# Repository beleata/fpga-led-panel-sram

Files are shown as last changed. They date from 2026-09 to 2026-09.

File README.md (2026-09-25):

# ICND1065L LED Panel: FPGA SRAM and RP2040 Pico

64x32 ICND1065L RGB LED panel drivers: Olimex iCE40HX1K FPGA with SRAM video
memory, and a YD-RP2040 / Raspberry Pi Pico PIO + DMA display implementation
with USB frame streaming. Wiring, initialization protocol, source, tests and
ready-to-flash firmware are included.

## Custom Controller PCB (Draft)

Самостоятелна двуслойна платка **88 x 46.1 mm** с RP2040, 8 MiB flash,
вертикална USB-C, RS-485 и W5500 Ethernet с вертикална RJ45.

**НЕ Е ГОТОВА ЗА ПРОИЗВОДСТВО.** Публикувани са схемата, 103 компонента,
ръчната подредба и пробно трасиране. След корекциите: 0 DRC нарушения,
но остава 1 неопроводена връзка QSPI_D1. Сигналната цялост и захранването
още не са квалифицирани. Това не променя статуса на работещия Pico модул.

- [PCB files, current status and documentation](hardware/pico-panel/README.md)
- [Пробно трасиране и ограничения](hardware/pico-panel/routing-trial/README_BG.md)

## RP2040 Pico

Потвърден работещ вариант с **YD-RP2040 2022-V1.3, 8 MiB flash**:
правилна геометрична фигура и стабилна картина. PIO и DMA изпълняват
проверената FPGA последователност при SCLK **1.5625 MHz**.

- [Свързване, компилиране и инструкции](pico/README_BG.md)
- [Готов firmware за YD-RP2040 8 MiB](pico/pico_panel.uf2)
- [Изходен код и тестове](pico/)

Добавен е USB CDC приемник с два RGB888 буфера във вътрешната SRAM на Pico.
PC декодира GIF и изпраща кадрите; Pico пази последния кадър при спиране
на изпращането. [USB видео: инструкции и протокол](pico/USB_VIDEO_BG.md).
Новият [USB firmware](pico/pico_panel_usb.uf2) е отделен от стария статичен UF2.
Измерени са 13,49 кадъра/s при 70 последователни кадъра, без PIO/DMA грешки;
визуалната проверка на новата анимация предстои.

## FPGA SRAM

Работещ проект за **Olimex iCE40HX1K-EVB**, RGB LED панел **64 x 32** с
ICND1065L драйвери и външна SRAM видео памет. Изображенията се изпращат от
компютър през OLIMEXINO-32U4 по UART **2 Mbaud**. Два SRAM буфера, CRC16 и
проверка чрез прочит след запис пазят активната картина при недовършен или
повреден пакет. Последната приета картина се показва без допълнителен трафик.

## Потвърдено На Реален Хардуер

- Правилна геометрия, цветове и стабилна статична картина.
- Приемане и показване на изображение от външния SRAM.
- Отхвърляне на грешна CRC и непълен кадър; безопасно повторение на пакет.
- Шест различни кадъра, 18 успешни прехвърляния: **3.16 кадъра/секунда**
  през текущия USB мост. Това не е физическият максимум на UART/SRAM.
- Потребителят потвърди картината и поиска непрекъсната анимация.

Проверки, хешове и ограничения: [video/VERIFICATION.md](video/VERIFICATION.md).
SRAM е енергозависима: след изключване или FPGA reset се връща началната
геометрична фигура, а не последният изпратен потребителски кадър.

## Бърз Старт

Текущата среда е Windows/PowerShell, Python 3.13, OSS CAD Suite в
`C:\oss-cad-suite`, Arduino AVR core 1.8.8. Инсталирайте Python зависимостите:

```powershell
python -m pip install -r requirements.txt
.\video\test.ps1
.\video\build.ps1
python program_panel.py video/video.bin --port COM18
python video/send_image.py --image C:\images\picture.png --port COM18
```

Картинката е 64 x 32; `--resize` разрешава преоразмеряване, `--rotate 180`
обръща изображението. Пиновете и безопасното свързване са описани в
[video/README_BG.md](video/README_BG.md). Не свързвайте 5 V към FPGA GPIO.
OLIMEXINO трябва да използва 3.3 V логически нива. GPIO1 пин 34 **не е земя**.
`HARDWARE.md` е историческа бележка и съдържа стари предположения; водещи
са актуалната документация, `.pcf` файловете и потвърдените резултати.

Анимация и спиране след текущия кадър:

```powershell
python video/animate.py --cycles 3
.\video\start_animation.ps1
.\video\stop_animation.ps1
```

Фоновата анимация държи COM18 отворен. Спрете я преди друга команда към
платката. Изпращането на изображения не презаписва FPGA flash.

## Съдържание

| Път | Предназначение |
|---|---|
| `video/` | Текущ SRAM драйвер, UART протокол, клиенти, тестове и bitstream |
| `pico/` | Потвърден RP2040 PIO/DMA статичен драйвер, UF2, свързване и тестове |
| `panel/` | Потвърдена стабилна статична версия за възстановяване |
| `link_test/` | UART диагностика и измервания на скоростта |
| `programmer-fw/` | OLIMEXINO USB/SPI/UART програматор и готов firmware |
| `backups/` | Работещи етапи, резервни копия и хешове |
| `logs/` | Запазени резултати от синтез, програмиране и тестове |
| `reference/` | Външни източници, фиксирани като Git submodules |
| `PANEL_PROTOCOL_BG.md` | Подробен протокол за управление на ICND1065L |
| `program_panel.py` | Двоен backup read, запис, проверка и CDONE |
| `iceprog.py` | Клиент за USB протокола на програматора |

Архивите `stable-panel-20260924.zip` и `video-sram-20260924.zip` пазят
самостоятелни работещи снимки на проекта. Текущите файлове извън архивите
може да съдържат по-нови помощни скриптове и документация.

## Референтни Източници

При клониране използвайте `git clone --recurse-submodules <repository-url>`.
За вече клонирано хранилище: `git submodule update --init --recursive`.
Основният FPGA build не изисква компилация на тези референтни проекти.

- [board707/DMD_STM32](https://github.com/board707/DMD_STM32),
  commit `398ec1d8636bce866709fbe9c3f0035c90645e7a`.
- [OLIMEX/iCE40HX1K-EVB](https://github.com/OLIMEX/iCE40HX1K-EVB),
  commit `91f3b5aff50258ddb40c021a21d4fd871633fc80`.
- [kingdo9/rpi-rgb-led-matrix_pwm_experiment](https://github.com/kingdo9/rpi-rgb-led-matrix_pwm_experiment),
  commit `5da13cb3b0d38d66bb5201f03704b5bef9e4446b`.

Външните проекти запазват собствените си лицензи и авторство. Това
хранилище не добавя нов общ лиценз върху техния код или хардуерни проекти.

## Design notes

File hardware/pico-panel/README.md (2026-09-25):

# RP2040 ICND1065L Panel Controller PCB

**Development snapshot, 2026-09-25. NOT FOR MANUFACTURE.**

A custom two-layer 88 x 46.1 mm controller for the tested 64 x 32 ICND1065L
LED panel. Bare RP2040, 8 MiB flash, vertical USB-C, non-isolated RS-485,
W5500 Ethernet and a vertical HanRun HR963380AE integrated-magnetics jack.
KiCad 10.0.6 project, 103 components. The custom PCB has not been fabricated
or tested; the working YD-RP2040 module firmware is a separate result.

## Текущо състояние

- Основният `pico-panel.kicad_pcb` е последната ръчна подредба на потребителя,
  без писти. Не е презаписвана от генератора след ръчните корекции.
- `routing-trial/pico-panel.kicad_pcb` е отделно пробно трасиране със същите
  позиции и ориентации. Два слоя, 111 преходни отвора.
- Проверка на подредбата: 0 DRC нарушения, 285 неопроводени връзки.
- Проверка на пробното трасиране след локалните корекции: 0 DRC нарушения,
  **1 неопроводена връзка QSPI_D1: U2.2 към U1.55**.
- ERC на схемата: 0 нарушения. Това не заменя проверката на схемното решение.
- USB/Ethernet диференциалните трасета, земята и обратните токови пътища,
  кварцовите вериги, импулсният регулатор и защитите още изискват преглед.
- Няма производствено одобрение, Gerber release или потвърдени измервания.

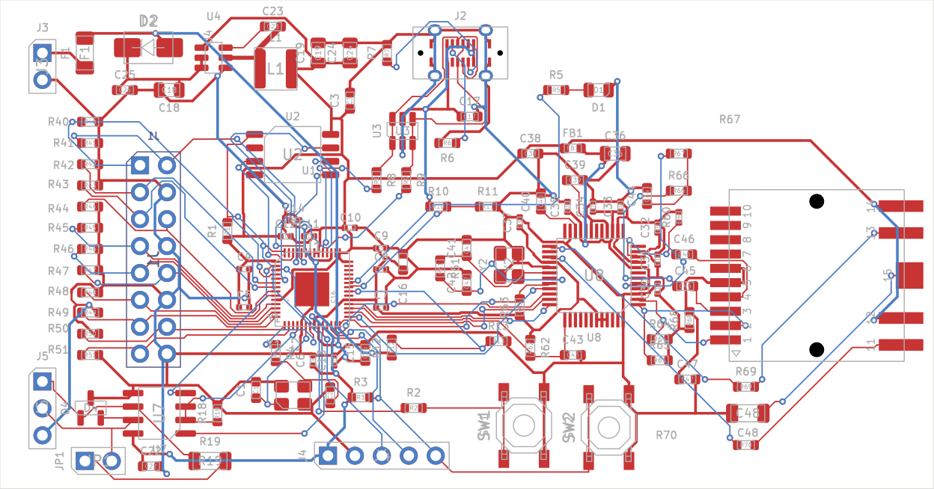
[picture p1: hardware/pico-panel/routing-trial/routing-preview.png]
Пробно трасиране, не производствен вариант


## Файлове

| Файл / папка | Предназначение |
| --- | --- |
| `pico-panel.kicad_pro` | Основен KiCad проект |
| `pico-panel.kicad_sch` | Пълна схема |
| `pico-panel.kicad_pcb` | Запазена ръчна подредба, без писти |
| `Panel.pretty/`, `Panel.kicad_sym` | Локални footprints и символи |
| `parts.json`, `BOM.csv` | Компоненти, LCSC кодове, връзки и текущи позиции |
| `preview/schematic.pdf` | Актуален PDF на схемата |
| `preview/user-placement.png` | Актуална ръчна подредба |
| `routing-trial/` | Двата опита за трасиране, логове, DSN/SES и текущ резултат |
| `reports/` | ERC/DRC, netlist, проверки на конектора и исторически отчети |
| `reference/` | Използвани datasheets, чертежи и публичен CAD на конектора |
| `tools/` | Скриптове за генериране, проверки и обработка на пробния маршрут |

## Механика и свързване

- Размер 88 x 46.1 mm; два медни слоя; зададена дебелина 0.8 mm.
- J1 е женски 2 x 8, 2.54 mm, от долната страна, за ръчно запояване.
- Поглед отгоре: J1.1 е x=13.202, y=15.600 mm от горния ляв ъгъл.
  Пин 2 е вдясно, пин 3 отдолу. Тези координати не са променяни.
- Отделни +5 V/GND проводници захранват контролера от панела.
  USB VBUS не захранва контролера; за програмиране също са нужни панелните 5 V.
- GP2..GP13 са директни 3.3 V сигнали към панела. Буферите и R20..R31 (33 ohm)
  са премахнати по заявка на потребителя; 47 kohm pull-down резисторите остават.
- J3: +5 V/GND; J5: RS-485 A/B/GND. Неполяризирани 2.54 mm конектори.
- Ethernet не е PoE. Схемата е за общата средна точка на конкретния MagJack.

## Отваряне и възпроизвеждане

Клонирайте целия repository и отворете `pico-panel.kicad_pro` с KiCad 10.
Локалните библиотеки използват `${KIPRJMOD}`. За пробния маршрут отворете
директно `routing-trial/pico-panel.kicad_pcb`; той не заменя основната подредба.

Скриптовете са от Windows работната среда. Част от тях съдържат абсолютни
пътища до KiCad, Java и локалния каталог за компоненти; адаптирайте ги преди
стартиране на друга машина. `pcbnew` изисква Python средата на KiCad.

**Не изпълнявайте `build_pcb.py` или `apply_wide_placement.py` върху ръчно
редактирана платка:** те заменят подредбата. Генераторната подредба е по-стара
от последните ръчни корекции. Авторитетен е запазеният `.kicad_pcb` файл.

`routing-trial/README_BG.md` описва границите на теста и локалните корекции.
Скриптовете за миграции/корекции са еднократни операции, не общ build pipeline.

## Документация и история

- [Проектни решения и исторически варианти](DESIGN_BG.md)
- [Проверка на RJ45 footprint](ETHERNET_FOOTPRINT_BG.md)
- [Първоначална механична Ethernet проба](ETHERNET_OPTION_BG.md)
- [Проверен firmware за готовия Pico модул](../../pico/README_BG.md)

По-старите изображения в `preview/` и част от отчетите са от предишни размери
и по-малък брой елементи. Тази страница и текущите основни KiCad файлове
определят актуалното състояние. Локалните crash snapshots, editor lock files,
временни тестови схеми и дублиращи резервни копия не са публикувани.

Изтегленият файл `ABM8-25MHz.pdf` се оказа HTML страница, а не datasheet,
и е изключен от публикацията. Документацията и товарният капацитет на 25 MHz
кварца трябва да бъдат проверени допълнително преди производство.
Datasheets/CAD в `reference/` принадлежат на съответните производители.

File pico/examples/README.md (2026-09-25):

# GIF playback examples

These three user-supplied GIFs are the inputs used for the physical panel tests.
Original authors and redistribution licenses have not been established here;
including them does not grant ownership or a new license to the artwork.

Run from the repository root after installing `requirements.txt` and flashing
`pico/pico_panel_usb.uf2` to the connected YD-RP2040:

```powershell
# Sonic: 32x64 -> 64x32, clockwise rotation, repeat until Ctrl+C
python pico/usb_video.py pico/examples/sonic-finger-ezgif.com-resize.gif --rotate 90 --fit exact --loops 0

# Stop the previous command before starting this playlist.
# Native 64x32 GIFs, alternating every 10 seconds, repeat until Ctrl+C
python pico/usb_video.py --playlist pico/examples/led_matrices_sine_tube.gif pico/examples/led_matrices_ruby_walk.gif --seconds 10 --fit exact --loops 0

# Equivalent hidden background playback on Windows
./pico/start_video.ps1 -Image pico/examples/led_matrices_sine_tube.gif,pico/examples/led_matrices_ruby_walk.gif -Rotate 0 -Seconds 10
./pico/stop_video.ps1
```

Only one sender may hold the Pico COM port at a time. Closing the sender leaves
the last frame displayed while both Pico and the panel remain powered.

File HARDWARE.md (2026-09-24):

# Хардуерна конфигурация

> **Работещ протокол, потвърден на 24.09.2026:** използвайте
> [PANEL_PROTOCOL_BG.md](PANEL_PROTOCOL_BG.md). Геометрията, цветовете и
> непрекъснатото стабилно показване вече са потвърдени на реалния панел.
> Текстът по-долу е исторически: неговите 16 scan реда, четири позиции във
> веригата и импулсно адресиране A/B не описват работещата версия.

> **Проверка от 24.09.2026:** текстът по-долу съдържа непотвърдени предположения.
> GPIO1 пин 34 е сигнал към FPGA пин 24, а не GND. Старият `panel.v` съкращава
> неправилно конфигурационната последователност и броя битове за изображението.
> Текущите проверки, източници и ограничения са описани в [panel/NOTES.md](panel/NOTES.md).

Описание на това, което е на масата: FPGA платката, как се програмира, как е
свързан LED панелът и какво знаем за него. Всичко за пиновете тук е извадено от
нетлиста на платката (`iCE40HX1K-EVB_Rev_B.net`), а не от препис — и е
проверено, че съвпада с ревизия A (`ICE40-1KEVB_Rev_A.net`).

---

## 1. Какво има на масата

| Какво | Модел | Роля |
| --- | --- | --- |
| FPGA платка | Olimex **iCE40HX1K-EVB** | самият компютър / генераторът на картина |
| Програматор | Olimex **OLIMEXINO-32U4** (ATmega32U4, Arduino Leonardo) | записва флаша, а после служи и като USB↔UART мост |
| Кабел | Olimex **CABLE-IDC10-15cm** | PGM1 ↔ UEXT между двете платки |
| Панел | **D-P5(1921)-BS-320X160-1110H** | 64×32 пиксела, драйвери ICND1065L |
| Захранване | отделно 5 V за панела | 2–3 A при пълно бяло |
| USB кабел | към OLIMEXINO-32U4 | от него излиза COM портът |

Панелът **не** се храни от FPGA платката. Земята на двете захранвания трябва да е
обща — без това сигналите няма спрямо какво да се мерят.

---

## 2. FPGA платката (iCE40HX1K-EVB)

Частите, както са в нетлиста:

| Означение | Част | Какво е |
| --- | --- | --- |
| U4 | `ICE40HX1K-VQ100` (VQFP100, 0.5 mm) | FPGA: 1280 логически клетки, 16 BRAM блока |
| U5 | `K6R4016V1D-TC10` (TSOP-44) | външна SRAM, 256K × 16 бита |
| U1 | `W25Q16BVSSIG` (SOIC-8) | конфигурационен флаш, 2 MB, по SPI |
| CR1 | `Oscillator-100MHZ_TXC-7W` | 100 MHz кварцов осцилатор |
| U2 | `SY8009AAAC` (SOT23-5) | импулсен регулатор → **3.3 V** |
| U3 | `SY8009AAAC` (SOT23-5) | импулсен регулатор → **1.2 V** (ядро) |
| GPIO1 | `BH34R` | 34-пинов конектор, 2×17 — тук излизат сигналите |
| PGM1 | `BH10S` | 10-пинов конектор за програмиране |
| LED1, LED2 | — | двете светодиодчета на платката |
| BUT1, BUT2 | — | бутони, на FPGA пинове 41 и 42 |
| CDone1 | — | светодиод за CDONE |
| PWR1, FUSE1, D1 | — | захранващ жак, предпазител, диод |

### Часовникът

Осцилаторът CR1 дава 100 MHz и отива на две места:

- през **R10** → `/SYSCLK` → **FPGA пин 15** — това е входът за такт;
- през **R18** (22 Ω) → **GPIO1 пин 6**, обозначен `EXTCLK` — същият такт излиза
  и на конектора, ако някой ден трябва да се подаде на друга платка.

В `.pcf` файловете това е `set_io CLK 15`. Проектът за компютъра работи на
100 MHz, разделени на 2 (50 MHz), защото аритметиката не затваря на 100.

### Конфигурационният флаш

Флашът U1 виси на същите SPI линии, които са и конфигурационни пинове на FPGA:

| Сигнал | FPGA пин |
| --- | --- |
| CDONE | 43 |
| CRESET | 44 |
| SDO (изход от FPGA) | 45 |
| SDI (вход към FPGA) | 46 |
| SCK | 48 |
| SS_B | 49 |

Тези пинове са заети от конфигурационната логика и **не могат да се ползват като
обикновени изходи** — проверено на практика: линията остава високоомна.

### Външната SRAM

| Сигнал | FPGA пинове |
| --- | --- |
| данни | 62, 63, 64, 65, 66, 68, 69, 71 |
| адрес | 79, 80, 81, 82, 83, 85, 86, 87, 89, 90, 91, 93, 94, 95, 96, 97, 99, 100 |
| `/WE` | 73 |
| `/OE` | 74 |
| `/CS` | 78 |

Чипът е 16-битов, но само долният байт (`SD0`–`SD7`) е изведен. Компютърът
използва точно тези осем линии.

---

## 3. Програматорът

**Това не е JTAG.** iCE40HX1K няма JTAG интерфейс. Конфигурира се по SPI: или
сам от флаша, или отвън, като външният програматор говори по SPI към флаша през
конфигурационната логика на FPGA.

Схемата е: компютърът → USB → **OLIMEXINO-32U4** → UEXT → `CABLE-IDC10-15cm` →
**PGM1** на iCE40 платката. ATmega32U4 работи като SPI master, а протоколът по
USB е мой собствен (SLIP-подобни кадри), реализиран във firmware-а на
OLIMEXINO-то.

### PGM1 (10 пина)

| Пин | Сигнал | Към |
| --- | --- | --- |
| 1 | +3.3 V | — |
| 2 | GND | — |
| 3 | RxD | джъмпер `RxD_E1` → **FPGA пин 36** |
| 4 | TxD | джъмпер `TxD_E1` → **FPGA пин 37** |
| 5 | CDONE | FPGA пин 43 |
| 6 | CRESET | FPGA пин 44 |
| 7 | SDI | FPGA пин 46 (и флашът) |
| 8 | SDO | FPGA пин 45 (и флашът) |
| 9 | SCK | FPGA пин 48 (и флашът) |
| 10 | SS_B | FPGA пин 49 |

Земята минава през IDC кабела — тя е общата земя между двете платки.

### Защо протоколът има ENTER и EXIT

SPI-то на PGM1 стига до флаша само докато FPGA е държан в reset: иначе
конфигурационната логика е поела линиите. Затова `ENTER` дърпа CRESET, чак тогава
може да се чете и пише флашът, а `EXIT` пуска FPGA да стартира от записаното.

### Firmware и клиент

- Firmware: `iCE40HX1K-EVB/programmer/olimexino-32u4 firmware/` — оригиналният
  `iceprog.ino` на Olimex плюс моят вариант с поправено парсване на кадрите.
  Качва се през Arduino IDE или PlatformIO.
- Клиент от страната на компютъра: `iceprog.py` (id / erase / write / read) и
  `verify_flash.py` (чете обратно и сравнява байт по байт).
- Портът е USB CDC и **номерът се сменя при всяко превключване**: сега е
  **COM18** („Arduino Leonardo“). Ако скриптът не намери платката — първо провери
  номера.
- Превключвателят на OLIMEXINO-32U4 трябва да е на **3.3 V**.
- За да служи платката като USB↔UART мост (конзолата на компютъра), се влиза в
  USB-Serial режим с **BUT, задържан след RST**; за програмиране — **RST без BUT**.

### Протокол (за справка)

```
хост -> платка : FEND CMD <escape-нати данни> FCS FEND
платка -> хост : FEND CMD <escape-нати данни> FCS FEND
FCS = 0xFF - (сумата на CMD + данните)
```

| Команда | Код | Отговор |
| --- | --- | --- |
| PING | 0xF0 | PONG |
| ENTER | 0xEE | READY (или ERROR, ако CDONE не е паднал) |
| EXIT | 0xEF | READY |
| READ_ID | 0x9F | производител, памет, капацитет |
| BULK_ERASE | 0xC7 | READY |
| PROG | 0x02 + адрес + до 256 байта | READY |
| READ | 0x03 + адрес | 256 байта |
| STATUS | 0xF7 | CDONE, RESET, MISO |
| SAMPLE | 0xF3 | нивата на избрана линия |
| UART1 | 0xF8 + милисекунди (2 байта) | получените байтове от FPGA-то |
| SEND1 | 0xF9 + байтове | изпраща ги към FPGA-то |

---

## 4. GPIO1 — пълната таблица

Пинове 1–4 са захранване, оттам нататък сигналите вървят по двата реда: нечетните
(5, 7, 9, … 33) от едната страна, четните (6, 8, … 34) от другата.

| GPIO1 | Какво | FPGA пин |
| --- | --- | --- |
| 1 | +5 V | — |
| 2 | GND | — |
| 3 | +3.3 V | — |
| 4 | GND | — |
| 5 | PIO3_1A | 1 |
| 6 | **EXTCLK** (100 MHz през 22 Ω) | 15 |
| 7 | PIO3_1B | 2 |
| 8 | GND | — |
| 9 | PIO3_2A | 3 |
| 10 | LED1 | 40 |
| 11 | PIO3_2B | 4 |
| 12 | LED2 | 51 |
| 13 | PIO3_3A | 7 |
| 14 | PIO2_9/TxD | 37 |
| 15 | PIO3_3B | 8 |
| 16 | PIO2_8/RxD | 36 |
| 17 | PIO3_5A | 9 |
| 18 | PIO2_7 | 34 |
| 19 | PIO3_5B | 10 |
| 20 | PIO2_6 | 33 |
| 21 | PIO3_6A | 12 |
| 22 | PIO2_5 | 30 |
| 23 | PIO3_6B | 13 |
| 24 | PIO2_4 | 29 |
| 25 | PIO3_7B | 16 |
| 26 | PIO2_3 | 28 |
| 27 | PIO3_8A | 18 |
| 28 | PIO2_2 | 27 |
| 29 | PIO3_8B | 19 |
| 30 | PIO2_1 | 26 |
| 31 | PIO3_10A | 20 |
| 32 | PIO3_12B | 25 |
| 33 | PIO3_10B | 21 |
| 34 | PIO3_12A | 24 |

> **Бележка за по-стария текст.** В `README.md` стоеше твърдение, че схемата и
> `gpio1-pcf/GPIO1-VQ100.txt` се разминават за пинове 3–13. Нетлистът (и на
> ревизия A, и на ревизия B) показва, че **не се разминават** — трите източника
> (нетлист, текстовият файл, `iCE40HX1K-EVB.pcf` на Olimex) съвпадат за всички
> пинове, които използваме. Проверката с търсене по половината пинове също
> потвърди: D0 = FPGA пин 7, D1 = FPGA пин 37.

---

## 5. LED панелът

### Какво е

- Модел от ситопечата на самата платка: **`D-P5(1921)-BS-320X160-1110H`**.
  `P5` значи стъпка 5 mm, `320X160` са милиметрите на модула: **64 × 32 пиксела**.
- Драйвери: **ICND1065L** (Chipone) — 16-канален S-PWM драйвер. Потвърдено от
  Наско по надписа на чипа.
- На гърба има **два** 16-пинови HUB75 конектора — вход и изход, за верига от
  модули. Ползва се входният; на изходния нищо не излиза.

### Защо този панел не е „прост панел“

Обикновеният HUB75 панел е шифт регистър с дешифратор за редовете и никаква
памет: показва това, което му е вкарано и заклещено. Този не е такъв. ICND1065L
има собствен генератор, собствен PWM за яркостта и собствена логика за редовете,
и **след включване изходите му са изключени**. Докато не му се запишат регистрите
през самите RGB линии, светодиодите стоят тъмни, колкото и правилен да е
пикселовият тайминг. Точно това беше причината старият тестов образец да даде
нула.

### Конекторът на панела

Стандартният 16-пинов HUB75 ред, както е надписан на платката на панела:

| Пин | Сигнал | Пин | Сигнал |
| --- | --- | --- | --- |
| 1 | R1 | 9 | A |
| 2 | G1 | 10 | B |
| 3 | B1 | 11 | C |
| 4 | GND | 12 | GND |
| 5 | R2 | 13 | CLK |
| 6 | G2 | 14 | LAT |
| 7 | B2 | 15 | OE |
| 8 | GND | 16 | GND |

Пин 12 е земя, а не `D` — тоест панелът **не чака двоичен адрес на редовете**.
При 64×32 с шест информационни линии редът се избира вътре във веригата драйвери,
а той се мести с импулси по A и B. Затова в дизайна A и B носят импулси, а не
двоичен код.

### Окабеляване (FPGA → GPIO1 → панел)

| Сигнал | FPGA пин | GPIO1 пин | HUB75 пин |
| --- | --- | --- | --- |
| R1 | 3 | 9 | 1 |
| G1 | 4 | 11 | 2 |
| B1 | 8 | 15 | 3 |
| R2 | 9 | 17 | 5 |
| G2 | 10 | 19 | 6 |
| B2 | 12 | 21 | 7 |
| A | 13 | 23 | 9 |
| B | 16 | 25 | 10 |
| C | 18 | 27 | 11 |
| SCLK | 19 | 29 | 13 |
| LAT | 20 | 31 | 14 |
| OE | 21 | 33 | 15 |
| GND | — | 2, 4 или 8 | 4, 8, 12, 16 |

Всичките дванайсет сигнала са на нечетния ред на GPIO1, от пин 9 до пин 33 —
подредени по ред, което прави грешката при свързване видима. Пинове 5 и 7 са
умишлено пропуснати: те са в непосредствена близост до 100 MHz такта и Olimex
предупреждава за претоварване.

Пет волта за панела идват от отделно захранване, а земята му се съединява със
земята на FPGA платката.

Нивата са 3.3 V и това е достатъчно — общността около `rpi-rgb-led-matrix`
управлява такива панели директно от 3.3-волтовите пинове на Raspberry Pi.

### Какво знаем за протокола на ICND1065L

Извадено е от работеща реализация (SPWM форкът на `rpi-rgb-led-matrix`, профил
`icnd1065l`) и е пресметнато за нашата геометрия: 64 колони, 16 канала на чип →
4 чипа по верига, 16 scan реда. Пълният разбор е в началото на `panel/panel.v`.

**Начален скрипт (изпълнява се веднъж след включване):**

1. LAT високо, 3 такта; после 12 такта с LAT ниско.
2. LAT високо, 11 такта; после 3 такта с LAT ниско.
3. LAT високо, 14 такта; после 9 такта с LAT ниско.
   (RGB линиите стоят ниско през цялото време.)
4. Регистър 1: `0x00AA`, по една дума на чип — 4 думи, 64 такта, MSB пръв.
5. Регистър 2: `0x01AA`, същото.
6. Регистър 3: четирите RGB думи `0x0000, 0x026A, 0x0322, 0x0412`.
7. Регистър 4: `0x0055`, регистър 5: `0x0155`.
8. Дванайсет такта с отворен изходен прозорец.

Форматът на една дума: 16 бита, MSB пръв; данните се сменят при ниско ниво на
такта, панелът чете при високо; LAT се вдига 5 такта преди края на блока.
Двойките `0xAA`/`0x55` са точно това, което разрешава изходите на драйвера — без
тях панелът е черен.

**Кадри:** 16 пъти по един период от 64 такта с данни (всички единици = бяло),
LAT на последния такт, импулс за разрешаване на изхода вътре в периода и
импулсите за реда по A (2 такта) и B (4 такта), като при завъртане от последния
ред към нулевия C носи същия широк импулс.

---

## 6. Конзолата (UART)

Освен програматора, OLIMEXINO-32U4 служи и като USB↔UART мост за серийната
конзола на FPGA дизайна. Два отделни проводника:

| Посока | FPGA | GPIO1 | OLIMEXINO-32U4 |
| --- | --- | --- | --- |
| FPGA → PC | пин 7 | 13 | D0 (RXD1, хардуерен USART) |
| PC → FPGA | пин 37 | 14 | D1 (TXD1) |

Скоростта е 4800 baud — умишлено бавно, защото минава по къс неекраниран кабел:
9600 работи, но с редки грешки.

Посоката PC → FPGA може да мине и през самия IDC кабел (PGM1 пин 4 = TxD →
джъмпер `TxD_E1` → FPGA пин 37), но обратната не може: FPGA пин 7 не стига до
PGM1, той излиза само на GPIO1. Затова са двата проводника.

---

## 7. Какво още не е проверено

- Полярността на изхода за разрешаване на панела. Документацията не я решава
  еднозначно, затова дизайнът ги пробва и четирите четения на този пин, по 8
  секунди, и маркира кое е активно с LED1 на FPGA платката.
- Дали транспортът на редовете наистина е шифт регистър. Отсъствието на линия D
  на конектора сочи натам, но не е доказано на практика.
- Токът, който панелът дърпа, и дали захранването му стига при пълно бяло.
- Надписите на конектора на панела са четени от снимка — ако на платката пише
  друго, таблицата по-горе подлежи на поправка.

---

## 8. Кратки команди

```powershell
# синтез и подреждане (панелът работи на 50 MHz)
powershell -ExecutionPolicy Bypass -File build.ps1 -Top panel -Src panel.v -Pcf panel.pcf -Freq 50

# запис във флаша
python iceprog.py -p COM18 write panel/panel.bin

# проверка какво е записано и че FPGA се е конфигурирало
python verify_flash.py -p COM18 panel/panel.bin

# терминал към BASIC компютъра
python basic_term.py -p COM18
```

`.pcf` файловете са единственото място, където се задават пиновете:
`panel/panel.pcf` за панела, `computer/computer.pcf` за компютъра.

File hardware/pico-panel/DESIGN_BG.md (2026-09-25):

# RP2040 Panel Controller Rev A

Статус: проект в разработка, НЕ ЗА ПРОИЗВОДСТВО. Текуща подредба: 103 елемента,
88 x 46.1 mm, два медни слоя, без писти. Предстои ръчен преглед от потребителя.
Текущата ръчна подредба е в preview/user-placement.png. README.md описва
актуалното състояние и пробното трасиране; по-долу са запазени и исторически варианти.

## Потвърдени изисквания, 25.09.2026

- Самостоятелен RP2040 чип, не готов Pico модул.
- ICND1065L панел 64x32; запазени GP2..GP13 от работещия firmware.
- Платка 88 x 46.1 mm: удължена надясно от първоначалните 57.8 mm по заявка
  на потребителя. Левият ръб и всички координати на J1 остават непроменени.
- Поглед отгоре: център J1.1 на x=13.202, y=15.600 mm от горния ляв ъгъл.
- Женски J1 отдолу, 2x8, стъпка 2.54 mm по двете оси, ръчен монтаж.
- Пин 2 е вдясно от 1 при поглед отгоре; пин 3 е под 1.
- Пин 15 е на x=13.202, y=33.380 mm; пин 16 на x=15.742, y=33.380 mm.
- Отделни два проводника за +5 V и GND от стабилизираното захранване на панела.
- Вертикална USB-C букса SHOU HAN TYPE-C 16PLT-H6.5, C3151748, висока 6.5 mm;
  кабелът влиза отгоре. Собственият footprint е по чертежа на производителя,
  страница 2 от reference/C3151748.pdf: 16 SMT пада, 4 метализирани слота
  0.85 x 0.60 mm и 2 неметализирани отвора 0.52 mm.
- Дебелина на PCB 0.8 mm според препоръката за буксата. Двата медни слоя
  остават. USB трасетата трябва да се изчислят за този stackup, а не за 1 mm.

## Електрическо решение

- RP2040, 8 MiB W25Q64JVSSIQ flash, препоръчаният 12 MHz ABM8-272-T3.
- 3.3 V AP63203WU-7 импулсен регулатор; вътрешен 1.1 V регулатор на RP2040.
- Контролерът се захранва само от панелните 5 V. USB VBUS служи за
  детекция и ESD веригата, но не захранва контролера. За USB програмиране
  също се включват панелните 5 V. Това премахва USB захранването на GPIO
  изходите при изключено общо захранване на панела.
- Предпазител и последователен диод на положителния вход,
  отделни развързващи кондензатори при всеки захранващ извод.
- Директни 3.3 V GPIO изходи без последователни резистори R20-R31, без
  буфери и без транзисторна enable схема. Това е потвърденото работещо
  свързване за конкретния панел, не гаранция за всички HUB75 панели.
  R20-R31 са премахнати по заявка на потребителя. Новата PCB още не е изпитана.
- 47 kohm pull-down резистори задават ниски нива по сигналите при reset.
  Firmware трябва да изпълни проверената инициализация на ICND1065L.
  GP14 е свободен; GP23 следи панелното захранване.
- Диодът НЕ е пълна защита от разменен плюс и минус: HUB75 също свързва
  земите. Проверява се полярността преди включване. Не се свързват
  панелът или сигналите при включено захранване.
- GP0=UART TX, GP1=UART RX, GP15=RS485 DE и /RE. По подразбиране приемане.
- SN65HVD75DR, SM712 защита, 120 ohm терминатор с джъмпер.
- RS-485 е НЕИЗОЛИРАН, A/B/GND. Подходящостта за дълги външни кабели,
  различни заземявания и импулсни смущения не е потвърдена.
- USB CC1/CC2 с отделни 5.1 kohm резистори; 27 ohm последователни резистори
  при RP2040; ESD защита при USB буксата.
- BOOTSEL, RESET, SWD и статусен LED GP25.
- ЗАДЪЛЖИТЕЛНО два медни слоя, по изрично изискване на потребителя.
  Всички SMD елементи отгоре, J1 отдолу. Долният слой приоритетно е земя;
  USB трасетата трябва да имат непрекъснат обратен токов път под тях.

## Преди производство

Потребителят потвърди липса на механични препятствия под платката.
Да се провери окончателната сглобка с избрания вертикален USB корпус.
Чертежът не задава монтажни отвори; не са измисляни такива.
Не са потвърдени изисквания за галванична изолация, дължина на RS-485 кабела,
околна температура или външен монтаж.

Нужни са чисти ERC, DRC и проверка на нетлиста, окончателно разположение,
преглед на USB импеданса спрямо избрания JLCPCB stackup и проверка на BOM/CPL.
След това: прототип, измерване на напреженията с ограничен ток, USB boot,
RS-485 тест и реален панел. Чист DRC не доказва електрическа работоспособност.

След премахването на буферите: 77 компонента; ERC 0 нарушения; проверени
12 директни сигнални вериги, отделянето на USB VBUS от SYS_5V и всички
16 координати на J1. Няма застъпени компонентни courtyard зони.
По искане на потребителя работата спира на разположението за одобрение;
preview/placement-review.png е изгледът отгоре за преглед. Няма трасета.
Вариант 2 премества целия RS-485 блок долу вляво: J5, U7, C22, R18,
D4, R19 и JP1. SWD J4 е долу вдясно. Габаритът и J1 не са променени.
Разрешени са 0 ohm SMD мостчета при необходимост от пресичане на сигнали.
Точният брой, корпус и места се определят при трасирането; засега не са
добавени произволни мостчета в схемата или BOM. Всяко добавено мостче трябва
да присъства в схемата, нетлиста, PCB и BOM, с две отделни мрежи от двете
страни. Не се използват за замяна на непрекъсната земя под USB, в USB
двойката или в кварцовите връзки. Долните медни полигони остават важни.
Старите routing резултати и изображения с буфери
са отделени в подпапки obsolete-buffer-design и не бива да се използват.
PDF preview/schematic.pdf е от предишната ревизия на USB и не е актуален.
Актуална е pico-panel.kicad_sch. Скриптът route.py critical има предпазна
проверка срещу използване на старите USB трасета с новия вертикален корпус.

## Компактни конектори, вариант 3

J3 и J5 вече са вертикални едноредови пинови конектори на стъпка 2.54 mm,
като диагностичния J4. Това са ръчно монтирани компоненти; конкретният
производител и насрещният кабелен конектор още не са избрани.

| Конектор | Корпус | Пин 1 | Пин 2 | Пин 3 |
| --- | --- | --- | --- | --- |
| J3 | 1x2, 2.54 mm | +5 V от панела | GND | - |
| J5 | 1x3, 2.54 mm | RS485 A | RS485 B | GND |

Гледано отгоре, пин 1 е горният квадратен пад. Двата конектора са вляво;
J3 пин 1 е (4, 6) mm, J5 пин 1 е (4, 38) mm. Панелният J1 не е местен.
Общата courtyard площ на J3/J5 намалява от 291.87 на 52.08 mm2,
приблизително 240 mm2 освободена монтажна площ, не гарантирана площ за трасета.

Захранва се само контролерът, не LED панелът. За J3 и насрещния конектор
изискваме поне 1 A допустим ток на контакт; конкретният модел и кабелът
трябва да се проверят. Самата стъпка не гарантира токова товароносимост.
Като пример, спецификацията Samtec TSW/SSW за 2.54 mm дава 4.7 A при
един натоварен пин на ред; това НЕ е рейтинг за произволен евтин конектор.
https://suddendocs.samtec.com/productspecs/tsw-ssw.pdf

Тези неполяризирани конектори изискват внимателна проверка на +5 V/GND;
при избор на заключващ/поляризиран корпус трябва да се актуализира footprint.
Добавянето на Ethernet изисква отделна проверка на общия ток, PTC и
разсейването на 3.3 V регулатора. Тази проверка още не е завършена.

Проверки след промяната: ERC 0; DRC 0 нарушения и 196 неопроводени връзки;
няма courtyard застъпвания или корпуси извън платката. Всички 16 координати
на J1 са проверени. Това е неопроводена платка, не готов производствен проект.
Предишното състояние е запазено в preview/before-compact-connectors/.

## Разположение, вариант 4

По искане на потребителя RS-485 блокът е приближен към J5. U7 е на
(12.5, 38.5) mm, преместени са и C22, R18, D4, R19, JP1. Конекторите J5
и J1 остават на същите места. Промяната е и в основната платка, и в
механичната Ethernet проба. Схемните връзки не се променят.
В пробата десният край на RS-485 courtyard зоните вече е x=20.82 mm,
а левият край на W5500 е x=28.85 mm: 8.03 mm хоризонтално отстояние.
Това е резерв за разполагане/трасиране, не доказана опроводимост.
Предишното състояние е в preview/before-rs485-tight-group/.

Сегашният Pico UF2 не приема RS-485 кадри. За тази функция ще е нужен
отделен firmware build; не променяме работещото Pico на масата.

## Източници

- https://datasheets.raspberrypi.com/rp2040/hardware-design-with-rp2040.pdf
- https://datasheets.raspberrypi.com/rp2040/rp2040-datasheet.pdf
- https://abracon.com/datasheets/ABM8-272-T3.pdf
- https://www.ti.com/lit/ds/symlink/sn65hvd75.pdf
- https://jlcpcb.com/partdetail/TexasInstruments-SN65HVD75DR/C57928
- https://jlcpcb.com/partdetail/WinbondElec-W25Q64JVSSIQ/C179171

LCSC номерата се проверяват чрез локалната база на kicad-jlcpcb-tools и
страниците на доставчика. Наличностите от локалната база са моментна снимка,
не обещание за наличност при поръчка. Конкретните корпуси се сверяват с datasheet.

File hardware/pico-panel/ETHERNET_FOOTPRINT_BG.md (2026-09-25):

# RJ45 HR963380AE: площадки и проверка

Локален KiCad footprint: `Panel:RJ45_HanRun_HR963380AE_Vertical`.
Файл: `Panel.pretty/RJ45_HanRun_HR963380AE_Vertical.kicad_mod`.
Генератор и автоматична проверка: `tools/build_ethernet_footprint.py`.

## Ориентация и размери

Поглед отгоре, откъм елементите, както в Recommended PCB Layout,
страница 3 от заводския PDF Rev.00. Началото (0,0) е средата между
двата позициониращи отвора. Положителната ос Y е надолу.

| Площадки | X, mm | Y, mm | Размер, mm |
| --- | --- | --- | --- |
| 1 до 10 | от +6.075 до -6.075, стъпка 1.35 | +8.60 | 0.85 x 2.90 |
| 11 | +6.55 | -7.95 | 1.10 x 4.20 |
| 12 | +4.01 | -7.95 | 1.10 x 4.20 |
| 13 | -4.01 | -7.95 | 1.10 x 4.20 |
| 14 | -6.55 | -7.95 | 1.10 x 4.20 |
| 15, метален корпус | 0 | -8.75 | 2.50 x 2.60 |
| Два NPTH отвора | -7.00 и +7.00 | 0 | диаметър 1.40 |

Площадки 1-10 са връзките към трансформаторите; 11-14 са LED изводите.
Номер 15 за корпуса следва библиотеката на доставчика; на заводския
монтажен чертеж централната площадка няма напечатан номер.
Отворите са неметализирани, не електрически падове и не монтажни винтове.
Всички 15 медни площадки са SMT с F.Cu/F.Paste/F.Mask.

Номиналният контур на корпуса е 16.2 x 16.5 mm. Courtyard е
17.2 x 21.1 mm и обхваща крайните площадки с 0.5 mm резерв.
В пробната платка J6 е на (48.6,35.1) mm, без завъртане. Най-долната
площадка завършва на y=45.15 mm: 0.95 mm до долния ръб на платката.

## Разлика в заводския чертеж

На страница 3 са дадени едновременно отстояние на долния край 10.05 mm,
височина на площадките 2.90 mm и координата на осовата линия 8.55 mm.
Първите два размера дават 10.05 - 2.90/2 = 8.60 mm, не 8.55 mm.
Избрано е 8.60 mm: точно това използва публикуваният от LCSC EasyEDA
footprint за C19724763. Разликата от 0.05 mm е документирана, не премълчана.
Преди производствено освобождаване е необходима окончателна механична
проверка по мостра или потвърден актуален чертеж на доставчика.

Автоматичната проверка сравнява координатите, размерите и номерата на
всички 15 площадки, както и двата отвора, с изтегления библиотечен модел.
Максималната разлика е под 0.001 mm и е от числовото закръгляване.
Отделно KiCad зарежда генерирания footprint и проверява обратно геометрията.
Резултат: `reports/ethernet-footprint.json`.

## Граница на готовност

Площадките са реални KiCad падове, а не нарисувани правоъгълници в картинката.
Използвани са в `preview/ethernet-mechanical.kicad_pcb`. Основният PCB и
неговата схема не са променяни от тази операция. J6 и U8 в пробата още
нямат схемни мрежи; Ethernet схемата, кварцът, пасивните елементи,
захранването и трасетата предстоят. Това НЕ е производствено освобождаване.

## Източници

- HanRun PDF, страници 2-3: `reference/HR963380AE.pdf`.
- https://wmsc.lcsc.com/wmsc/upload/file/pdf/v2/lcsc/2312221758_HANRUN-Zhongshan-HanRun-Elec-HR963380AE_C19724763.pdf
- https://jlcpcb.com/partdetail/21045354-HR963380AE/C19724763
- https://easyeda.com/api/products/C19724763/components?version=6.4.19.5
- Архивираният отговор е `reference/HR963380AE-easyeda.json`;
  footprint UUID: `b633f41d663444f8849f9de977d45e24`.

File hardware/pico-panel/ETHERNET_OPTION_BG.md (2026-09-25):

# Ethernet: вертикален кандидат, механична проба

Историческа механична проба за първоначалния размер. Текущият основен проект
вече съдържа W5500 и пасивните му елементи и е разширен до 88 x 46.1 mm.
За текущото състояние виж DESIGN_BG.md и основния pico-panel.kicad_pcb.

Статус: избор на компонент и проверка на габаритите. НЕ Е готова схема,
НЕ Е пълно разположение на Ethernet елементите и НЕ Е производствен файл.
Основните pico-panel.kicad_sch / pico-panel.kicad_pcb / parts.json не са
променени от тази проба. Двата слоя и размерите 57.8 x 46.1 mm остават.

## Кандидат за J6

HanRun HR963380AE, JLCPCB C19724763. Вертикална RJ45 с вградени магнитни
елементи и зелен/оранжев LED. Производителят дава 100/1000BASE-T,
трансформатори 1CT:1CT, OCL >=350 uH и изолация 2250 VDC при описания тест.
С W5500 проектът ще бъде 10/100 Ethernet, а не Gigabit.

- Корпус 16.2 x 16.5 mm; височина приблизително 16.85 mm над PCB.
- Редове на монтажните площадки: обща дълбочина около 20.1 mm.
- Чертежът и вътрешната схема са в reference/HR963380AE.pdf.
- Вътрешните center-tap изводи са общи (пинове 5/6). W5500 изисква
  адаптацията от официалната схема за connected CT, включително разделителни
  кондензатори в RX пътя. Не може да се копира сляпо схема за друга RJ45.
- Наличието на компонента в каталога не е гаранция за склад при поръчка.
- Без PoE. Захранването остава от панелните 5 V.

## Механична проба

preview/ethernet-fit.png показва J6 с реални 15 SMT площадки и два NPTH
отвора, както и LQFP-48 корпуса на W5500. Footprint-ът е направен по
заводския чертеж и сверен с библиотеката на LCSC. Подробностите и малкото
разминаване в размерната верига са в ETHERNET_FOOTPRINT_BG.md.
J6 и U8 в пробата все още нямат схемни мрежи. НЕ е проект за производство.
Пробата е върху вариант 4 с компактните J3/J5 на стъпка 2.54 mm.
RS-485 блокът (U7, C22, R18, D4, R19, JP1) е приближен към J5 вляво.
SWD, C7 и R3 са преместени във временното копие; J1 остава непокътнат.
Кварцът 25 MHz, съгласуването, защитата, развързващите елементи и измененията
по регулатора предстоят. Затова пробата НЕ потвърждава окончателна събираемост.

## Предварително разпределение на GPIO

GP16 MISO, GP17 CS, GP18 SCK, GP19 MOSI, GP20 reset, GP21 interrupt.
Тези GPIO са свободни в текущата схема. GP2..13 за панела и GP0/1/15 за
RS-485 не се променят. Firmware за Ethernet все още няма.

## Източници

- https://jlcpcb.com/partdetail/21045354-HR963380AE/C19724763
- https://wmsc.lcsc.com/wmsc/upload/file/pdf/v2/lcsc/2312221758_HANRUN-Zhongshan-HanRun-Elec-HR963380AE_C19724763.pdf
- https://docs.wiznet.io/Product/Chip/Ethernet/W5500/ref-schematic
- https://docs.wiznet.io/Design-Guide/hardware_design_guide

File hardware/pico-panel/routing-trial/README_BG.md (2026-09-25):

# Пробно трасиране върху ръчната подредба

Дата: 25.09.2026. Само проба за опроводяемост, НЕ ЗА ПРОИЗВОДСТВО.

- 88 x 46.1 mm, два слоя, 103 елемента. Координатите и ориентациите са запазени.
- Основният ../pico-panel.kicad_pcb не е променян; това е отделно копие.
- 1306 сегмента/преходни отвора общо, от които 111 преходни отвора.
- Последен KiCad DRC: 0 нарушения, 1 несвързана връзка.
- Остава QSPI_D1: U2.2 към U1.55. Без нея flash интерфейсът не е завършен.
- Няма медни полигони за земя. USB/Ethernet диференциалните трасета,
  обратните токови пътища, кварцовите вериги и импулсното захранване
  не са квалифицирани. Чистият DRC не доказва електрическата им пригодност.

## Изпълнени проверки и корекции

Freerouting 2.4.1: два ограничени опита по максимум 20 прохода, 4 нишки.
За втория опит е зададено `--router.automatic_neckdown=false` по
[официалните настройки](https://github.com/freerouting/freerouting/blob/master/docs/settings.md).
Въпреки това fanout участъци са останали с ширини 0.0952/0.125 mm.
39 такива участъка са разширени до проектния минимум 0.127 mm.
Два преходни отвора са изместени с 0.020 mm за спазване на отстоянията,
без местене на елементи. След това е изпълнен нов DRC, без нарушения.

Текущ резултат: pico-panel.kicad_pcb и drc.json.
Първи опит: first-pass.kicad_pcb и first-pass-drc.json, с нарушения.
Втори автоматичен резултат преди локалните корекции:
before-width-normalization.kicad_pcb, също с нарушения.
Логове: freerouting.log и no-neckdown.log.

Не пускайте генераторите за подредба върху ръчно редактираната платка.

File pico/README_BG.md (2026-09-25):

# ICND1065L панел с YD-RP2040

## Потвърден работещ тест

На 25.09.2026 firmware-ът е записан и проверен върху YD-RP2040
2022-V1.3 (VCC-GND Studio), RP2040 B2, 8 MiB flash.
Потребителят потвърди, че фигурата се визуализира правилно и всичко работи.
Тестът показва бяла рамка, жълт кръг, бяла стрелка и четири цветни квадрата.
Изображението идва от `../panel/pattern.hex`, както при работещия FPGA тест.

Този раздел описва първоначалния статичен тест (`pico_panel.uf2`).
Текущият изходен код вече приема кадри по USB и се компилира като версия 0.2.0.
Новият firmware е `pico_panel_usb.uf2`; инструкции, протокол и проверки:
[USB видео RAM](USB_VIDEO_BG.md). Старият UF2 остава непроменен за възстановяване.
Firmware-ът е във flash и стартира отново след включване на Pico.
Ако се рестартира само панелът, рестартирайте и Pico, за да повтори инициализацията.

## Свързване

Следвайте GPIO надписите върху платката. Физическите номера в таблицата
са по стандартната 40-пинова номерация на Pico, не номера на GPIO.

| Сигнал на панела | HUB75 пин | Pico GPIO | Физически пин |
|---|---:|---:|---:|
| R1 | 1 | GP2 | 4 |
| G1 | 2 | GP3 | 5 |
| B1 | 3 | GP4 | 6 |
| R2 | 5 | GP5 | 7 |
| G2 | 6 | GP6 | 9 |
| B2 | 7 | GP7 | 10 |
| A | 9 | GP8 | 11 |
| B | 10 | GP9 | 12 |
| C | 11 | GP10 | 14 |
| S / SCLK | 13 | GP11 | 15 |
| L / LAT | 14 | GP12 | 16 |
| OE | 15 | GP13 | 17 |
| GND | 4, 8, 12, 16 | GND | например 8, 13, 18, 23 |

OE е един сигнал; буквата C е третият адресен сигнал, не часовникът.
Панелът се захранва от отделното 5 V захранване, не през Pico.
Земите на панела, захранването и Pico трябва да са общи.
Не подавайте 5 V към GPIO. Изключвайте захранванията при промяна на кабелите.
FPGA изходите не трябва да са свързани паралелно с изходите на Pico.

## Реализация

Използва се конкретният потвърден протокол от `../panel/panel.v` и
`../PANEL_PROTOCOL_BG.md`, а не стандартен HUB75 скенер.

- Системен такт: 125 MHz, без overclock.
- PIO0: една машина извежда едновременно GP2..GP13.
- Един 16-битов образец на всеки 320 ns; SCLK е 1.5625 MHz.
- Три DMA канала изпълняват началната последователност и безкрайния scan loop.
- Вълновите форми са в SRAM, не се четат от flash по време на сканирането.
- След инициализация: 22 празни зареждания, 2 зареждания на фигурата,
  после непрекъснато сканиране на запомненото в драйверите изображение.
- Scan цикъл: 128 такта за ред, OE високо при фази 100..103;
  адресът се сменя на фаза 112, осем адреса. Hold блокът е 1024 такта.
- Пълната стартова последователност трае приблизително 0.75 s.

USB serial извежда статус веднъж в секунда. При проверката портът беше COM19:

```text
PICO_PANEL static clock=125000000 sclk=1562500 txstall=0 dma_error=00000000 hold=1
```

`txstall=0` означава, че не е отчетено спиране на PIO заради празен FIFO;
броячът отчита интервали с установено спиране, не точния брой събития.
`dma_error=00000000` е липса на грешки на канала за данни.
`hold=1` показва преминаване към постоянния scan loop.
GP25 управлява статусния LED: нормално мига, при отчетена грешка остава светнат.
USB статусът не заменя визуалната проверка на панела.

## Готов firmware

`pico_panel.uf2` е копие на проверения и записан firmware.

SHA256:

```text
5886f110ccd455d654ea0453bf2c031ea417c9bf41393d4aab4e862918e33350
```

За повторно записване: включете Pico с натиснат BOOT/BOOTSEL и копирайте
UF2 файла в появилия се RPI-RP2 диск. Буквата му може да се промени.
Платката се рестартира автоматично. Панелът трябва да е захранен при старта.
Това заменя съществуващия firmware на Pico.

## Компилиране и тестове

От корена на проекта в PowerShell:

```powershell
.\pico\test.ps1
.\pico\build.ps1
```

Локалният toolchain е инсталиран извън хранилището в
`%USERPROFILE%\.cache\pico-panel`. `build.ps1` очаква тази подредба:

- `pico-sdk`: Raspberry Pi SDK 2.3.1,
  commit `079c6f39023649b154152db30f1d781e884879bc`, с tinyusb submodule.
- `arm`: разархивиран Arm GNU Toolchain 15.2.rel1, arm-none-eabi за Windows.
- `python/cmake/data/bin/cmake.exe`: CMake 4.4.3.
- `python/bin/ninja.exe`: Ninja 1.13.2.
- `pico-sdk-tools-2.3.1-x64-win/pioasm`: официалният pioasm пакет.
- `picotool-2.3.1-x64-win/picotool`: официалният picotool пакет.

Нужен е Python в PATH. HDL сравнението използва Icarus Verilog от
`C:\oss-cad-suite\bin`. Скриптовете не инсталират автоматично зависимостите.
Избраният SDK board е `vcc-gnd_yd-rp2040_8m`.
Изходът от компилирането е `build/pico_panel.uf2` (вече USB версията).
Не презаписвайте историческия `pico_panel.uf2` с този файл; копието на
новата версия се казва `pico_panel_usb.uf2`.

Преминали проверки:

- Три Python unit теста: пинове, конфигурационни думи, сканиране и план.
- 1 164 872 образеца при нарастващ SCLK съвпадат с симулацията на оригиналния
  FPGA RTL: инициализация, празни/видими зареждания и постоянен scan loop.
- Записът с picotool е проверен чрез readback.
- Работещата платка отчита нула PIO спирания и DMA грешки при наблюдението.
- Визуално потвърждение от потребителя.

Логове: `../logs/test-pico.log`, `../logs/build-pico.log`,
`../logs/program-pico.log`.
Сравнението с RTL проверява състоянията при нарастващия фронт, не аналоговото
качество на сигналите или всички междинни фронтове.

## Локален архив на стария firmware

Преди записването е прочетена и проверена цялата 8 MiB flash:
`backups/20260925-before-panel/flash-8mb.bin`.
Предишният firmware е CircuitPython 9.2.8 за `vcc_gnd_yd_rp2040`.

SHA256 на архива:

```text
b16dd4279da91e0dd4db8f1e7873b5b14f6c00d59dd2af8d218766e3ced58dbd
```

Архивът може да съдържа лични CircuitPython файлове. Той е изключен от Git
и не трябва да се публикува. Не е част от публичното хранилище.

За възстановяване на същата 8 MiB платка, в BOOTSEL, от корена на проекта:

```powershell
$tool = "$env:USERPROFILE\.cache\pico-panel\picotool-2.3.1-x64-win\picotool\picotool.exe"
& $tool load -t bin -o 0x10000000 -v .\pico\backups\20260925-before-panel\flash-8mb.bin
& $tool reboot
```

Възстановяването заменя цялото съдържание на flash, включително текущите файлове.

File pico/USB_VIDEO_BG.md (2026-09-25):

# USB видео RAM за YD-RP2040

Версия 0.2.0, 25.09.2026. Работи със съществуващите кабели GP2..GP13
и същата инициализация на ICND1065L, без промени по платката.

## Как работи

- Два буфера RGB888 по 6144 байта във вътрешната SRAM на RP2040.
- Компютърът декодира GIF чрез Pillow, включително прозрачност и disposal.
- USB CDC пренася цели кадри, не самия GIF файл. Baud настройката не определя
  скоростта на физическия USB трансфер; няма OLIMEXINO или UART мост.
- CRC16 проверява целия кадър преди показване. Частичен/повреден пакет не
  променя активния кадър. Получаването има 1 s timeout между байтовете.
- PIO и три DMA канала поддържат сигналите независимо от USB и Python.
- Нов кадър използва провереното FPGA обновяване: 200 us gap, init0, upload,
  32768 сканиращи такта, gap, init1, втори upload, постоянно сканиране.
- Пълният framebuffer се превръща в 32768 16-битови GPIO образеца. Буферът
  за образци се променя само когато DMA не го чете. Няма CPU паузи между
  DMA блоковете; двете протоколни паузи са преднамерени.
- Яркостта запазва FPGA преобразуването: 0..254 -> 0x0000..0x00FE;
  255 -> 0x0100. Това не е калибрирана gamma корекция.

След спиране на програмата кадърът остава, докато Pico и панелът са захранени.
RAM не преживява изключване. При рестарт се показва старата геометрична фигура.
Ако Pico се захранва само от USB, изваждането на кабела го изключва.
Целият GIF не се съхранява в Pico; без компютъра анимацията не продължава.

## Пускане

От корена на проекта, с инсталирани Pillow и pyserial:

```powershell
# Статус, само когато друга програма не е отворила COM порта
python pico/usb_video.py --status

# Един цикъл; 90 означава по часовниковата стрелка
python pico/usb_video.py pico/examples/sonic-finger-ezgif.com-resize.gif --rotate 90 --fit exact

# Непрекъснато, Ctrl+C спира изпращането
python pico/usb_video.py pico/examples/sonic-finger-ezgif.com-resize.gif --rotate 90 --fit exact --loops 0

# Фонов процес без прозорец
./pico/start_video.ps1 -Image pico/examples/sonic-finger-ezgif.com-resize.gif -Rotate 90
./pico/stop_video.ps1

# Редуване на два GIF-а: по 10 секунди, непрекъснато, без завъртане
./pico/start_video.ps1 -Image pico/examples/led_matrices_sine_tube.gif,pico/examples/led_matrices_ruby_walk.gif -Rotate 0 -Seconds 10
```

Плейлистът се подава директно и с `python pico/usb_video.py --playlist първи.gif втори.gif
--seconds 10 --loops 0`. Смяната следва реално изминалото време, а не броя
повторения на GIF-а. Всеки GIF започва от първия кадър при включването си.
Не се прекъсва текущ USB пакет: границата може да се измести с времето за един кадър.

Портът се открива автоматично, ако има точно едно устройство 2E8A:000A;
може да се зададе `--port COM19`. `--fit contain` запазва пропорциите върху
черно, `exact` забранява мащабиране, `stretch` запълва целия панел.
`--preview output.gif` записва преобразувания GIF без достъп до USB.
Трите оригинални тестови GIF-а са включени непроменени в `examples/`.
Уточнение за произхода и правата върху изображенията: `examples/README.md`.

Живите логове и PID са в игнорираната директория `pico/generated/`.
Изпращачът чака потвърждение за всеки кадър. Не изхвърля кадри и не прави
автоматичен retry при липсващо потвърждение. При недостатъчна скорост анимацията
се забавя. Интервалите от GIF са цели, а не гарантирани времена на показване.

## USB протокол

Пакет: `50 56 CMD SEQ [PAYLOAD] CRC_H CRC_L`.

| Поле | Значение |
|---|---|
| 50 56 | ASCII PV |
| CMD=1 | Кадър, точно 6144 байта payload |
| CMD=2 | Статус, без payload |
| SEQ | Номер 0..255, връщан в отговора |
| CRC | CRC-16/CCITT-FALSE, polynomial 0x1021, init 0xFFFF, без final XOR |

CRC покрива CMD, SEQ и payload, без PV и без самата CRC. CRC е MSB-first.
Payload е шест равнини по 1024 байта: R1, G1, B1, R2, G2, B2.
Във всяка: `address = (scan_row * 16 + channel) * 8 + chip`.
Физическата геометрия се задава от `panel/make_pattern.py:coordinate`.

Отговорите са ASCII редове, например:

```text
PICO_VIDEO ACK seq=8 crc=dcd5 frames=7 txstall=0 dma_error=00000000
```

Възможни резултати: ACK, STATUS, CRC_ERROR, TIMEOUT. `frames` брои завършени
обновявания от последния reset. ACK е след последния DMA upload плюс 10 us
за изпразване на PIO FIFO; не е оптично потвърждение от панела.
`txstall` брои наблюдавани интервали със спиране на PIO; `dma_error` е маска
от натрупаните грешки на DMA канала за данни. Клиентът спира при ненулеви стойности.
Не изпращайте следващ пакет преди отговора. Няма защита от повторно изпълнение
на валиден пакет със същия SEQ; изпращачът не повтаря автоматично.

## Проверки и резултат

- Осем Python теста: mapping, CRC/дължини, завъртане, alpha, GIF disposal,
  конфигурация, сканиране, пинове и редуване по реално време.
- 1 164 872 стартови SCLK образеца съвпадат с оригиналната Verilog симулация.
  Това сравнение проверява стартовата форма, не целия нов runtime приемник.
- Новият firmware е записан с picotool и проверен чрез readback.
- Реален COM19: грешен CRC е отхвърлен; частичен пакет изтича и приемникът
  се възстановява; броят кадри остава непроменен и в двата случая.
- 70 последователни кадъра за 5,189 s: 13,49 кадъра/s, PIO stalls=0,
  DMA errors=0. Затваряне/отваряне на USB порта не нулира броя кадри.
- Sonic: 7 кадъра, оригинален цикъл 400 ms, 32x64 -> 64x32 след завъртане.
  При непрекъснато изпращане с времената на GIF се измерват около 13 кадъра/s;
  не се достига изцяло оригиналното темпо от средно 17,5 кадъра/s.
- Визуалното потвърждение на анимацията от потребителя още предстои.
  Нулеви цифрови грешки не доказват липса на видими артефакти.

```powershell
./pico/test.ps1
./pico/build.ps1
# Само при свързан панел: сменя изображението, не пускайте с фоновия sender
python pico/verify_usb_video.py pico/examples/sonic-finger-ezgif.com-resize.gif
```

Логове: `logs/build-pico-usb.log`, `logs/program-pico-usb.log`,
`logs/test-pico-usb-hardware.log`. Готовият нов файл е `pico_panel_usb.uf2`.
За запис: BOOTSEL и копиране на UF2; панелът трябва да е захранен при старта.
Старият `pico_panel.uf2` остава наличен за връщане към статичната фигура.

SHA256 на USB firmware:
`cfe283322812b024f7ce4e56e1fab42446c9bfc3eb83f85c0d9e7621639e9fd6`.

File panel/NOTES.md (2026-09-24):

# ICND1065L bring-up, 2026-09-24

## Current hardware image: SRAM video frame receiver

2026-09-24: `../video/video.bin` is now programmed and verified. The user
confirmed the UART-loaded SRAM image is correct and stable, without unwanted
white pixels or flicker. Two external SRAM buffers hold six 1024-byte planes;
CRC16 and per-byte write/readback checks gate a frame commit. The fixed UART
is 2 Mbaud. The host sent the first frame and received ACK in 0.323 seconds.
Bad CRC, partial-frame timeout, duplicate retry and reconnect tests all passed
on the real board without changing the displayed image. See
`../video/README_BG.md` and `../video/VERIFICATION.md` for protocol and evidence.
This original panel-only source and its preserved backup are unchanged.

## Previous hardware image: UART link diagnostic, same panel picture

After the stable panel milestone, the user requested serial video RAM, then
asked to first identify swapped UART wires and measure maximum link speed.
The preceding FPGA image was `../link_test/link_diag.bin`, which instantiates this
unchanged panel driver and adds UART autobaud/XOR echo. See
`../link_test/README_BG.md` for hashes, test results and current state.
D0/D1 were physically swapped; the user corrected them. OLIMEXINO firmware
was backed up twice and updated to `iceprog_link` with configurable baud.
Verified: 1 MiB round trip at 2 Mbaud, no wrong/missing bytes; another ten
independent retraining tests passed. Link is currently at 2 Mbaud on COM18.
The diagnostic image itself does not implement SRAM/video RAM.
The stable panel-only image below remains preserved as a recovery baseline.

## Confirmed stable baseline: uninterrupted static scan

USER CONFIRMATION, 2026-09-24: geometry and colors are correct; the display
is fully stable, with no flicker and no unwanted bright pixels. This confirms
the uninterrupted static scan test below. No new programming is needed.
The authoritative reusable Bulgarian protocol guide is
`../PANEL_PROTOCOL_BG.md`. Source, verified bitstream, documentation and logs
are preserved with their directory structure in
`../backups/stable-panel-20260924/` and `../stable-panel-20260924.zip`.
This is the preferred recovery baseline; the earlier map32 build flickers.

After confirming the geometry, the user marked five flickering white pixels
in the arrow and six unwanted yellow pixels immediately inside the upper
circle edge in the upside-down reference. The marked positions correspond
approximately to upright y=16 and y=24, both scan address 0. These are user
observations, not measured electrical waveforms.

The earlier map32 baseline repeats initialization/configuration, uploads, a
32768-clock display hold and a 200-us clock stop every approximately 32.1 ms.
Row address 0 is held throughout initialization. This suggests frame-boundary
disturbance as one possible cause; it does not exclude row timing, driver
register settings, or signal integrity.

ONE diagnostic version now sets `STATIC_HOLD=1`: after 22 initialization
uploads and two visible uploads, state 11 loops continuously. The second
visible upload allows an intervening frame-start latch. There are no further
frame resets, data latches, configuration writes, or clock pauses. The ROM,
brightness, panel clock and within-row OE/address timing are unchanged.
This is a static-image diagnostic, not a finished dynamic framebuffer driver.

Tests passed: `test_mapping.py`, `tb_panel.v`, and `tb_static_hold.v` (8192
uninterrupted scan clocks across repeated hold-counter wraps; equal dwell
and OE counts on every row; no latch/data/reinitialization). Route uses
447 logic cells and 2 RAM blocks; 50.85 MHz timing passes the 25 MHz target.
Bitstream SHA256:
`b78fb7d55cf977bcf4902dc009b04d8d9af7a3111f0af55a4674b78caf37d09f`.
Programming log: `logs/program-static-continuous.log`.
Pre-test flash backup: `backups/20260924-134756-flash-prefix.bin`.

All three observations have now been confirmed: the figure remains intact,
the arrow pixels do not flicker, and the unwanted yellow pixels are gone.
The exact internal source of the old artifacts remains unmeasured; the
successful fix is the uninterrupted hold, not a change of pixel mapping.

## Earlier baseline: correct mapping, residual flicker

On 2026-09-24 the user confirmed the physical panel exactly matches
`pattern-upside-down.png`: arrow, circle, all four colored corner markers,
and the entire white border are correctly positioned. The panel is physically
upside down. This visually confirms the candidate mapping and RGB ordering
for the static target. The previously reported slight flicker was not assessed
in this confirmation; do not claim it has been eliminated or that all grayscale
levels have been tested. Leave this known-good static test running.

Confirmed source, ROM, bitstream, constraints and build helpers are archived in
`backups/confirmed-map32-20260924/` with the successful programming log.

The user's photograph of the first static target showed intact colored markers
but a fragmented perimeter and circle. Accounting for the panel's 180-degree
orientation, the best 32x8 tile permutation (observed to original, row-major)
was [3, 1, 2, 0, 7, 5, 6, 4]. `analyze_photo.py` saved the approximate fit in
`photo-analysis.json`; 103/2048 classified pixels differ, so this is evidence
for a candidate mapping, not pixel-perfect physical validation.

Each RGB lane now maps serial columns 0..31 to x=0..31/y=8..15,
32..63 to x=0..31/y=0..7, 64..95 to x=32..63/y=8..15, and
96..127 to x=32..63/y=0..7. Lane 2 adds 16 to y.
Only `make_pattern.py` and its generated ROM changed the hardware behavior;
`panel.v`, timing, registers and brightness are unchanged.

One corrected static image was programmed and all 32768 affected bytes read
back correctly; CDONE=1. Bitstream SHA256:
`67585d59fa611daf4f84dd8c150be4e4850993ebe156254a5ed402678dc9f708`.
Log: `logs/program-static-map32.log`. Regression tests in `test_mapping.py`
passed; HDL simulation checked all 6144 channel words. Route timing passed
50.34 MHz against 25 MHz, with 441 logic cells and 2 RAM blocks.

The previous static source/ROM/binary is preserved in
`backups/static-map64-20260924-133633/`; its flash prefix was saved at
`backups/20260924-133724-flash-prefix.bin` before programming.
The intended image is unchanged. At the user's upside-down orientation it
must match `pattern-upside-down.png`: magenta/blue upper corners, green/red
lower corners, intact border and yellow circle, white arrow pointing left.
The user has now confirmed this exact result, as recorded above.
Do not flash another experiment without coordinating the next test.

## Previous test: first static mapping target

The user confirmed stable solid fields with no persistent white points, but
some individual-pixel flicker, then requested a recognizable figure. The active
test was ONE fixed image: white perimeter, yellow circle, white right arrow,
and red/green/blue/magenta corner markers. No alternating test modes.
WAIT FOR THE USER'S OBSERVATION before changing or flashing another image.

The clock, brightness, scan timing and driver register values remain those of
the stable solid test. `make_pattern.py` generates `pattern.hex` and the two
reference PNGs. The previous candidate followed DMD pattern 3 for GKGD P5 1/8:
the first 64 serial columns in each lane address its lower eight-row strip.
This physical mapping is a HYPOTHESIS until the photographed figure agrees.

Validation: a bijection covers all 2048 assumed physical coordinates; simulation
checks all 6144 grayscale channel words in the visible frame, plus register
broadcast, latch counts and all eight binary row addresses. Place-and-route uses
441/1280 logic cells and 2/16 RAM blocks; timing passes 25/100 MHz constraints.
The bitstream SHA256 is
`cc71529da34e16644321758634a731ea837f476fc5114a47131fedd259e3fb78`.
Flash readback verified all 32768 affected bytes and CDONE=1.
See `logs/program-static-pattern.log`.

Solid-test source and binary are preserved in
`backups/stable-solid-scan8-20260924-132852/`. The pre-figure flash backup is
`backups/20260924-132933-flash-prefix.bin`, identical to the stable scan-8
backup below. Rebuild ROM after any image edits with `python panel/make_pattern.py`.

## Recovery baseline: binary scan-8 solid test

The solid-field source uses SCAN=8, CHIPS=8, ROW_MODE=0. Its 32220-byte image
SHA256 is `0cefa7ab07cdbb255227598f1af3f0cb1f283cb6eb12e4d6d993c8c69d30c0a3`.
The first-light scan-16 image below is HISTORICAL and has persistent white
points and only four illuminated rows in the user's photographs.

After the user corrected a physical connection, three complete reads were
identical, CDONE=1, and the panel briefly displayed the scan-8 test without
the white points (user report). I then restored the first-light image as a
recovery step, which the user reported brought the defects back. Comparing
the preserved prefix proved that the better intermediate image was exactly
the scan-8 build, despite the earlier unreliable readback over the bad link.

The better image has now been restored from
`backups/20260924-132102-flash-prefix.bin`. All 32768 bytes were verified and
CDONE=1. See `logs/restore-improved-scan8.log`. Do not revert to scan-16 as
the default recovery image. Full physical geometry is still unconfirmed:
the user's approximate count of 24 driver ICs conflicts with the assumed
eight-chip chains. Visual improvements do not resolve that uncertainty.

Recovery for the CURRENT baseline:

```powershell
python program_panel.py backups/20260924-132102-flash-prefix.bin
```

The sections below describe the original experiment, not the current defaults.

## Observed on this machine

- Original project found at `C:\Users\user\Documents\New folder (3)\fpga`.
- Tools found at `C:\oss-cad-suite`.
- Programmer COM18 responds with JEDEC `EF 40 15`.
- First new bitstream written with `python program_panel.py panel/panel.bin`.
- All 32768 affected bytes read back correctly; CDONE=1, CRESET=1.
- UART on FPGA pin 7 returned repeated `U` at 4800 baud. Thus the new design
  is actually running, independently of the flash readback result.
- Visible panel output still requires the operator's observation.
- First backup: `backups/20260924-130648-flash-prefix.bin` (32768 bytes).
  Only those eight 4-KiB sectors were erased; the rest of flash was untouched.
  SHA256: `a0e989f3c27b0b00d7529ce7302dc18e03625cf16af6ce73d31789934944ed76`.
- Initial test image SHA256:
  `5a7233112e1aa24e5ceb7df4c31320ab26ab8ffeb151e88ea7a6c429205c7bd7`.

## Source evidence

Upstream snapshots were cloned under `reference/` and are unmodified.

- [Olimex GPIO mapping](https://github.com/OLIMEX/iCE40HX1K-EVB/blob/master/gpio1-pcf/GPIO1-VQ100.txt):
  GPIO1 pin 34 is FPGA pin 24, NOT ground. Ground is GPIO1 2, 4, or 8.
- [SPWM implementation](https://github.com/kingdo9/rpi-rgb-led-matrix_pwm_experiment/tree/5da13cb3b0d38d66bb5201f03704b5bef9e4446b/lib/spwm):
  `spwm_send_rgb_register()` repeats ONE word to every chip in a frame and
  advances to the next word in the next frame. It does not truncate the
  configuration sequence to the number of chips. Data upload is 16 bits per
  channel, latching after the final chip, for all 16 channels and every scan row.
- [DMD_STM32 driver](https://github.com/board707/DMD_STM32/blob/398ec1d8636bce866709fbe9c3f0035c90645e7a/DMD_SPWM_Driver_RP.h):
  ICN1065 defaults and `0x200 | (nRows - 1)` scan field; grayscale uses 12 bits
  in a 16-bit word, with the upper four bits zero.
- [DMD_STM32 row selection](https://github.com/board707/DMD_STM32/blob/398ec1d8636bce866709fbe9c3f0035c90645e7a/DMD_Multiplexer.cpp):
  595 transport uses A=clock, B=latch, C=serial data (one on wrap to row zero).

## First test assumptions

This is a bring-up test, not a claim of panel support. Row-driver identity,
actual scan ratio, shift-chain length, and signal integrity are not established.
The user confirmed the separate 5-V supply, signal wiring, and common ground.

- First geometry: 16 scan rows, 4 driver chips per RGB lane, 64 serial pixels.
- Row transport: A/B/C shift-register (parameter `ROW_MODE=2`).
- 25-MHz internal clock, 1.5625-MHz panel clock.
- 128-clock scan period, four-clock OE pulse at phase 100, row latch at 112,
  row clock at 114. This timing is an explicit test assumption inspired by
  the DMD separated row/PWM transport, not a captured waveform of this panel.
- The 22-word addressed sequence uses the SPWM sequence's addresses with DMD
  defaults. Registers omitted from that sequence retain their existing values.
  Compatibility of those values with this exact panel is unverified.
- Each frame sends the LAT 3/11/14 commands and AA/config/55 register blocks;
  a different addressed configuration word is broadcast on each frame.
- Pixels stay zero until all 22 words have been transmitted. Then low-level
  red/green/blue/black fields cycle, with grayscale `0x0100`.
- LED1 indicates full register traversal; LED2 is a heartbeat.
- TX emits `U` at 4800 baud through FPGA pin 7, GPIO1 pin 13.

## Verification and reproduction

From the workspace root:

```powershell
.\build.ps1
python program_panel.py panel/panel.bin
python program_panel.py panel/panel.bin --verify-only
```

Simulation (from `panel`, with OSS CAD bin/lib on PATH):

```powershell
iverilog -g2012 -DSIMULATION -s tb_panel -o tb_panel.vvp panel.v tb_panel.v
vvp tb_panel.vvp
```

Simulation passed: all 22 configuration words broadcast identically to four
chips, 16384 data clocks and 256 channel latches per frame, blanking until
configuration completes, and the `0x0100` pixel word. The test accelerates
the clock divider and hold interval, leaving protocol counts unchanged.
Initial route: 477/1280 logic cells, internal timing 47.59 MHz against 25 MHz;
input divider timing 626.57 MHz against 100 MHz. No timing exceptions used.

To restore the saved prefix using the same verified programming procedure:

```powershell
python program_panel.py backups/20260924-130648-flash-prefix.bin
```

The original HARDWARE.md is historical context. In particular, absence of D
does not establish scan ratio: an 8-scan panel can use a binary A/B/C address.
Also, 3.3-V compatibility is not established merely by other users driving
different panels from a Raspberry Pi.

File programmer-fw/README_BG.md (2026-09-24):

# OLIMEXINO: регулируема серийна връзка

На 24.09.2026 е записан `iceprog_link/iceprog_link.ino` с Arduino CLI,
платформа `arduino:avr:leonardo` / AVR core 1.8.8, с `upload --verify`.
Изходният код е копие на стария `iceprog2` плюс две диагностични команди.
Съществуващите flash команди и SLIP/FCS форматът са запазени.

HEX: `build-link/iceprog_link.ino.hex`, SHA256:
`bb7c525c9650fdedcbeb71a75a0b99a1dae4fba41bf5613ef19103e4c65e76ab`.
Компилация: 10254 bytes flash, 1744 bytes статична RAM.

Преди записа са прочетени два еднакви 32768-byte образа:
`../backups/programmer-20260924-163657/flash-read-1.bin` и `flash-read-2.bin`.
SHA256 на всеки: `c760cb3fd3da887b04448cdb0e21457ef1c57c968ab32d560b4615aa48a3461c`.
Първият опит за backup е по-къс, защото avrdude премахва trailing 0xFF;
валидният пълен backup е направен с `-A`.

В същата директория `application-28672.bin` е копие само на приложението,
без 4096-byte Caterina bootloader. При необходимост от възстановяване
използвайте този application-only файл, не пълния 32 KiB образ.
Bootloader се отваря с 1200-baud touch, както в `../link_test/backup_programmer.py`.
Avrdude за възстановяване през временния bootloader COM порт:

```text
avrdude -C <avrdude.conf> -p atmega32u4 -c avr109 -P <boot-COM> -b 57600 -D -U flash:w:<absolute-path-to-application-28672.bin>:r
```

Това е инструкция за възстановяване, не команда за ежедневна работа.
Възстановяването ще премахне новите E0/E1 команди.

## Нови команди

Командите са във външните USB SLIP кадри на `iceprog.py`, не сурови байтове
към FPGA. USB CDC се отваря на 230400 в клиентите; действителният UART baud
се избира отделно.

### 0xE0: избор и обучение

Payload: желан baud като 4-byte unsigned big-endian, 1200..2000000.
OLIMEXINO спира watcher-а, подава 20 ms break на D1, освобождава линията
за 2 ms, включва USART на зададената скорост, изпраща 0x55, чака 25 ms и
изчиства стартовите байтове от RX буфера.

Отговор 0xE0 с три байта: UBRR1H, UBRR1L, U2X (0/1).
При 16 MHz: actual_baud = 16000000 / ((U2X ? 8 : 16) * (UBRR+1)).
Някои номинални скорости се закръгляват: 460800 става 500000,
921600 става 1000000. Най-бързият делител UBRR=0, U2X=1 дава 2000000.

Тази команда е съобразена с тестовия FPGA autobaud протокол. При бъдещ
video-RAM драйвер трябва да се съгласува обучението или да се добави режим
за задаване на скорост без break/0x55.

### 0xE1: ограничен двупосочен тест

Payload: 1..48 байта. OLIMEXINO ги предава на FPGA, изчаква края на TX,
събира до същия брой върнати байтове с timeout 250 ms след flush.
Отговор 0xE1: count, следван от count байта. Клиентът проверява всеки
срещу изпратения XOR 0xA5. Размерът е под 64-byte RX ring на Arduino.

Новият `uart1_ensure()` проверява и действителните RXEN/TXEN битове, така
че WATCH -> UART не оставя USART изключен заради остарял локален флаг.
WATCH все още освобождава D0/D1 като входове; за тест отново изпратете E0.

Пинове: D0 е RX от GPIO1/13; D1 е TX към GPIO1/14. Първоначално бяха
разменени; потребителят ги размени и посоката е проверена с бавни импулси.

## Възпроизвеждане

От корена на проекта, с вече зареден `link_test/link_diag.bin`:

```powershell
python link_test/benchmark.py
python link_test/benchmark.py --rates 2000000 --bytes 1048576 --seed 15485863 --output logs/uart-2m-endurance.json
```

Тестовете мерят обмен на проверявани 48-byte пакети. Това не е проверка
за непрекъснат full-duplex поток без паузи или работа при всички възможни
кабели, смущения и температури. Полезният PC throughput включва USB и
командните паузи и е различен от UART baudrate.

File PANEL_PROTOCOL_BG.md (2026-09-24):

# Протокол за LED панел 64 x 32 с ICND1065L

Версия 1.0, 24.09.2026. Практически проверено на панела на Наско.

Това е описание на **работещата последователност от сигнали**, възпроизведена
от текущия FPGA драйвер. Не е пълна заводска спецификация на ICND1065L.
Наско потвърди правилна геометрия, правилни цветове, стабилна картина,
без примигване и без паразитно просветване при непрекъснато сканиране.

## 1. Обхват и проверена версия

| Параметър | Работеща стойност |
| --- | --- |
| Панел | 64 x 32 RGB, 2048 пиксела |
| Означение от първоначалното описание | `D-P5(1921)-BS-320X160-1110H` |
| Драйвер, по прочетения от потребителя надпис | `ICND1065L` |
| Адреси на сканиране | 8, двоични A/B/C |
| Паралелни линии за данни | R1/G1/B1 и R2/G2/B2 |
| Последователни 16-битови позиции за един канал | 8 |
| Канали на позиция | 16 |
| Тактове за целия буфер | 16384 |
| Работеща яркост на включен цветови канал | `0x0100` |
| Изключен цветови канал | `0x0000` |
| Режим за стабилна неподвижна картина | `STATIC_HOLD=1` |

`CHIPS=8` в кода означава осем последователни позиции във формата на предаване.
Това не е независимо преброяване на физическите корпуси. По-ранната оценка
„около 24 чипа“ остава непотвърдена и не бива да променя проверената геометрия.

Провереният битстрийм е `panel/panel.bin`, SHA256:

```text
b78fb7d55cf977bcf4902dc009b04d8d9af7a3111f0af55a4674b78caf37d09f
```

Източникът на точните сигнали е [panel/panel.v](panel/panel.v).
Подредбата е в [panel/make_pattern.py](panel/make_pattern.py).
Самостоятелно копие със същата структура има в
`backups/stable-panel-20260924/`; ZIP вариантът е `stable-panel-20260924.zip`.

## 2. Захранване и свързване

Панелът се захранва от отделно 5 V захранване. Земята му е обща с FPGA.
Не захранвайте панела през сигналните пинове. Изключвайте захранването при
разместване на проводници. Допустимият ток на захранването и кабелите трябва
да се определя по реалния товар; консумацията при максимално бяло не е измерена.

Работещият опит използва 3.3 V изходи на Olimex iCE40HX1K-EVB.
Това е потвърждение за тази постановка, не гаранция за електрически запас
при дълги кабели или за всички панели със същия чип. Не подавайте 5 V към FPGA I/O.

| Сигнал | FPGA пин VQ100 | GPIO1 пин | Пин на входния HUB75 според наличното описание |
| --- | ---: | ---: | ---: |
| R1 | 3 | 9 | 1 |
| G1 | 4 | 11 | 2 |
| B1 | 8 | 15 | 3 |
| R2 | 9 | 17 | 5 |
| G2 | 10 | 19 | 6 |
| B2 | 12 | 21 | 7 |
| A | 13 | 23 | 9 |
| B | 16 | 25 | 10 |
| C | 18 | 27 | 11 |
| SCLK / CLK на панела | 19 | 29 | 13 |
| LAT | 20 | 31 | 14 |
| OE | 21 | 33 | 15 |
| GND | - | 2, 4 или 8 | GND на панела; описани 4, 8, 12, 16 |

**GPIO1 пин 34 НЕ е GND: свързан е към FPGA пин 24.**
Таблицата GPIO1/FPGA съвпада с таблицата на Olimex и текущия `.pcf`.
Номерацията на HUB75 е от първоначалното описание, а не от измерване на всички
контакти. При повторно свързване проверявайте маркировките, входната страна и
пин 1 на конкретната платка; не използвайте огледално изгледа от обратната страна.

Адресът е **двоичен**, `A=bit0`, `B=bit1`, `C=bit2`.
Липсата на D не означава адресиране с изместващ регистър: за осем адреса стигат
три бита. В работещата версия `ROW_MODE=0`.

## 3. Електрически времеви режим

| Величина | Стойност |
| --- | --- |
| Осцилатор на FPGA | 100 MHz, вход FPGA пин 15 |
| Вътрешен часовник на драйвера | 25 MHz, делене на 4 |
| `HALF_TICKS` | 8 вътрешни такта |
| SCLK към панела | 1.5625 MHz |
| Един период на SCLK | 640 ns |
| Ниска / висока половина | 320 ns / 320 ns |
| Битова последователност | MSB първи, bit15 към bit0 |
| Работещ фронт за приемане на RGB и LAT | Нарастващ SCLK |

Променяйте RGB, LAT, OE и A/B/C само при нисък SCLK и ги установявайте
преди следващия нарастващ фронт. FPGA реализацията регистрира контролите
40 ns след падащия фронт; данните от синхронната ROM могат да се установят
80 ns след него. При текущия такт това оставя поне 240 ns до следващия
нарастващ фронт. Това описва реализацията, **не минималните изисквания на чипа**.

При нов драйвер консервативният примитив е: SCLK=0, установяване на останалите
линии, изчакване 320 ns, SCLK=1, изчакване 320 ns, SCLK=0.
Когато изпълнявате следващ такт, не добавяйте непредвидени паузи към този период.

OE тук е част от специалния протокол. **Не го третирайте като обикновено
активно-ниско разрешаване на светодиодите на стандартен HUB75 shift-register панел.**
Възпроизвеждайте описаните нива и тактови прозорци.

## 4. Команди и регистрова дума

### 4.1. Начални LAT последователности

В началото на всеки от стартовите цикли изпратете следните три блока.
RGB=0, OE=0, A=B=C=0 през всичките им тактове:

| Блок / FPGA state | Общо SCLK импулси | LAT=1 | LAT=0 |
| --- | ---: | ---: | ---: |
| 0 | 16 | първите 3 | следващите 13 |
| 1 | 15 | първите 11 | следващите 4 |
| 2 | 24 | първите 14 | следващите 10 |

Броевете са **точните броеве на работещия HDL**. В старото описание имаше
3+12, 11+3, 14+9, но реализацията включва още един LAT-нисък такт във всеки блок.
Не съкращавайте до старите стойности при възпроизвеждане.
Не приписваме тук недоказано вътрешно значение на всяка LAT команда.

### 4.2. Изпращане на една регистрова дума `W`

Един регистров блок има 128 такта: **8 еднакви копия на 16-битовата дума**.
На всеки такт и шестте RGB линии получават един и същ бит:

```text
for n = 0 .. 127:
    b = (W >> (15 - (n mod 16))) & 1
    R1=G1=B1=R2=G2=B2=b
    LAT = 1 само за n=123,124,125,126,127
    OE=0, A=B=C=0
    един SCLK импулс
```

LAT стои високо през последните **пет** такта на целия блок, не през пет
такта за всяка отделна дума. Няма допълнителен SCLK между регистровите блокове.

След трите LAT команди предайте пет регистрови блока в този ред:

```text
0x00AA
0x01AA
CONFIG[k]
0x0055
0x0155
```

След тях: **12 такта с OE=1**, RGB=0, LAT=0, A=B=C=0.

### 4.3. Точната конфигурационна таблица

`k` се сменя веднъж на завършен стартов цикъл. Във всеки цикъл една и съща
`CONFIG[k]` се излъчва осем пъти по всичките шест RGB линии.
**Не разпределяйте различни конфигурационни думи по отделните позиции.**

| k | CONFIG[k] | k | CONFIG[k] |
| ---: | --- | ---: | --- |
| 0 | `0x0000` | 11 | `0x1040` |
| 1 | `0x0207` | 12 | `0x1127` |
| 2 | `0x0335` | 13 | `0x1800` |
| 3 | `0x0412` | 14 | `0x1906` |
| 4 | `0x0500` | 15 | `0x1C60` |
| 5 | `0x0601` | 16 | `0x1DCA` |
| 6 | `0x0720` | 17 | `0x1E73` |
| 7 | `0x0C18` | 18 | `0x2000` |
| 8 | `0x0D01` | 19 | `0x2100` |
| 9 | `0x0E86` | 20 | `0x2300` |
| 10 | `0x0F01` | 21 | `0x74A0` |

Думата за осем адреса е `0x0200 | (8-1) = 0x0207`.
Останалите стойности са проверен набор, не таблица с разкодирани битови полета.
Не променяйте предполагаеми регистри за ток/PLL/гасене без допълнителна проверка.

## 5. Непрекъснато сканиране на редовете

Сканирането работи **едновременно с предаването на пикселни данни** и продължава
след него. Неговите `phase` и `scan_row` са отделни от адреса на качвания пиксел.
В началото на качването на всеки стартов цикъл: `phase=0`, `scan_row=0`.

За един SCLK импулс първо подайте сигналите според текущите стойности:

```text
A = scan_row bit0
B = scan_row bit1
C = scan_row bit2
OE = 1, ако 100 <= phase <= 103; иначе 0
изпълни SCLK импулса с тези стойности

след падащия фронт:
    ако phase == 111: scan_row = (scan_row + 1) mod 8
    phase = (phase + 1) mod 128
```

| Фаза, броена от 0 | OE | Двоичен адрес |
| --- | --- | --- |
| 0..99 | 0 | текущият |
| 100..103 | 1 | текущият |
| 104..111 | 0 | текущият |
| 112..127 | 0 | следващият |

При преход 127 -> 0 адресът **не се връща**; остава следващият.
Той се увеличава само при прехода 111 -> 112.
OE импулсът е 4 SCLK периода = 2.56 us. След края му до смяната на адреса
има 8 периода = 5.12 us.

В установен режим всеки адрес се задържа 128 периода = 81.92 us;
обхождането на осем адреса трае 655.36 us, приблизително 1525.88 обхождания/s.
Това е изчислена честота на **външното адресиране**, не измерена честота на
вътрешния PWM на ICND1065L и не честота на нови изображения.

## 6. Формат на пикселните данни

### 6.1. Ред на предаване

Шест цветови думи се предават паралелно, по една върху всяка RGB линия.
За един цял буфер редът е:

```text
for upload_row = 0 .. 7:
    for channel = 0 .. 15:
        for chip = 0 .. 7:
            вземи шестте 16-битови цветови думи за тази позиция
            for bit = 15 .. 0:
                подай bit от всяка дума на съответната RGB линия
                LAT = (chip == 7 и bit == 0)
                изпълни един такт чрез сканиращия примитив от раздел 5
```

LAT=1 само за **последния такт на всяка група от 128 такта**.
Следващият такт вече има LAT=0. Използвайте `upload_row` за данните,
а не моментната стойност на `scan_row` върху пиновете.

Контролни броеве:

- Една дума: 16 SCLK.
- Един канал през осем позиции: 128 SCLK, един LAT-висок такт.
- Един upload_row: 16 x 128 = 2048 SCLK.
- Цял буфер: 8 x 2048 = 16384 SCLK, 128 LAT импулса.
- Шест линии x 1024 думи = 6144 цветови думи за 2048 RGB пиксела.
- Качване при текущата честота: 10.48576 ms, без стартовите команди.

### 6.2. Яркост

Провереният тест изпраща `0x0000` за изгасено и `0x0100` за включено.
Пример: червен пиксел има R=`0x0100`, G=`0x0000`, B=`0x0000`;
бял има и трите думи `0x0100`, жълт има R/G=`0x0100`, B=`0x0000`.

Референтният DMD драйвер задава 12 бита grayscale в 16-битова дума.
Други стойности, пълната скала `0x0FFF`, гамата и максималната консумация
не са проверявани тук. **Не заменяйте включено с `0xFFFF`.**
Текущият FPGA тест има двоично включване на всеки цвят при фиксирана яркост,
не произволен 12-битов framebuffer.

## 7. Физическа подредба на пикселите

Координатите са спрямо [правилно ориентираната тестова картина](panel/pattern-expected.png):
`x=0..63` отляво надясно, `y=0..31` отгоре надолу.
Червеният квадрат е горе вляво, зеленият горе вдясно, синият долу вляво,
пурпурният долу вдясно; стрелката сочи надясно.

Поставеният на масата панел е обърнат на 180 градуса. Това е физическа
ориентация, не грешка в протокола. За така поставения панел еталонът е
[pattern-upside-down.png](panel/pattern-upside-down.png).

### 7.1. От последователна позиция към координати

`lane=0` е RGB1, `lane=1` е RGB2:

```python
s = chip * 16 + channel                 # 0..127
x = (s // 64) * 32 + s % 32
y = upload_row + (8 if (s // 32) % 2 == 0 else 0) + 16 * lane
```

| s | x | y за RGB1 | y за RGB2 |
| --- | --- | --- | --- |
| 0..31 | 0..31 | upload_row + 8 | upload_row + 24 |
| 32..63 | 0..31 | upload_row | upload_row + 16 |
| 64..95 | 32..63 | upload_row + 8 | upload_row + 24 |
| 96..127 | 32..63 | upload_row | upload_row + 16 |

Това е подредба на участъци **32 x 8**, а не на цели ленти 64 x 8.
Формулата е потвърдена с рамка, кръг, стрелка и четири цветни маркера.

### 7.2. От координати към позиция за предаване

```python
lane = y // 16
upload_row = y % 8
strip = (y % 16) // 8
s = (x // 32) * 64 + (1 - strip) * 32 + x % 32
chip = s // 16
channel = s % 16
word_index = (upload_row * 16 + channel) * 8 + chip
```

Примери за RGB1: `(0,8)` е дума 0; `(0,0)` е дума 2;
`(32,8)` е дума 4; `(32,0)` е дума 6. Не прибавяйте lane към word_index:
RGB2 се предава едновременно с RGB1 по другите три линии.

### 7.3. Локален ROM формат, различен от протокола по кабела

`pattern.hex` има 1024 шестбитови стойности, по една на ред, записана с две
шестнадесетични цифри. Битовете са:

```text
bit5 bit4 bit3 bit2 bit1 bit0
 B2   G2   R2   B1   G1   R1
```

ROM пази само флаговете за включени цветове. FPGA ги разгръща до шест
16-битови думи `0x0100`/`0x0000`. **Не изпращайте байтовете от pattern.hex
директно на панела**: това не е неговият сериен формат.

## 8. Пълна последователност от старт до стабилна картина

Това е точно работещата рецепта; не е доказано, че е най-кратката възможна.

1. Изходите започват от 0, `config_index=0`, картината е забранена.
2. За `k=0..21` изпълнете един стартов цикъл: трите LAT блока; петте
   регистрови блока с `CONFIG[k]`; 12-те OE-високи такта; качване на изцяло
   нулев буфер с едновременно сканиране; още 32768 сканиращи SCLK импулса.
3. В края на всеки такъв цикъл оставете SCLK/RGB/LAT/OE/A/B/C=0 за 200 us.
   Нулирайте фазата и адреса преди следващия цикъл. В HDL паузата е 625
   интервала по 320 ns, **не 625 SCLK импулса**.
4. След завършването на `k=21` разрешете картината. Изпълнете същия цикъл с
   `CONFIG[0]`, но вече качете изображението, сканирайте още 32768 такта
   и направете последната 200-us пауза.
5. Изпълнете още един стартов цикъл с `CONFIG[1]` и качете същото изображение.
6. След това останете завинаги в непрекъснатото сканиране от раздел 5:
   RGB=0, LAT=0, SCLK продължава, OE и A/B/C продължават по същата фаза.
   **Не започвайте нов стартов цикъл и не спирайте часовника.**

Общо: 22 нулеви качвания + 2 качвания на изображението, после постоянен показ.
Двете видими качвания оставят стартова LAT последователност между тях.
Така е проверено на хардуера; необходимостта от всяко повторение и точният
вътрешен механизъм на буфериране не са независимо разкодирани.

По време на постоянния показ броячът на `HOLD_CLOCKS` може да се завърта,
но **не трябва да нулира phase/scan_row или да създава пауза**.
Вградената памет пази картината, но FPGA продължава да подава сканиращите сигнали.
Не е проверено задържане на картина при спиране на всички входни сигнали.

### Защо това е важно

Предишният режим повтаряше целия старт/конфигурация/качване приблизително
31 пъти/s. Геометрията беше правилна, но пет бели пиксела примигваха и имаше
шест паразитно просветващи жълти пиксела. При преминаване към непрекъснатото
задържане, без промяна на геометрията, яркостта и редовите времена, потребителят
потвърди пълно изчезване на дефектите. Това е практическата поправка;
точният вътрешен механизъм на смущението не е измерен с логически анализатор.

## 9. Повторно изграждане и запис

Нужни са Windows PowerShell, Python с `Pillow` и `pyserial`, и OSS CAD Suite
с Yosys, nextpnr-ice40, icepack и Icarus Verilog. Тук OSS CAD е в
`C:\oss-cad-suite`; ако е другаде, поправете пътя в `build.ps1`.
Версиите на Python пакетите при проверката са Python 3.13.1,
Pillow 11.2.1 и pyserial 3.5.
За анализатора на старата снимка допълнително трябват NumPy/SciPy, но той
не е нужен за изграждането, тестовете по-долу или управлението на панела.

От корена на проекта или разархивирания пакет:

```powershell
# Регенериране на ROM и еталоните от pixel(x,y)
python panel/make_pattern.py
python panel/test_mapping.py

# Изграждане на новия битстрийм; това НЕ записва хардуера
.\build.ps1

# Създава резервно копие, записва, чете обратно и проверява CDONE
# ВНИМАНИЕ: панелът изгасва за времето на програмирането.
python program_panel.py panel/panel.bin --port COM18
```

При текущата система това е **SPI програмиране на конфигурационния flash**
чрез OLIMEXINO-32U4, не JTAG и не протоколът към LED панела.
Клиентът изисква вече работещия съвместим `iceprog2` firmware на програматора;
архивът не инсталира firmware на ATmega32U4 и не заменя тази предварителна настройка.
COM18 е текущият порт и може да се промени. Скриптът работи на 230400 baud,
проверява JEDEC `EF 40 15`, чете две еднакви резервни копия преди изтриване,
записва по 4 KiB сектори и проверява прочетеното. При нестабилни прочити
проверете кабелите и общата земя, не изтривайте на сляпо.

За възстановяване без нов синтез използвайте `panel/panel.bin` от стабилния
архив. Неговият SHA256 трябва да е посоченият в раздел 1. Нов синтез с друга
версия на инструментите може да има друг хеш, дори при еквивалентно поведение.
Архивът съдържа и `SHA256SUMS.json` с хешовете на включените файлове.

```powershell
Get-FileHash panel/panel.bin -Algorithm SHA256
python program_panel.py panel/panel.bin --port COM18 --verify-only
```

**Дори `--verify-only` временно държи FPGA в reset, за да прочете flash.**
Не го използвайте, ако искате текущото показване да остане непрекъснато.
Нормалният програматор вече прави пълна проверка след запис.

### Симулиране без свързан хардуер

```powershell
$env:PATH = 'C:\oss-cad-suite\bin;C:\oss-cad-suite\lib;' + $env:PATH
Set-Location panel
iverilog -g2012 -DSIMULATION -s tb_panel -o tb_panel.vvp panel.v tb_panel.v
vvp tb_panel.vvp
iverilog -g2012 -DSIMULATION -s tb_static_hold -o tb_static_hold.vvp panel.v tb_static_hold.v
vvp tb_static_hold.vvp
Set-Location ..
```

`tb_panel` проверява конфигурацията, 16384 такта и 128 latch импулса на буфер,
осемте адреса и всичките 6144 цветови думи на видимия кадър.
`tb_static_hold` проверява 24 качвания, после 8192 такта без прекъсване,
еднакво време за всеки ред, точни OE прозорци и липса на нов LAT/данни/рестарт.
Тестовете използват ускорени времена, но същите броеве на протоколните тактове.

## 10. Нови изображения и граници на потвърденото

За друга неподвижна фигура променете `pixel(x,y)` в `make_pattern.py`, генерирайте
ROM, изпълнете тестовете и изградете/запишете нов битстрийм. Стойността от
`pixel` е RGB маска: 0 черно, 1 червено, 2 зелено, 3 жълто, 4 синьо,
5 пурпурно, 6 циан, 7 бяло. Специфичният тест `test_corner_markers` е за
еталонната фигура и трябва да се актуализира при смяна на нейните маркери;
проверката на геометрията остава приложима.

**Не е реализиран входен протокол за изпращане на картини от PC към FPGA.**
Изходът TX в текущия HDL е само диагностичен UART; не приема framebuffer.

За динамична картина вече са известни форматът и адресирането, но остава
отделна задача: качване и активиране на нов буфер без смущение на сканирането.
Не приемайте `STATIC_HOLD=0` за завършен динамичен драйвер: това връща
режима, при който имаше примигване. Не е проверено, че произволен upload
по време на задържането сам активира новата картина без допълнителна команда.

Не са потвърдени: всички нива на яркост, максимален ток/яркост, верига от
няколко панела, минимални времена, максимална честота и произволна анимация.
При пренасяне на друг FPGA/MCU първо възпроизведете тази неподвижна фигура и
точния времеви режим, преди да оптимизирате.

## 11. Източници и доказателства

- Реално потвърждение от потребителя на 24.09.2026: правилна фигура и цветове;
  след непрекъснатото сканиране няма примигване или паразитно просветване.
- [Програмен отчет](logs/program-static-continuous.log): прочетени и проверени
  32768 засегнати байта, CDONE=1. Това доказва записа, не оптичното качество.
- [Текущ HDL](panel/panel.v), [пинове](panel/panel.pcf),
  [генератор на подредбата](panel/make_pattern.py),
  [протоколен тест](panel/tb_panel.v), [непрекъснато сканиране](panel/tb_static_hold.v).
- [Olimex GPIO1/VQ100](https://github.com/OLIMEX/iCE40HX1K-EVB/blob/master/gpio1-pcf/GPIO1-VQ100.txt):
  съответствие на изводите, проверено и в локалното копие.
- [SPWM референтна реализация](https://github.com/kingdo9/rpi-rgb-led-matrix_pwm_experiment/tree/5da13cb3b0d38d66bb5201f03704b5bef9e4446b/lib/spwm):
  източник на началните последователности и broadcast структурата.
- [DMD ICN1065 реализация](https://github.com/board707/DMD_STM32/blob/398ec1d8636bce866709fbe9c3f0035c90645e7a/DMD_SPWM_Driver_RP.h):
  основа за конфигурационните стойности, scan полето и 12-битовия grayscale.

Тези публични реализации не са заводска гаранция за всички ICND1065L панели.
При противоречие с историческия `HARDWARE.md` използвайте настоящия документ
и потвърдения непрекъснат режим. [panel/NOTES.md](panel/NOTES.md) пази историята.

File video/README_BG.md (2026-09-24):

# SRAM видео памет за панела 64 x 32

## Предназначение

FPGA приема една RGB картинка по UART, записва я във външния SRAM и я
предава на ICND1065L драйверите. След това панелът се сканира непрекъснато,
без периодично преинициализиране. Не е необходимо компютърът да продължава
да изпраща данни. При следваща картинка се използва друг SRAM буфер.

Това е приемник за статични изображения с обновяване по заявка, а не
обещание за видео с 30/60 кадъра в секунда. Старото изображение остава
активно по време на приемането. При валиден завършен кадър се изпълняват
две предавания към панела. Първият изпратен кадър е потвърден от потребителя
като правилен и стабилен. Повтаряща се анимация и преходите между много
кадри не са оценени визуално; двойният SRAM буфер сам по себе си не доказва,
че вътрешното превключване на LED драйверите е без видимо разкъсване.

SRAM е енергозависима памет. След изключване или FPGA reset изображението
не се запазва. При стартиране се зарежда познатата геометрична фигура от
`pattern.hex`. Самата FPGA програма се пази в SPI flash.

## Свързване и стартиране

Платката е Olimex iCE40HX1K-EVB, SRAM K6R4016V1D-TC10. Няма нови външни
връзки към SRAM: използват се пистите на платката, проверени по
`reference/olimex/iCE40HX1K-EVB_Rev_B.net`. Всички package пинове са в
`video.pcf`. За данни се използват SD0..SD7; горният байт на 16-битовия SRAM
не участва и съдържанието му е неопределено.

- OLIMEXINO D0/RX към GPIO1 пин 13, FPGA package пин 7/TX.
- OLIMEXINO D1/TX към GPIO1 пин 14, FPGA package пин 37/RX.
- OLIMEXINO е в режим 3.3 V; обща земя; отделното 5 V захранване на панела остава.
- **GPIO1 пин 34 не е GND.** Земя има на GPIO1 пинове 2, 4 и 8.
- UART: **2 000 000 baud, 8N1, без hardware flow control**, idle high.
- Текущият USB мост е `programmer-fw/iceprog_link`, COM18, USB протокол 230400.
- LED1 означава завършено зареждане/стабилно сканиране; LED2 е heartbeat,
  а при грешка в началния SRAM тест свети постоянно.

От корена на проекта:

```powershell
.\video\test.ps1
.\video\build.ps1
python program_panel.py video/video.bin
python video/send_image.py --status
python video/send_image.py --image C:\images\picture.png
python video/animate.py --cycles 3
```

Картинката трябва да е 64 x 32. За изрично преоразмеряване добавете
`--resize`; за завъртян на масата панел може да добавите `--rotate 180`.
Без тази опция координатите са същите като потвърдената геометрична фигура.
`--port COM18` избира порт; `--test-pattern` изпраща надпис SRAM и цветни
правоъгълници; `--preview-only` подготвя визуализация без достъп до платката.
Файловете `last-sent.png` и `last-sent-preview.png` показват подготвения кадър;
успешното му изпращане се доказва от ACK, не от наличието на тези файлове.

`animate.py` изпраща шест различни кадъра с номера 1..6 и движещо се цветно
блокче. `--cycles 3` повтаря поредицата три пъти и спира на кадър 6.
`--hold 0.5` добавя половин секунда престой след всеки приет кадър; без
опцията няма умишлено забавяне. Тестът не презаписва FPGA flash.
За непрекъснато повторение във фонов режим: `.\video\start_animation.ps1`.
Спиране: `.\video\stop_animation.ps1`. Последният кадър остава на панела.
Докато анимацията върви, COM18 е зает от нея; спрете я преди изпращане на
друга картинка или програмиране. Жив статус: `video/animation-live.json`.
Измерено с текущия 48-байтов USB мост: **3.16 кадъра/s**, 18 успешни кадъра
за 5.694 s. Средно изпращане 257.7 ms, изчакване на ACK след него 58.6 ms.
Това е скоростта на текущата реализация, не физическият максимум на SRAM.
Самият UART при непрекъснат поток би пренесъл 32.52 пакета/s, но този
теоретичен таван не включва USB паузите и обновяването на LED драйверите.

Изисквания за Python: `pyserial`, `Pillow`. Използва се съществуващият
`iceprog.py`; програмата за изпращане не пише SPI flash и не рестартира FPGA.

## UART Протокол, Версия 1

Директният UART протокол към FPGA е отделен от SLIP протокола по USB към
OLIMEXINO. Кадрите към FPGA не използват escaping: дължината е фиксирана.
Числата по-долу са шестнадесетични, освен изрично посочените дължини.

| Поле | Байтове | Съдържание |
|---|---:|---|
| Magic | 2 | `56 52`, ASCII `VR` |
| Command | 1 | `01` = нов кадър, `02` = статус |
| Sequence | 1 | Номер 0..255, повторен в отговора |
| Payload | 6144 или 0 | За `01`: шест цветни плоскости; за `02`: няма |
| CRC16 | 2 | Първо старшият байт |

CRC: **CRC-16/CCITT-FALSE**, polynomial `1021`, initial `FFFF`, refin=false,
refout=false, xorout=`0000`. Обхват: command + sequence + payload. Magic не
участва. Примерен стандартен вектор: ASCII `123456789` -> `29B1`.
Python: `binascii.crc_hqx(body, 0xffff)`.

Един кадър е 6150 байта, само UART преносът му без паузи е 30.75 ms.
Изчаква се ACK преди следващата команда. FPGA не приема нова команда,
докато изпълнява обновяване или изпраща ACK. След повече от 1 s между
байтовете незавършеният пакет се изоставя без ACK. Невалиден stop bit
също прекъсва текущия пакет. След timeout/BREAK се започва от ново `VR`.

При отказ от пакет не се променя активната SRAM банка. Повторен напълно
валиден пакет със същите последни sequence и CRC получава ACK без ново
обновяване. За нов кадър използвайте `(last_sequence + 1) & 255`.
При изгубен ACK първо прочетете статус и сравнете last_sequence/last_crc;
може да изпратите повторно същия пакет. CRC16 е проверка за случайни
грешки, не криптографска идентификация.

### Подредба на Payload

Шест плоскости по 1024 байта: **R1, G1, B1, R2, G2, B2**. Всяка стойност е
8-битова интензивност 0..255. Цветовете не са последователни RGB тройки.
Редът е оптимизиран за проверения панелен протокол; `pack_image()` извършва
преобразуването от нормално изображение с координати x=0..63, y=0..31.

За координата `(x,y)` и цветен канал `c` (R=0, G=1, B=2):

```text
s = 64*(x//32) + 32*(1-((y%16)//8)) + x%32
word = ((y%8)*16 + s%16)*8 + s//16
plane = 3*(y//16) + c
payload_offset = plane*1024 + word
```

За панела се изпращат 16-битови grayscale думи MSB first. За вход 0..254
думата е същото число; 255 се преобразува в `0100`, за да се запази
потвърденото максимално ниво на статичния тест. Това не използва целия
16-битов диапазон и няма gamma correction. Физическата градация на междинни
яркости трябва да се оцени на панела; логическото сериализиране се тества
за всички 256 входни стойности.

### ACK / Статус

Отговорът винаги е 9 байта:

```text
A5 5A sequence status flags last_sequence crc_hi crc_lo xor
```

Последният байт е XOR на първите осем. `crc_hi/lo` са CRC на последния
приет кадър, не CRC на заявката за статус; преди първия кадър са нула.

| status | Значение |
|---:|---|
| 0 | Успех |
| 1 | Кадърът е започнал преди готовност на дисплея/SRAM |
| 2 | Грешна CRC, кадърът не е приложен |
| 3 | Грешка в SRAM при запис/прочит или начален SRAM тест |

`flags`: bit0=стабилно сканиране, bit1=SRAM инициализирана, bit2=активна
банка, bit3=грешка в началния SRAM тест; bit4..7=0. За нов кадър ACK се
изпраща след двете панелни предавания и връщането към непрекъснато сканиране.
ACK доказва изпълнението на FPGA, не оптичната работа на всеки светодиод.

## SRAM И Сканиране

- Банка 0: word адреси `0000..17FF`; банка 1: `2000..37FF`.
- Един адрес съдържа един използван байт, в младшата половина на 16-битовата дума.
- За двете банки се използват 12288 SRAM думи от общо 262144.
- При boot всички 6144 байта на банка 0 се записват от ROM и се прочитат обратно.
- При приемане всеки байт на неактивната банка се записва и проверява чрез прочит.
- /WE е ниско за 80 ns; адресът и данните са установени предварително;
  данните се задържат 40 ns след /WE; прочитът се пробва 80 ns след /OE.
- При сканиране шестте цветни байта за следващата дума се кешират преди
  значимите grayscale битове. По време на постоянния hold няма SRAM четене.
- 100 MHz входен такт -> 25 MHz логика -> SCLK 1.5625 MHz.
- Scan 1/8, 8 чип-позиции на цветова линия, 128 такта на scan период.
- OE: фази 100..103; ABC се сменя на фаза 112.
- Регистровата инициализация и геометрията идват от потвърдения драйвер:
  виж `../PANEL_PROTOCOL_BG.md`. `panel/panel.v` не е променен.

## Тестове И Възстановяване

`test.ps1` проверява независимо координатите, CRC и ACK на компютъра.
`tb_video.v` моделира асинхронен SRAM и реални 500 ns UART битове. Проверява
началната картина, целите буфери, изходните RGB grayscale битове, две смени
на банка, повторен пакет, грешна CRC, timeout, BREAK и инжектирана SRAM грешка.
Симулацията съкращава hold и панелния делител, но не UART скоростта или
броя на панелните битове.

Синтезът използва класическия ABC (`abc -lut 4`), защото ABC9 в текущия
Windows Yosys прекъсва с assert в XAIGER2 backend. Не се премахват проверки
за време: `clocks.py` задава реалните 100/25 MHz часовници.

Възстановяване на потвърдената статична програма:

```powershell
python program_panel.py backups/stable-panel-20260924/panel/panel.bin
```

Преди всеки запис `program_panel.py` прочита старото съдържание два пъти,
създава нов backup, проверява записаните сектори и целия засегнат диапазон,
след което проверява CDONE. Старият архив не се променя.

## Състояние На Проверка

Резултатите от конкретното зареждане и визуалната проверка се записват
отделно в `VERIFICATION.md`. Този файл описва протокола и реализацията,
а не замества потвърждение от физическия панел.

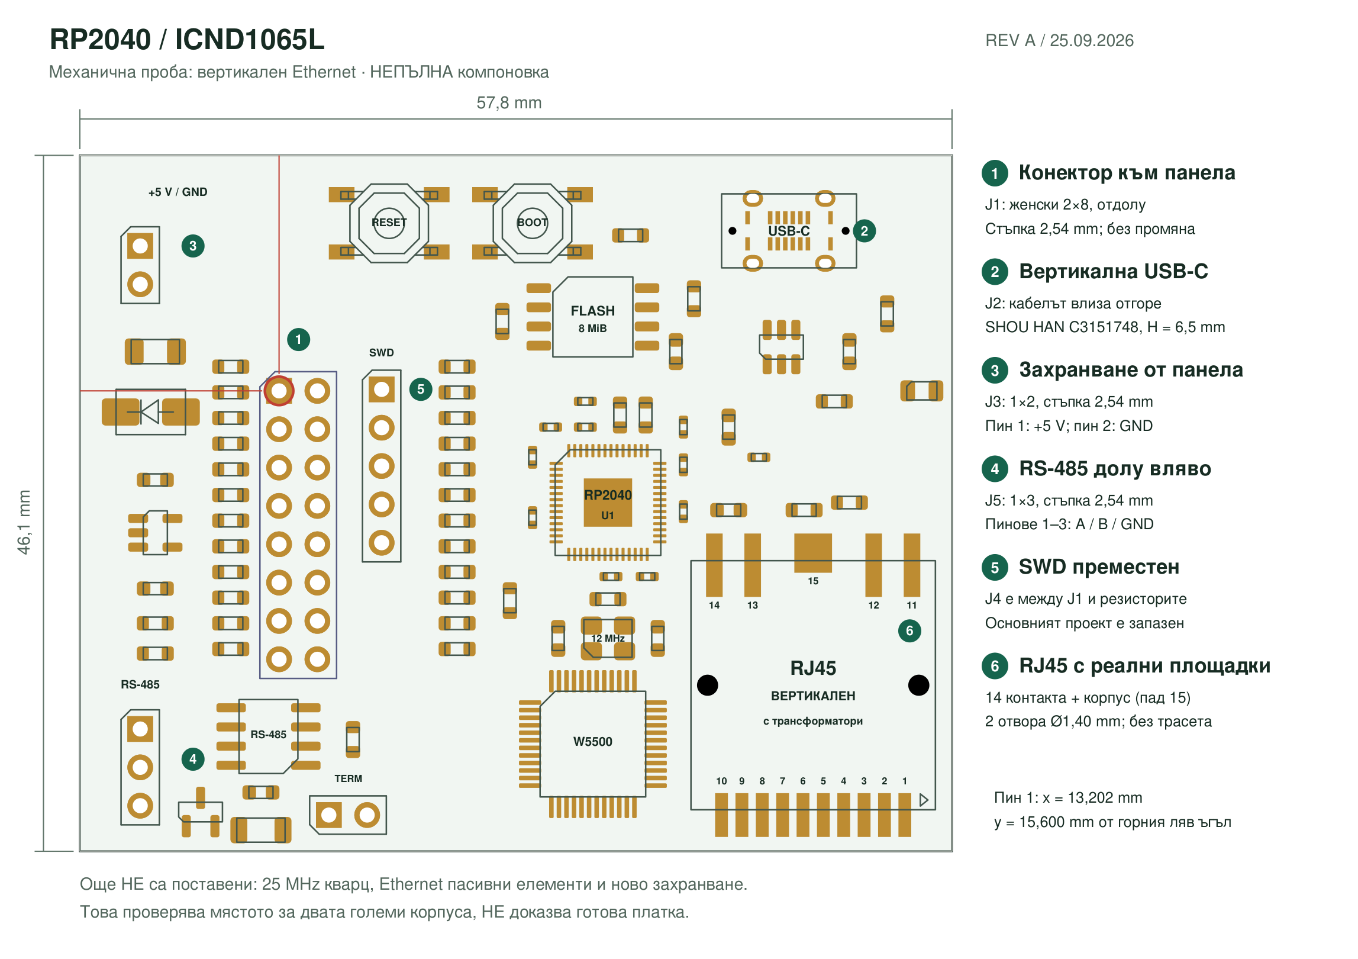
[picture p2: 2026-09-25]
hardware/pico-panel/preview/ethernet-fit.png

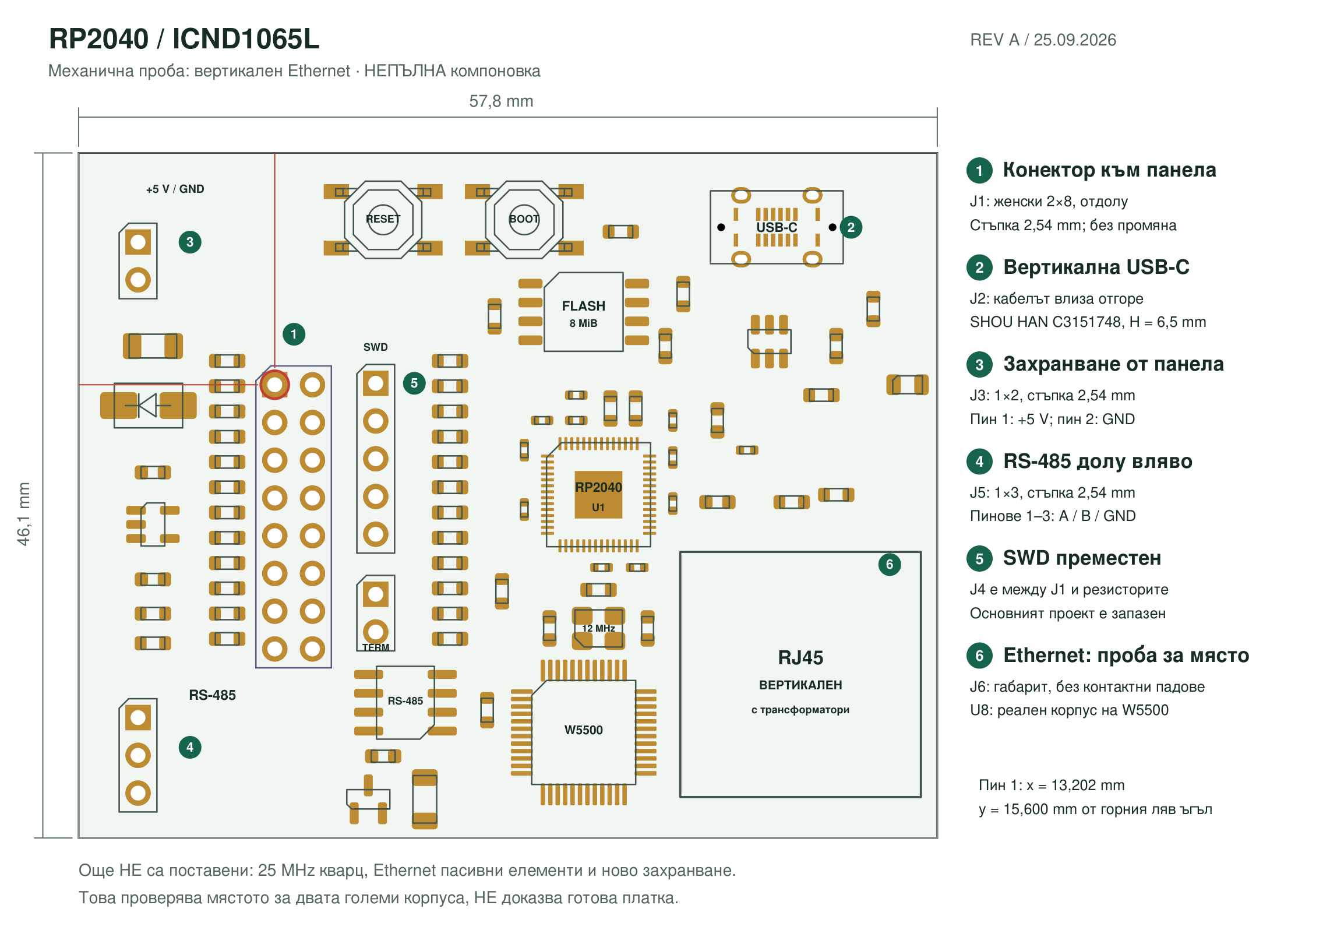
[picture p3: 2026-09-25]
hardware/pico-panel/preview/before-rs485-tight-group/ethernet-fit.png

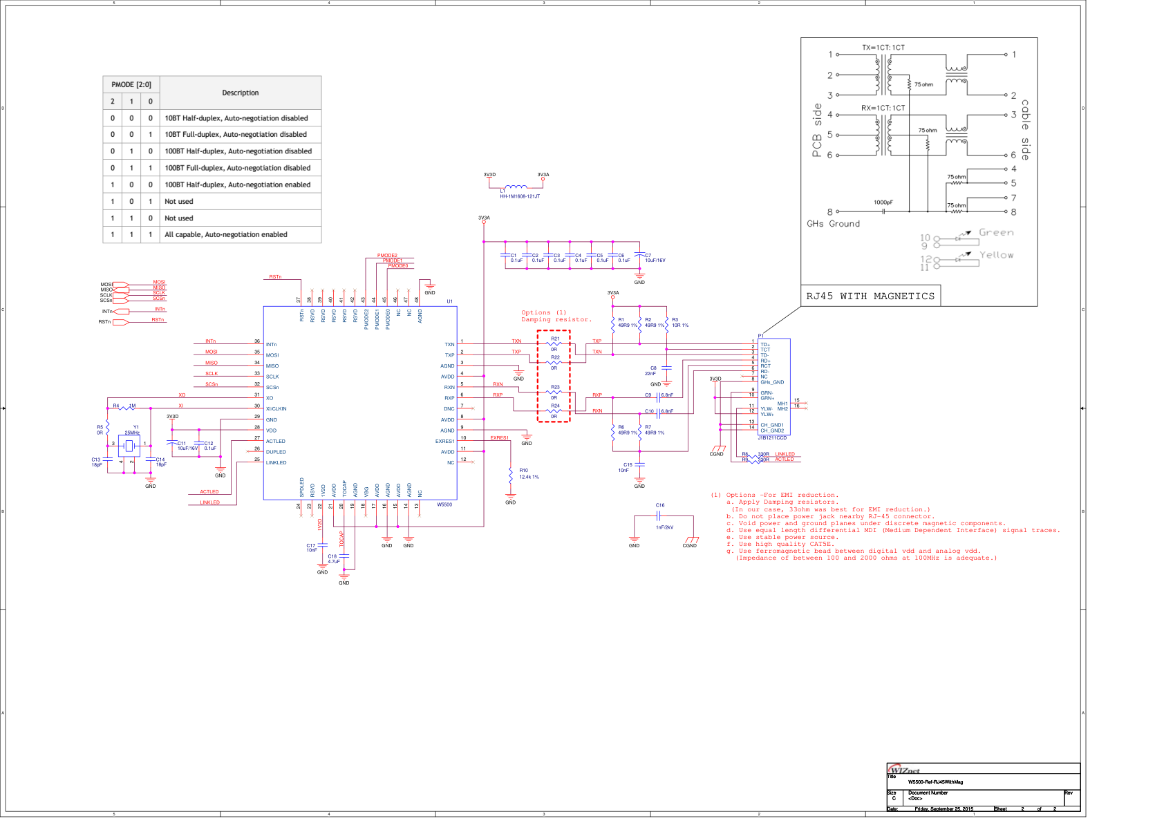
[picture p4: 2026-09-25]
hardware/pico-panel/reference/W5500-reference.png

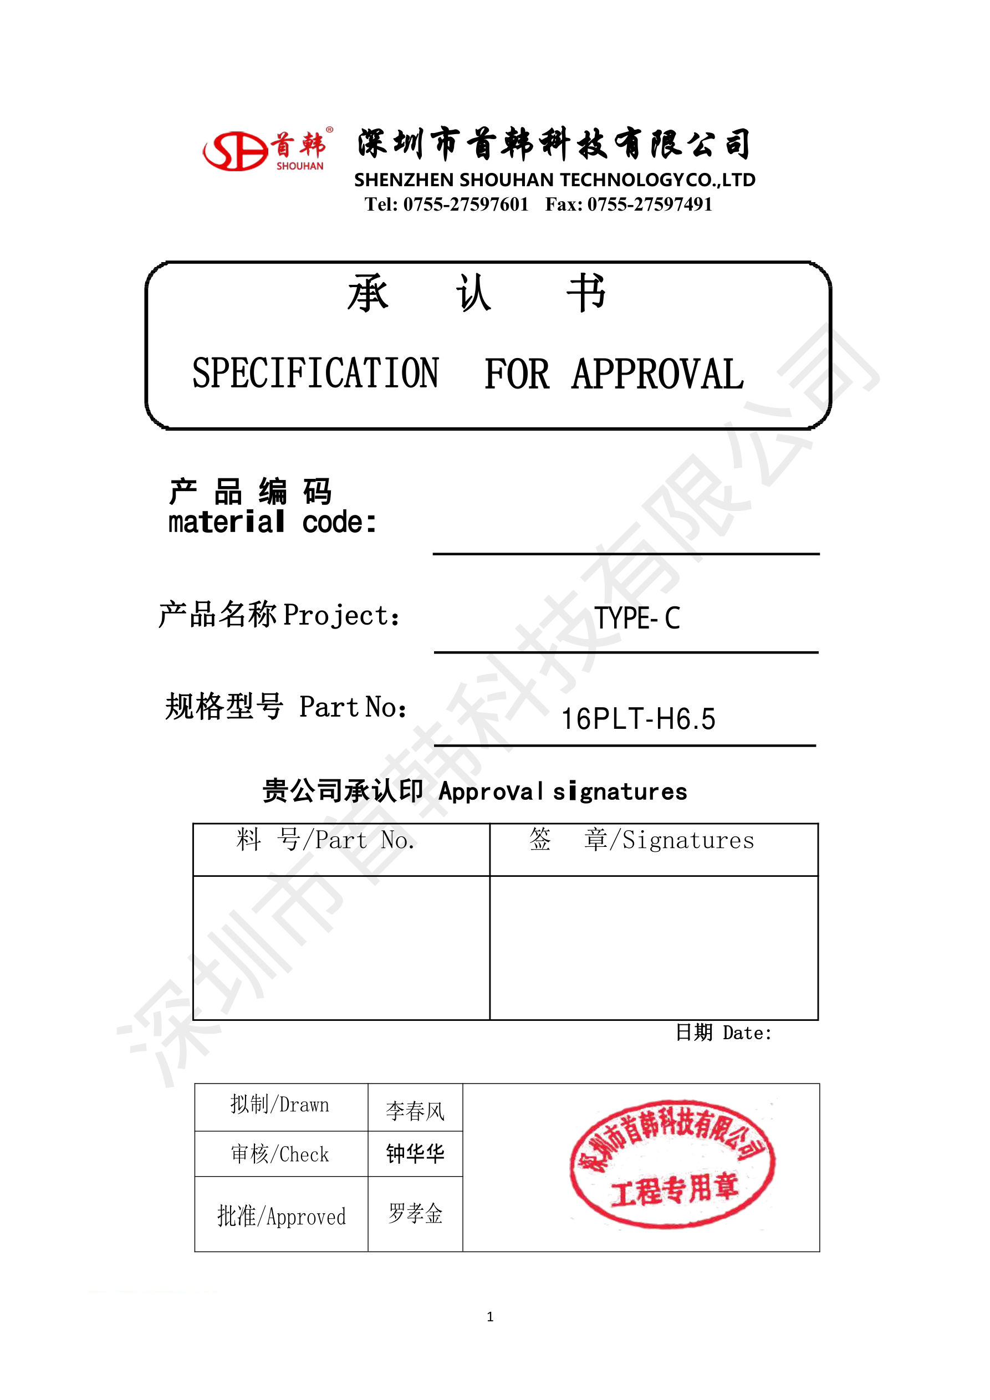
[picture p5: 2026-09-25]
hardware/pico-panel/reference/C3151748-pcb.png

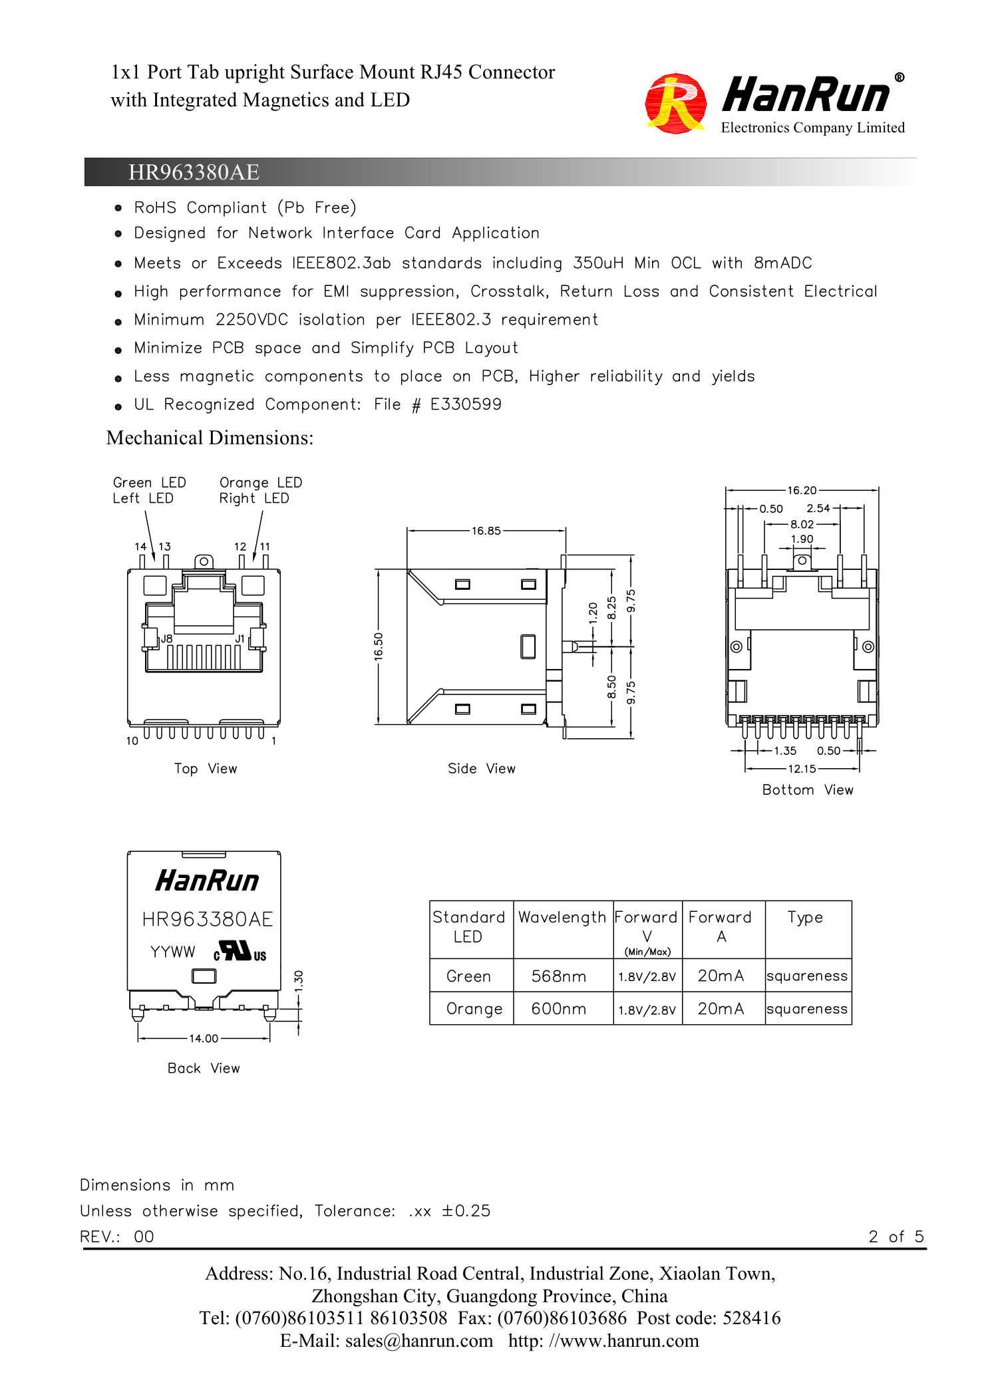
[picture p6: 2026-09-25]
hardware/pico-panel/reference/HR963380AE-dimensions.png

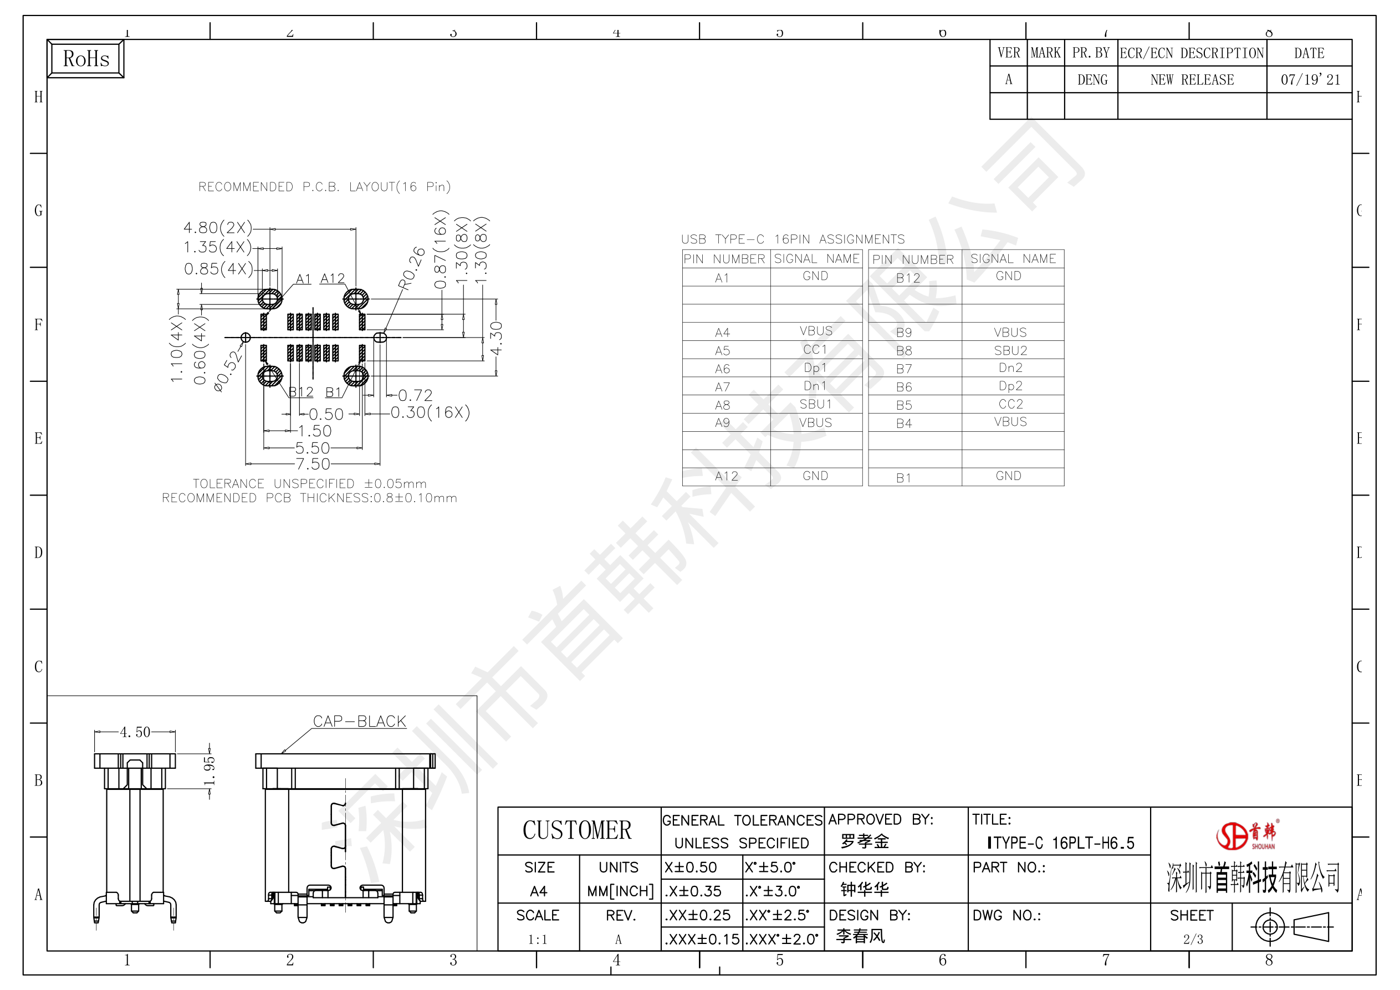
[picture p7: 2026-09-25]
hardware/pico-panel/reference/C3151748-landpattern.png

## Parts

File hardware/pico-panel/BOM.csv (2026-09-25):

Reference | Value | Footprint | LCSC | Assembly | Side | X_mm | Y_mm | Rotation_deg
U1 | RP2040 | Package_DFN_QFN:QFN-56-1EP_7x7mm_P0.4mm_EP3.2x3.2mm | C2040 | SMT | F | 29.4375 | 27.3 | 0.0
U2 | W25Q64JVSSIQ | Package_SO:SOIC-8_5.3x5.3mm_P1.27mm | C179171 | SMT | F | 27.5875 | 14.595 | 0.0
R1 | 10k | Resistor_SMD:R_0603_1608Metric | C25804 | SMT | F | 21.4375 | 21.8 | 90.0
R2 | 1k | Resistor_SMD:R_0603_1608Metric | C21190 | SMT | F | 39.0 | 38.5 | 0.0
SW1 | BOOTSEL | Button_Switch_SMD:SW_SPST_TL3342 |  | HAND | F | 49.4 | 40.15 | 90.0
SW2 | RESET | Button_Switch_SMD:SW_SPST_TL3342 |  | HAND | F | 57.4 | 40.35 | 90.0
R3 | 10k | Resistor_SMD:R_0603_1608Metric | C25804 | SMT | F | 34.0 | 37.5 | 0.0
Y1 | ABM8-272-T3 12MHz | Crystal:Crystal_SMD_3225-4Pin_3.2x2.5mm | C20625731 | SMT | F | 27.6375 | 37.3 | 0.0
R4 | 1k | Resistor_SMD:R_0603_1608Metric | C21190 | SMT | F | 26.0 | 33.325 | -90.0
C1 | 15p | Capacitor_SMD:C_0603_1608Metric | C1644 | SMT | F | 24.1375 | 36.8 | 90.0
C2 | 15p | Capacitor_SMD:C_0603_1608Metric | C1644 | SMT | F | 31.1375 | 37.3 | 90.0
C3 | 100n | Capacitor_SMD:C_0603_1608Metric | C14663 | SMT | F | 33.0 | 9.5 | 90.0
C4 | 100n | Capacitor_SMD:C_0402_1005Metric | C1525 | SMT | F | 23.02 | 25.4 | 0.0
C5 | 100n | Capacitor_SMD:C_0402_1005Metric | C1525 | SMT | F | 23.02 | 29.0 | 0.0
C6 | 100n | Capacitor_SMD:C_0402_1005Metric | C1525 | SMT | F | 29.5 | 34.02 | 90.0
C7 | 100n | Capacitor_SMD:C_0402_1005Metric | C1525 | SMT | F | 35.9375 | 29.025 | 0.0
C8 | 100n | Capacitor_SMD:C_0402_1005Metric | C1525 | SMT | F | 35.9375 | 25.425 | 0.0
C9 | 100n | Capacitor_SMD:C_0402_1005Metric | C1525 | SMT | F | 35.9375 | 23.425 | 0.0
C10 | 100n | Capacitor_SMD:C_0402_1005Metric | C1525 | SMT | F | 32.98 | 21.5 | 0.0
C11 | 100n | Capacitor_SMD:C_0402_1005Metric | C1525 | SMT | F | 29.1375 | 22.3 | 0.0
C12 | 100n | Capacitor_SMD:C_0402_1005Metric | C1525 | SMT | F | 26.9375 | 22.3 | 0.0
C13 | 100n | Capacitor_SMD:C_0402_1005Metric | C1525 | SMT | F | 31.5 | 34.02 | 90.0
C14 | 100n | Capacitor_SMD:C_0402_1005Metric | C1525 | SMT | F | 27.7375 | 20.8 | 0.0
C15 | 1u | Capacitor_SMD:C_0603_1608Metric | C15849 | SMT | F | 34.4375 | 33.3 | 90.0
C16 | 1u | Capacitor_SMD:C_0603_1608Metric | C15849 | SMT | F | 38.0 | 24.725 | 90.0
J4 | SWD 3V3 GND CLK IO RUN | Connector_PinHeader_2.54mm:PinHeader_1x05_P2.54mm_Vertical |  | HAND | F | 30.92 | 43.0 | 90.0
R5 | 1k | Resistor_SMD:R_0603_1608Metric | C21190 | SMT | F | 52.4375 | 8.5 | 0.0
D1 | STATUS green | LED_SMD:LED_0805_2012Metric | C2297 | SMT | F | 56.4375 | 8.5 | 180.0
J2 | USB-C VERTICAL H6.5 | Panel:USB_C_SHOUHAN_TYPE-C_16PLT-H6.5_Vertical | C3151748 | SMT | F | 43.4 | 5.0 | 0.0
R6 | 5.1k | Resistor_SMD:R_0603_1608Metric | C23186 | SMT | F | 42.175 | 13.5 | 180.0
R7 | 5.1k | Resistor_SMD:R_0603_1608Metric | C23186 | SMT | F | 36.5 | 5.0 | 90.0
U3 | USBLC6-2SC6 | Package_TO_SOT_SMD:SOT-23-6 | C7519 | SMT | F | 37.95 | 12.3625 | 90.0
R8 | 27 | Resistor_SMD:R_0603_1608Metric | C25190 | SMT | F | 35.5 | 17.0 | -90.0
R9 | 27 | Resistor_SMD:R_0603_1608Metric | C25190 | SMT | F | 38.3 | 17.0 | -90.0
C17 | 1u | Capacitor_SMD:C_0603_1608Metric | C15849 | SMT | F | 44.275 | 11.0 | 0.0
R10 | 100k | Resistor_SMD:R_0603_1608Metric | C25803 | SMT | F | 41.325 | 19.5 | 0.0
R11 | 100k | Resistor_SMD:R_0603_1608Metric | C25803 | SMT | F | 46.0 | 19.5 | 0.0
J3 | PANEL POWER +5V GND | Connector_PinHeader_2.54mm:PinHeader_1x02_P2.54mm_Vertical |  | HAND | F | 4.0 | 5.0 | 0.0
F1 | PTC 0.5A | Fuse:Fuse_1206_3216Metric | C70076 | SMT | F | 8.0 | 5.0 | 90.0
D2 | SS14 | Diode_SMD:D_SMA | C2480 | SMT | F | 14.0 | 4.5 | 0.0
U4 | AP63203WU-7 | Package_TO_SOT_SMD:TSOT-23-6 | C780769 | SMT | F | 20.1375 | 5.45 | 0.0
C18 | 10u 16V | Capacitor_SMD:C_0805_2012Metric | C1713 | SMT | F | 15.95 | 8.5 | 180.0
C19 | 22u 10V | Capacitor_SMD:C_0805_2012Metric | C29277 | SMT | F | 30.0 | 5.0 | 90.0
L1 | 3.9u SWPA4030S3R9MT | Inductor_SMD:L_Sunlord_SWPA4030S | C96899 | SMT | F | 26.0 | 6.5 | 0.0
C23 | 100n | Capacitor_SMD:C_0603_1608Metric | C14663 | SMT | F | 25.725 | 2.5 | 0.0
C24 | 22u 10V | Capacitor_SMD:C_0805_2012Metric | C29277 | SMT | F | 33.0 | 5.0 | 90.0
C25 | 100n | Capacitor_SMD:C_0603_1608Metric | C14663 | SMT | F | 11.775 | 8.5 | 0.0
R12 | 100k | Resistor_SMD:R_0603_1608Metric | C25803 | SMT | F | 36.9375 | 32.8 | 90.0
R13 | 100k | Resistor_SMD:R_0603_1608Metric | C25803 | SMT | F | 47.0 | 32.2 | 0.0
J1 | PANEL BOTTOM 2x8 | Connector_PinSocket_2.54mm:PinSocket_2x08_P2.54mm_Vertical |  | HAND | B | 13.202 | 15.6 | 180.0
R40 | 47k | Resistor_SMD:R_0603_1608Metric | C25819 | SMT | F | 8.5 | 11.5 | 0.0
R41 | 47k | Resistor_SMD:R_0603_1608Metric | C25819 | SMT | F | 8.5 | 13.5 | 0.0
R42 | 47k | Resistor_SMD:R_0603_1608Metric | C25819 | SMT | F | 8.5 | 15.5 | 0.0
R43 | 47k | Resistor_SMD:R_0603_1608Metric | C25819 | SMT | F | 8.5 | 17.5 | 0.0
R44 | 47k | Resistor_SMD:R_0603_1608Metric | C25819 | SMT | F | 8.5 | 19.5 | 0.0
R45 | 47k | Resistor_SMD:R_0603_1608Metric | C25819 | SMT | F | 8.5 | 21.5 | 0.0
R46 | 47k | Resistor_SMD:R_0603_1608Metric | C25819 | SMT | F | 8.5 | 23.5 | 0.0
R47 | 47k | Resistor_SMD:R_0603_1608Metric | C25819 | SMT | F | 8.5 | 25.5 | 0.0
R48 | 47k | Resistor_SMD:R_0603_1608Metric | C25819 | SMT | F | 8.5 | 27.6 | 0.0
R49 | 47k | Resistor_SMD:R_0603_1608Metric | C25819 | SMT | F | 8.5 | 29.5 | 0.0
R50 | 47k | Resistor_SMD:R_0603_1608Metric | C25819 | SMT | F | 8.5 | 31.5 | 0.0
R51 | 47k | Resistor_SMD:R_0603_1608Metric | C25819 | SMT | F | 8.5 | 33.5 | 0.0
U7 | SN65HVD75DR | Package_SO:SOIC-8_3.9x4.9mm_P1.27mm | C57928 | SMT | F | 15.025 | 39.0 | 180.0
C22 | 100n | Capacitor_SMD:C_0603_1608Metric | C14663 | SMT | F | 14.225 | 44.0 | 0.0
R18 | 10k | Resistor_SMD:R_0603_1608Metric | C25804 | SMT | F | 20.5 | 39.0 | 90.0
D4 | SM712 | Package_TO_SOT_SMD:SOT-23 | C32677 | SMT | F | 8.55 | 38.5 | 90.0
J5 | RS485 A B GND | Connector_PinHeader_2.54mm:PinHeader_1x03_P2.54mm_Vertical |  | HAND | F | 4.0 | 36.0 | 0.0
R19 | 120 0.25W | Resistor_SMD:R_1206_3216Metric | C17909 | SMT | F | 19.8 | 43.5 | 0.0
JP1 | TERM 120R | Connector_PinHeader_2.54mm:PinHeader_1x02_P2.54mm_Vertical |  | HAND | F | 8.0 | 43.5 | 90.0
U8 | W5500 | Package_QFP:LQFP-48_7x7mm_P0.5mm | C32843 | SMT | F | 56.0 | 26.0 | 180.0
J6 | HR963380AE MAGJACK | Panel:RJ45_HanRun_HR963380AE_Vertical | C19724763 | SMT | F | 77.0 | 26.0 | -90.0
FB1 | 120R@100MHz 2A | Inductor_SMD:L_0603_1608Metric | C14709 | SMT | F | 54.0 | 14.0 | 0.0
C30 | 100n | Capacitor_SMD:C_0402_1005Metric | C1525 | SMT | F | 62.0 | 27.25 | 90.0
C31 | 100n | Capacitor_SMD:C_0402_1005Metric | C1525 | SMT | F | 62.0 | 24.5 | 90.0
C32 | 100n | Capacitor_SMD:C_0402_1005Metric | C1525 | SMT | F | 62.0 | 21.48 | 90.0
C33 | 100n | Capacitor_SMD:C_0402_1005Metric | C1525 | SMT | F | 58.5 | 19.5 | 90.0
C34 | 100n | Capacitor_SMD:C_0402_1005Metric | C1525 | SMT | F | 55.9 | 19.5 | 90.0
C35 | 100n | Capacitor_SMD:C_0402_1005Metric | C1525 | SMT | F | 53.5 | 19.52 | 90.0
C36 | 10u 16V | Capacitor_SMD:C_0805_2012Metric | C1713 | SMT | F | 58.0 | 14.5 | 0.0
C37 | 100n | Capacitor_SMD:C_0402_1005Metric | C1525 | SMT | F | 49.0 | 20.98 | 90.0
C38 | 4.7u | Capacitor_SMD:C_0603_1608Metric | C19666 | SMT | F | 50.0 | 14.5 | 0.0
C39 | 4.7u | Capacitor_SMD:C_0603_1608Metric | C19666 | SMT | F | 54.2 | 17.0 | 0.0
C40 | 10n | Capacitor_SMD:C_0603_1608Metric | C57112 | SMT | F | 51.0 | 19.0 | 90.0
R60 | 12.4k 1% | Resistor_SMD:R_0402_1005Metric | C11692 | SMT | F | 64.0 | 20.51 | 90.0
Y2 | ABM8-25.000MHZ-D2Y-T | Crystal:Crystal_SMD_3225-4Pin_3.2x2.5mm | C179643 | SMT | F | 48.0 | 25.0 | 90.0
C41 | 27p C0G | Capacitor_SMD:C_0603_1608Metric | C1656 | SMT | F | 44.0 | 23.4 | 90.0
C42 | 27p C0G | Capacitor_SMD:C_0603_1608Metric | C1656 | SMT | F | 44.0 | 26.7 | 90.0
R61 | 1M | Resistor_SMD:R_0603_1608Metric | C22935 | SMT | F | 41.5 | 25.325 | -90.0
R62 | 10k | Resistor_SMD:R_0603_1608Metric | C25804 | SMT | F | 50.0 | 32.825 | -90.0
C43 | 100n | Capacitor_SMD:C_0603_1608Metric | C14663 | SMT | F | 54.0 | 33.5 | 0.0
R63 | 10k | Resistor_SMD:R_0603_1608Metric | C25804 | SMT | F | 49.0 | 29.0 | 90.0
R64 | 49.9 1% | Resistor_SMD:R_0603_1608Metric | C23185 | SMT | F | 62.2 | 32.0 | 0.0
R65 | 49.9 1% | Resistor_SMD:R_0603_1608Metric | C23185 | SMT | F | 62.2 | 34.0 | 0.0
R66 | 49.9 1% | Resistor_SMD:R_0603_1608Metric | C23185 | SMT | F | 64.0 | 18.0 | 0.0
R67 | 49.9 1% | Resistor_SMD:R_0603_1608Metric | C23185 | SMT | F | 64.0 | 14.5 | 0.0
C44 | 10n | Capacitor_SMD:C_0603_1608Metric | C57112 | SMT | F | 61.0 | 18.5 | 90.0
C45 | 6.8n | Capacitor_SMD:C_0603_1608Metric | C84723 | SMT | F | 64.599999 | 27.0 | 0.0
C46 | 6.8n | Capacitor_SMD:C_0603_1608Metric | C84723 | SMT | F | 64.5 | 24.0 | 0.0
R68 | 10 | Resistor_SMD:R_0603_1608Metric | C22859 | SMT | F | 65.0 | 30.2 | 90.0
C47 | 100n | Capacitor_SMD:C_0603_1608Metric | C14663 | SMT | F | 64.8 | 35.8 | 0.0
R69 | 470 | Resistor_SMD:R_0603_1608Metric | C23179 | SMT | F | 70.325 | 36.5 | 0.0
R70 | 470 | Resistor_SMD:R_0603_1608Metric | C23179 | SMT | F | 70.325 | 42.0 | 0.0
C48 | 1n 1kV | Capacitor_SMD:C_1206_3216Metric | C1941 | SMT | F | 70.5 | 39.0 | 180.0

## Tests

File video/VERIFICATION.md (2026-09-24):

# Verification, 2026-09-24

## Confirmed Physical Result

FPGA was programmed once with this new image; the first serially loaded
frame contains the text SRAM, a cyan border and red/green/blue/yellow blocks.
The user answered yes when asked whether this exact picture is visible,
stable, and free of white dots/flicker. The panel is physically upside down.
The picture was initially left running. The user subsequently requested
a six-frame animation test; that separate test is recorded below.

Active bitstream: `video/video.bin`, 32220 bytes.
SHA256: `2c926b003a3d54a3c8ab7683ae0de9ba5894b31ca99ca25665a45670b34f23f1`.
Pre-program double-read backup: `backups/20260924-170608-flash-prefix.bin`.
Backup SHA256: `2036624bbd79b4127b4dc96e252a7b8ae74836d2639e874c99fbbe31fea5fcb9`.
Programming checked all 32768 affected bytes and CDONE/reset release.
See `logs/program-video.log`.

## Hardware Protocol Results

- Boot reported SRAM initialized, no SRAM error, bank 0, stable scanning.
- Frame 1: sequence 1, CRC 44409 (`AD79`), bank 1, status 0, ready true.
- Transfer plus display acknowledgement: 0.323 seconds for this one frame.
  This is a measured single transaction, not a sustained frame-rate benchmark.
- Deliberately inverted image with wrong CRC: rejected with status 2;
  active bank, sequence and CRC unchanged.
- Incomplete 100-byte packet followed by 1.2 seconds silence: abandoned;
  previous frame identity and ready state retained.
- Repeated original valid packet: successful ACK, no extra bank swap.
- Closing/reopening COM18 and retraining the bridge with BREAK did not reset
  the FPGA or lose its active frame.

Evidence: `logs/video-status-boot.json`, `logs/video-first-frame.json`,
`logs/video-hardware-verification.json`. `verify_hardware.py` reproduces the
negative tests, requiring `last-sent.png` to match the active frame CRC first.

The board-level SRAM proof is FPGA write/readback of all bytes, including
6144 initial pattern bytes and every received payload byte. There is no
host command for arbitrary SRAM dump, and no exhaustive whole-chip memory
or address-line diagnostic is claimed.

## Automated Tests

Three Python unit tests passed: all 6144 packed positions independently
checked, CRC standard vector and packet residue, ACK checksum handling.

The HDL integration simulation passed with an asynchronous 10 ns SRAM model
and exact 500 ns UART bits (2 Mbaud). It verifies:

- All 6144 initialized SRAM bytes and no read/write bus contention.
- UART receive and ACK transmit at real baud timing.
- Two distinct complete payloads, both SRAM bank directions.
- 98304 panel SCLK samples, all six RGB bits, including all 256 input levels.
- CRC error, duplicate frame, partial timeout, BREAK recovery.
- Injected SRAM readback failure rejected with status 3.

The simulation accelerates the panel clock divider and hold, and reduces
the packet timeout. It is not an electrical model of the LED driver ICs.
Evidence: `logs/test-video.log`.

## Build And Remaining Limits

1077/1280 logic cells (84%), 2/16 block RAMs, 46/72 IOs.
Post-route timing: 62.86 MHz for the 25 MHz logic clock;
655.31 MHz for the 100 MHz divider clock. Both pass.
Evidence: `video/synthesis.log`, `video/route.log`, `logs/build-video.log`.

The original stable panel and diagnostic bitstreams remain unchanged:

- Panel SHA256: `b78fb7d55cf977bcf4902dc009b04d8d9af7a3111f0af55a4674b78caf37d09f`.
- Link diagnostic SHA256: `e6e675a3e2145f5f83ecc53c2e2f99b437c255de51df6ad6ed5c9d60c57ab34f`.

Not yet verified: long-duration animation endurance, transition tearing under
repeated updates, calibrated grayscale/gamma, behavior across voltage/temperature
extremes. SRAM loses the user frame on power loss or FPGA reset; boot then
loads the original ROM geometry pattern. No flash persistence was added.

## Six-Frame Test Requested Afterwards

`python video/animate.py --cycles 3` sent six unique numbered frames three
times, with no deliberate hold between acknowledgements. All 18 packets
passed ACK status, ready state, sequence, CRC, and expected alternating-bank
checks. No FPGA reprogramming was required. The final frame is number 6.

- 18 frames in 5.6944623 seconds: **3.1609657 frames/second**.
- Mean USB-bridge sending time: 0.2576832 seconds/frame.
- Mean remaining wait for FPGA ACK: 0.0585700 seconds/frame.
- Individual transactions: 0.3088239..0.3302250 seconds.
- Four host-side tests now pass, including six distinct generated frames.
- Evidence: `logs/video-animation.json`, `logs/video-animation-run.log`.

This measures the current stop-and-wait bridge path using 48-byte chunks.
It is not the ultimate achievable speed of this hardware. The 2 Mbaud UART
alone carries 6150-byte 8N1 packets in 30.75 ms (32.52 packets/s), before any
USB overhead or panel refresh time. No claim of visually tear-free animation
is made from the acknowledgements alone. The user confirmed seeing all six
frames and requested continuous repetition. The loop is started separately
with `video/start_animation.ps1`; `video/stop_animation.ps1` requests a clean
stop after the current frame. While running, COM18 belongs to this process.

### Longer Run Observation

During the subsequent GitHub upload task, the first background loop stopped
after 1308 acknowledged frames with a host `TimeoutError` waiting for an ACK.
The error location was `display.receive(sequence)` in `animate.py`.
The cause has not been established; continuous long-duration reliability
must not be inferred from the earlier 18-frame test.

A fresh status request succeeded: ready=true, SRAM initialized=true,
SRAM error=false, bank=0, last_sequence=48, last_crc=54420. The loop was
restarted without FPGA reprogramming and again acknowledged frames at
approximately 3.16 fps. Automatic retry/recovery is not implemented in the
animation runner; it deliberately stops on an unconfirmed frame.

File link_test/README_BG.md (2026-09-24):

# Диагностика на серийната връзка

## Потвърден резултат след поправката на кабелите

Потребителят размени проводниците. Новото пасивно измерване е
D1:D0 `[2,3,2,3,2,3,2,3,2]`: импулсите вече пристигат на D0, както трябва.
OLIMEXINO firmware е обновен с резервно копие и проверен запис; вижте
`../programmer-fw/README_BG.md` за командите, версиите и възстановяването.

Sweep с по 4096 байта мина без грешки при всички 13 зададени скорости
от 4800 до 2000000 baud. Подробни резултати: `../logs/uart-sweep.json`.
При 2000000 baud дългият тест изпрати и получи 1048576 байта, без сгрешени
или липсващи байтове, за 66.752 s: 15708.5 полезни bytes/s през PC/USB моста.
Файл: `../logs/uart-2m-endurance.json`.
Още 10 независими break/обучение цикъла с по 8192 байта всеки също минаха
без сгрешени или липсващи байтове: `../logs/uart-2m-retrain.json`.
В края на проверката мостът остава обучен на 2000000 baud; след захранване
скоростта трябва отново да се избере с E0. USB портът е COM18.

Това е най-високата проверена UART настройка, а и най-бързият baud делител
на 16 MHz ATmega32U4 (U2X=1, UBRR=0). Не е физически максимум на FPGA.
Тестът е на 48-byte пакети с паузи, не на непрекъснат поток без паузи.
FPGA измерва битовия период с резолюция 40 ns; при 2 Mbaud неговият целочислен
делител може да е 12 или 13, а не точно 12.5. Резултатът е емпирично проверен
за тази постановка, не гаранция за други кабели или липса на електрически запас.

## Образ и първоначална диагностика

24.09.2026: зареден е `link_diag.bin`, SHA256
`e6e675a3e2145f5f83ecc53c2e2f99b437c255de51df6ad6ed5c9d60c57ab34f`.
Записът на 32768 засегнати байта е прочетен обратно и проверен, CDONE=1.
Лог: `../logs/program-link-diag.log`.
Старият flash prefix е `../backups/20260924-163232-flash-prefix.bin`.
Стабилният панелен образ остава `../backups/stable-panel-20260924/panel/panel.bin`.

Образът инстанцира непроменения драйвер `../panel/panel.v` и запазва фигурата.
Добавя серийна диагностика: TX е FPGA пин 7 / GPIO1 пин 13;
RX е FPGA пин 37 / GPIO1 пин 14, с включен pull-up.
LED1 показва обучена UART връзка, а не конфигуриран панел.
LED2 е heartbeat на панела или постоянен индикатор при UART/FIFO грешка.

Преди обучение TX сменя ниво през 250 ms. При пасивно слушане са получени
нивата D1:D0 `[3,1,3,1,3,1,3,1,3]`: осем промени по D1, нула по D0.
Следователно изходът на FPGA пристига на D1 вместо на D0. Потребителят е
помолен да изключи захранването и да размени двата серийни проводника.
OLIMEXINO D0 и D1 са оставени като входове. Не ги задвижвайте преди поправката.

Правилно: D0/RX на OLIMEXINO -> GPIO1/13; D1/TX -> GPIO1/14.
Не бъркайте номера на GPIO1 конектора с номера на крачетата на FPGA корпуса.

Тестовият протокол след поправката:

1. RX ниско поне 12 ms (break), после високо.
2. Изпращане на 0x55 на избраната скорост, 8N1.
3. Пауза поне 20 ms. FPGA измерва продължителността на първия нисък бит.
4. Всеки следващ байт се връща XOR 0xA5, през FIFO до 255 чакащи байта.
5. Нов break нулира обучението и FIFO за друга скорост.

Симулацията `tb_uart_probe.v` преминава 32 байта на всеки от делителите
5208, 2604, 217, 50 и 25 при 25 MHz: приблизително 4800, 9600, 115200,
500000 и 1000000 baud. Реалното измерване е описано по-горе.

Предишният firmware `iceprog2` на OLIMEXINO има `Serial1.begin(4800)`.
Промяната на USB CDC baudrate не променя тази скорост. Нужна е отделна
поддръжка за избор на baud и break; тя вече е добавена в `iceprog_link`.

Внимание: диагностичната команда WATCH прави Serial1.end(), но старият
firmware не нулира локалния static флаг `up` в uart1_ensure(). След WATCH
може да е нужен reset на OLIMEXINO преди възстановяване на USART. При
новия firmware това е поправено чрез проверка на RXEN/TXEN.

Изграждане: от корена на проекта `./link_test/build.ps1`.
Симулация от link_test с OSS CAD bin/lib на PATH:

```powershell
iverilog -g2012 -s tb_uart_probe -o tb_uart_probe.vvp link_diag.v tb_uart_probe.v
vvp tb_uart_probe.vvp
```

Контролният автобауд тест не гарантира всеки възможен делител. За избор на
работна скорост трябва да се измерят дълги последователности в двете посоки,
включително пропуснати/излишни/сгрешени байтове, и да се остави запас.

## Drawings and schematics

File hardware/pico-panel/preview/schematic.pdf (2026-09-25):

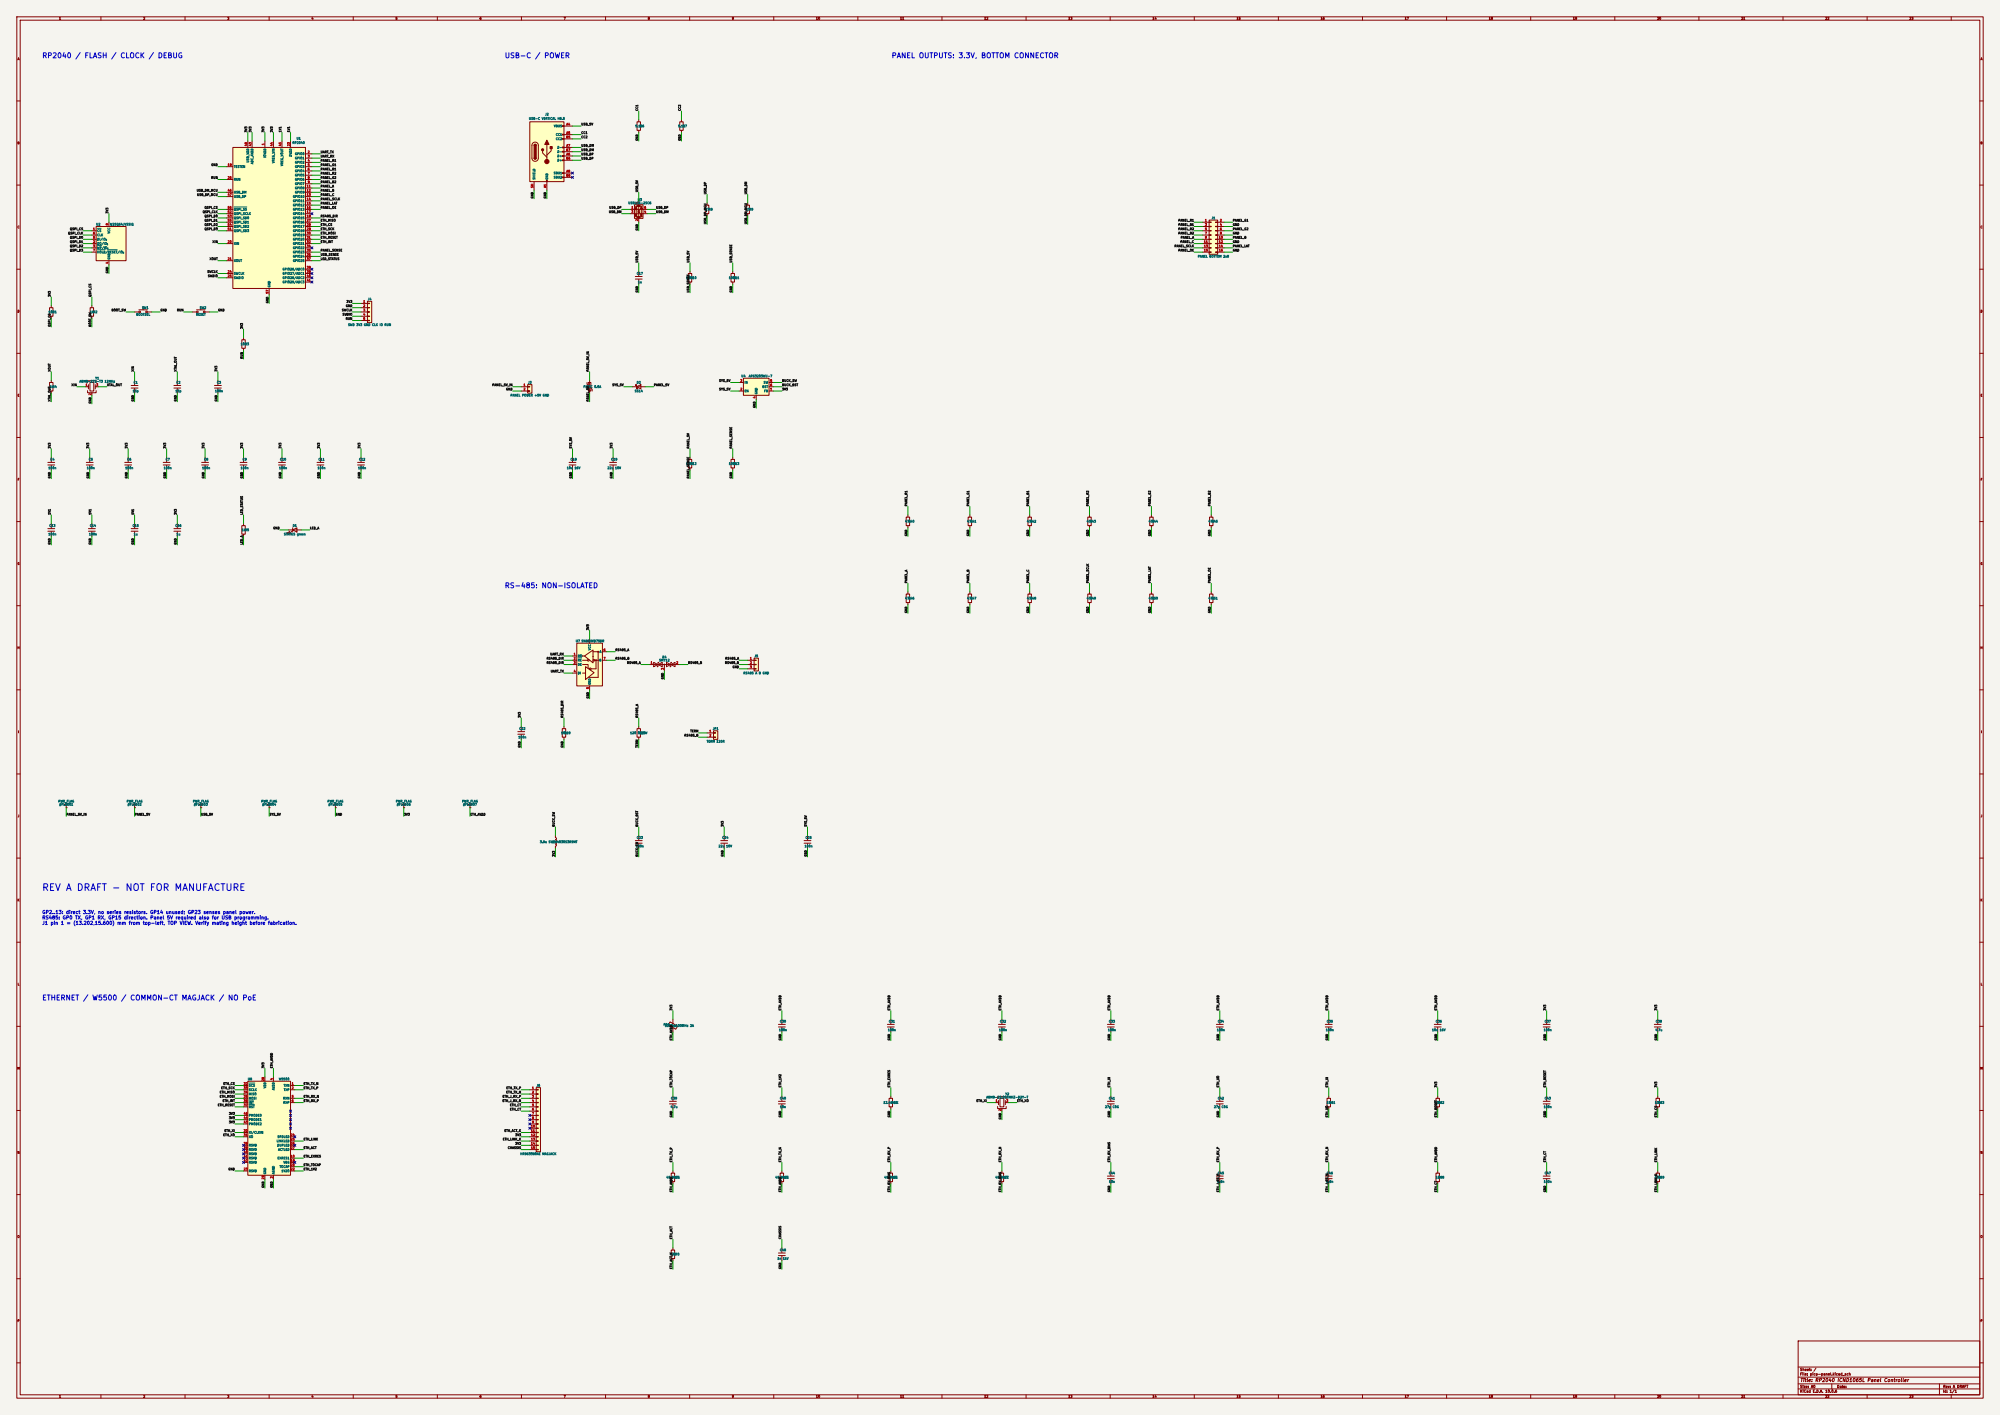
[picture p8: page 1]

4 DI/IO0 5 CLK 6 HOLD/RESET/IO3 7 VCC U2 8W25Q64JVSSIQ

SWCLK
SWDIO
SWD 3V3 GND CLK IO RUN

REV A DRAFT - NOT FOR MANUFACTURE

GP2..13: direct 3.3V, no series resistors. GP14 unused; GP23 senses panel power.
RS485: GP0 TX, GP1 RX, GP15 direction. Panel 5V required also for USB programming.
J1 pin 1 = (13.202,15.600) mm from top-left, TOP VIEW. Verify mating height before fabrication.

ETHERNET / W5500 / COMMON-CT MAGJACK / NO PoE

Size: A0 | Rev: A DRAFT
KiCad E.D.A. 10.0.6 | Id: 1/1

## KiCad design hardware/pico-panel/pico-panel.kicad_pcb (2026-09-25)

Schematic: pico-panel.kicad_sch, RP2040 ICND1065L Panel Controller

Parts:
C1, C2: 15p; C_0603_1608Metric; LCSC C1644
C3, C22, C23, C25, C43, C47: 100n; C_0603_1608Metric; LCSC C14663
C4, C5, C6, C7, C8, C9, C10, C11, C12, C13, C14, C30, C31, C32, C33, C34, C35, C37: 100n; C_0402_1005Metric; LCSC C1525
C15, C16, C17: 1u; C_0603_1608Metric; LCSC C15849
C18, C36: 10u 16V; C_0805_2012Metric; LCSC C1713
C19, C24: 22u 10V; C_0805_2012Metric; LCSC C29277
C38, C39: 4.7u; C_0603_1608Metric; LCSC C19666
C40, C44: 10n; C_0603_1608Metric; LCSC C57112
C41, C42: 27p C0G; C_0603_1608Metric; LCSC C1656
C45, C46: 6.8n; C_0603_1608Metric; LCSC C84723
C48: 1n 1kV; C_1206_3216Metric; LCSC C1941
D1: STATUS green; LED_0805_2012Metric; LCSC C2297
D2: SS14; D_SMA; LCSC C2480
D4: SM712; SOT-23; LCSC C32677
F1: PTC 0.5A; Fuse_1206_3216Metric; LCSC C70076
FB1: 120R@100MHz 2A; L_0603_1608Metric; LCSC C14709
J1: PANEL BOTTOM 2x8; PinSocket_2x08_P2.54mm_Vertical
J2: USB-C VERTICAL H6.5; USB_C_SHOUHAN_TYPE-C_16PLT-H6.5_Vertical; LCSC C3151748
J3: PANEL POWER +5V GND; PinHeader_1x02_P2.54mm_Vertical
J4: SWD 3V3 GND CLK IO RUN; PinHeader_1x05_P2.54mm_Vertical
J5: RS485 A B GND; PinHeader_1x03_P2.54mm_Vertical
J6: HR963380AE MAGJACK; RJ45_HanRun_HR963380AE_Vertical; LCSC C19724763
JP1: TERM 120R; PinHeader_1x02_P2.54mm_Vertical
L1: 3.9u SWPA4030S3R9MT; L_Sunlord_SWPA4030S; LCSC C96899
R1, R3, R18, R62, R63: 10k; R_0603_1608Metric; LCSC C25804
R2, R4, R5: 1k; R_0603_1608Metric; LCSC C21190
R6, R7: 5.1k; R_0603_1608Metric; LCSC C23186
R8, R9: 27; R_0603_1608Metric; LCSC C25190
R10, R11, R12, R13: 100k; R_0603_1608Metric; LCSC C25803
R19: 120 0.25W; R_1206_3216Metric; LCSC C17909
R40, R41, R42, R43, R44, R45, R46, R47, R48, R49, R50, R51: 47k; R_0603_1608Metric; LCSC C25819
R60: 12.4k 1%; R_0402_1005Metric; LCSC C11692
R61: 1M; R_0603_1608Metric; LCSC C22935
R64, R65, R66, R67: 49.9 1%; R_0603_1608Metric; LCSC C23185
R68: 10; R_0603_1608Metric; LCSC C22859
R69, R70: 470; R_0603_1608Metric; LCSC C23179
SW1: BOOTSEL; SW_SPST_TL3342
SW2: RESET; SW_SPST_TL3342
U1: RP2040; QFN-56-1EP_7x7mm_P0.4mm_EP3.2x3.2mm; LCSC C2040
U2: W25Q64JVSSIQ; SOIC-8_5.3x5.3mm_P1.27mm; LCSC C179171
U3: USBLC6-2SC6; SOT-23-6; LCSC C7519
U4: AP63203WU-7; TSOT-23-6; LCSC C780769
U7: SN65HVD75DR; SOIC-8_3.9x4.9mm_P1.27mm; LCSC C57928
U8: W5500; LQFP-48_7x7mm_P0.5mm; LCSC C32843
Y1: ABM8-272-T3 12MHz; Crystal_SMD_3225-4Pin_3.2x2.5mm; LCSC C20625731
Y2: ABM8-25.000MHZ-D2Y-T; Crystal_SMD_3225-4Pin_3.2x2.5mm; LCSC C179643

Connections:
1V1: C13.1, C14.1, C15.1, U1.23 (DVDD), U1.45 (VREG_VOUT), U1.50 (DVDD)
3V3: C3.1, C4.1, C5.1, C6.1, C7.1, C8.1, C9.1, C10.1, C11.1, C12.1, C16.1, C19.1, C22.1, C24.1, C37.1, C38.1, FB1.1, J4.1, J6.12, J6.14, L1.2, R1.1, R3.1, R62.1, R63.1, U1.1 (IOVDD), U1.10 (IOVDD), U1.22 (IOVDD), U1.33 (IOVDD), U1.42 (IOVDD), U1.43 (ADC_AVDD), U1.44 (VREG_VIN), U1.48 (USB_VDD), U1.49 (IOVDD), U2.8 (VCC), U4.1 (FB), U7.8 (VCC), U8.28 (VDD), U8.43 (PMODE2), U8.44 (PMODE1), U8.45 (PMODE0)
BOOT_SW: R2.2, SW1.1
BUCK_BST: C23.1, U4.6 (BST)
BUCK_SW: C23.2, L1.1, U4.5 (SW)
CC1: J2.A5 (CC1), R6.1
CC2: J2.B5 (CC2), R7.1
CHASSIS: C48.1, J6.15
ETH_1V2: C40.1, U8.22 (1V2O)
ETH_ACT: R70.1, U8.27 (ACTLED)
ETH_ACT_K: J6.11, R70.2
ETH_AVDD: C30.1, C31.1, C32.1, C33.1, C34.1, C35.1, C36.1, FB1.2, R64.2, R65.2, R68.1, U8.4 (AVDD), U8.8 (AVDD), U8.11 (AVDD), U8.15 (AVDD), U8.17 (AVDD), U8.21 (AVDD)
ETH_CS: R63.2, U1.28 (GPIO17), U8.32 (~SCS)
ETH_CT: C47.1, J6.5, J6.6, R68.2
ETH_EXRES: R60.1, U8.10 (EXRES1)
ETH_INT: U1.32 (GPIO21), U8.36 (~INT)
ETH_J_RX_N: C46.2, J6.4
ETH_J_RX_P: C45.2, J6.3
ETH_LINK: R69.1, U8.25 (LINKLED)
ETH_LINK_K: J6.13, R69.2
ETH_MISO: U1.27 (GPIO16), U8.34 (MISO)
ETH_MOSI: U1.30 (GPIO19), U8.35 (MOSI)
ETH_RESET: C43.1, R62.2, U1.31 (GPIO20), U8.37 (~RST)
ETH_RX_BIAS: C44.1, R66.2, R67.2
ETH_RX_N: C46.1, R67.1, U8.5 (RXN)
ETH_RX_P: C45.1, R66.1, U8.6 (RXP)
ETH_SCK: U1.29 (GPIO18), U8.33 (SCLK)
ETH_TOCAP: C39.1, U8.20 (TOCAP)
ETH_TX_N: J6.2, R65.1, U8.1 (TXN)
ETH_TX_P: J6.1, R64.1, U8.2 (TXP)
ETH_XI: C41.1, R61.1, U8.30 (XI/CLKIN), Y2.1
ETH_XO: C42.1, R61.2, U8.31 (XO), Y2.3
GND: C1.2, C2.2, C3.2, C4.2, C5.2, C6.2, C7.2, C8.2, C9.2, C10.2, C11.2, C12.2, C13.2, C14.2, C15.2, C16.2, C17.2, C18.2, C19.2, C22.2, C24.2, C25.2, C30.2, C31.2, C32.2, C33.2, C34.2, C35.2, C36.2, C37.2, C38.2, C39.2, C40.2, C41.2, C42.2, C43.2, C44.2, C47.2, C48.2, D1.1 (K), D4.3 (common), J1.4, J1.8, J1.12, J1.16, J2.A1 (GND), J2.A12 (GND), J2.B1 (GND), J2.B12 (GND), J2.SH (SHIELD), J3.2, J4.2, J5.3, R6.2, R7.2, R11.2, R13.2, R18.2, R40.2, R41.2, R42.2, R43.2, R44.2, R45.2, R46.2, R47.2, R48.2, R49.2, R50.2, R51.2, R60.2, SW1.2, SW2.2, U1.19 (TESTEN), U1.57 (GND), U2.4 (GND), U3.2 (GND), U4.4 (GND), U7.5 (GND), U8.3 (AGND), U8.9 (AGND), U8.14 (AGND), U8.16 (AGND), U8.19 (AGND), U8.23 (RSVD), U8.29 (GND), U8.48 (AGND), Y1.2 (G), Y1.4 (G), Y2.2 (G), Y2.4 (G)
LED_A: D1.2 (A), R5.2
LED_STATUS: R5.1, U1.37 (GPIO25)
PANEL_5V: D2.2 (A), F1.2, R12.1
PANEL_5V_IN: F1.1, J3.1
PANEL_A: J1.9, R46.1, U1.11 (GPIO8)
PANEL_B: J1.10, R47.1, U1.12 (GPIO9)
PANEL_B1: J1.3, R42.1, U1.6 (GPIO4)
PANEL_B2: J1.7, R45.1, U1.9 (GPIO7)
PANEL_C: J1.11, R48.1, U1.13 (GPIO10)
PANEL_G1: J1.2, R41.1, U1.5 (GPIO3)
PANEL_G2: J1.6, R44.1, U1.8 (GPIO6)
PANEL_LAT: J1.14, R50.1, U1.15 (GPIO12)
PANEL_OE: J1.15, R51.1, U1.16 (GPIO13)
PANEL_R1: J1.1, R40.1, U1.4 (GPIO2)
PANEL_R2: J1.5, R43.1, U1.7 (GPIO5)
PANEL_SCLK: J1.13, R49.1, U1.14 (GPIO11)
PANEL_SENSE: R12.2, R13.1, U1.35 (GPIO23)
QSPI_CLK: U1.52 (QSPI_SCLK), U2.6 (CLK)
QSPI_CS: R1.2, R2.1, U1.56 (~QSPI_SS), U2.1 (~CS)
QSPI_D0: U1.53 (QSPI_SD0), U2.5 (DI/IO_{0})
QSPI_D1: U1.55 (QSPI_SD1), U2.2 (DO/IO_{1})
QSPI_D2: U1.54 (QSPI_SD2), U2.3 (~WP/IO_{2})
QSPI_D3: U1.51 (QSPI_SD3), U2.7 (~HOLD/~RESET/IO_{3})
RS485_A: D4.1 (A1), J5.1, R19.1, U7.6 (A)
RS485_B: D4.2 (A2), J5.2, JP1.2, U7.7 (B)
RS485_DIR: R18.1, U1.18 (GPIO15), U7.2 (~RE), U7.3 (DE)
RUN: J4.5, R3.2, SW2.1, U1.26 (RUN)
SWCLK: J4.3, U1.24 (SWCLK)
SWDIO: J4.4, U1.25 (SWDIO)
SYS_5V: C18.1, C25.1, D2.1 (K), U4.2 (EN), U4.3 (IN)
TERM: JP1.1, R19.2
UART_RX: U1.3 (GPIO1), U7.1 (RO)
UART_TX: U1.2 (GPIO0), U7.4 (DI)
USB_5V: C17.1, J2.A4 (VBUS), J2.A9 (VBUS), J2.B4 (VBUS), J2.B9 (VBUS), R10.1, U3.5 (VBUS)
USB_DM: J2.A7 (D-), J2.B7 (D-), R9.1, U3.3 (I/O2), U3.4 (I/O2)
USB_DM_MCU: R9.2, U1.46 (USB_DM)
USB_DP: J2.A6 (D+), J2.B6 (D+), R8.1, U3.1 (I/O1), U3.6 (I/O1)
USB_DP_MCU: R8.2, U1.47 (USB_DP)
USB_SENSE: R10.2, R11.1, U1.36 (GPIO24)
XIN: C1.1, U1.20 (XIN), Y1.1
XOUT: R4.1, U1.21 (XOUT)
XTAL_OUT: C2.1, R4.2, Y1.3

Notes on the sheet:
ETHERNET / W5500 / COMMON-CT MAGJACK / NO PoE
RP2040 / FLASH / CLOCK / DEBUG
USB-C / POWER
PANEL OUTPUTS: 3.3V, BOTTOM CONNECTOR
RS-485: NON-ISOLATED
REV A DRAFT - NOT FOR MANUFACTURE
GP2..13: direct 3.3V, no series resistors. GP14 unused; GP23 senses panel power. RS485: GP0 TX, GP1 RX, GP15 direction. Panel 5V required also for USB programming. J1 pin 1 = (13.202,15.600) mm from top-left, TOP VIEW. Verify mating height before fabrication.

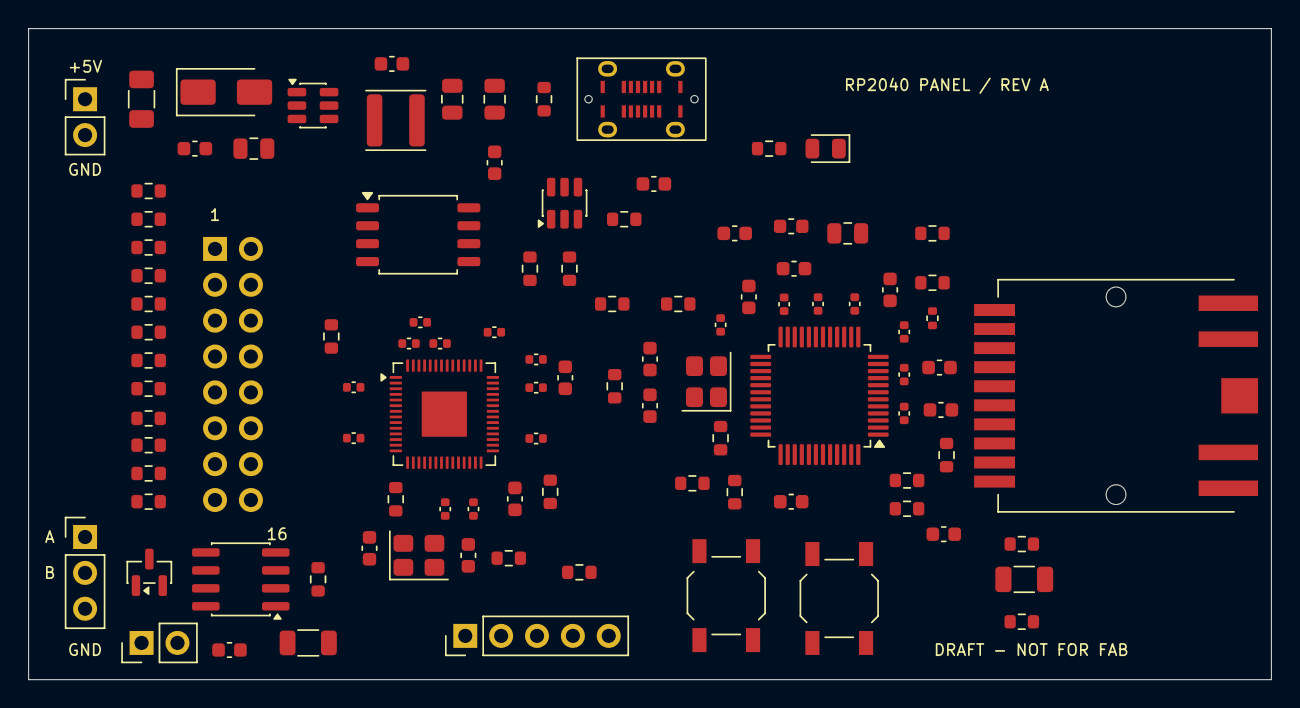
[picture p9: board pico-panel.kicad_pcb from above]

Board: 2 copper layers, 88.0 x 46.1 mm, 103 parts (1 on the bottom side), 75 nets, no tracks yet.

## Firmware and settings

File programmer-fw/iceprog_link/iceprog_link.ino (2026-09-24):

/*
 * iceprog2 - iCE40 SPI-flash programmer for the OLIMEXINO-32U4 (ATmega32u4).
 *
 * Replaces Olimex's iceprog.ino, whose frame parser is off by one:
 *   readSerialFrame() returns whatever readBytesUntil() managed to collect and
 *   decodeFrame() then does rxframe[0] = rxframe[1], so a minimal <CMD><FCS>FEND
 *   frame puts the checksum in the command slot, the checksum never balances and
 *   the board answers nothing at all. Diagnostics confirmed the USB CDC link and
 *   the sketch itself were fine - only the parsing was broken.
 *
 * This sketch parses framing byte by byte, so it does not care how the host
 * chunks its writes. It talks to the W25Q16 directly over SPI instead of going
 * through the SPIFlash library - fewer moving parts, and the whole flash
 * protocol fits in a page of code.
 *
 * Wire format, both directions:
 *   FEND CMD <escaped data...> FCS FEND
 *   FCS chosen so (CMD + data + FCS) & 0xFF == 0xFF
 *   FEND/FESC inside data escaped as FESC TFEND / FESC TFESC
 *
 * Commands (same opcodes as the Olimex tool, but a full 3-byte flash address):
 *   0xEE ENTER     -> READY          hold CRESET low so the FPGA becomes an SPI
 *                                    pass-through to the flash; CDONE must read 0
 *   0xEF EXIT      -> READY          release CRESET, FPGA boots from flash
 *   0x9F READ_ID   -> READ_ID mfr mem cap
 *   0xC7 BULK_ERASE-> READY 0xC7
 *   0xD8 SEC_ERASE a_hi a_mid a_lo                  -> READY 0xC7
 *   0x02 PROG      a_hi a_mid a_lo <up to 256 bytes> -> READY 0xC7
 *   0x03 READ      a_hi a_mid a_lo  -> READ page_hi page_lo <256 bytes>
 *
 * The flash is NOT wired to PGM1 directly: PGM1 pin 7/8/9/10 are the FPGA's SPI
 * pins, and the configuration logic only forwards them to the flash while the
 * FPGA is held in reset (CRESET low). Talking to the flash with CRESET high
 * yields FF FF FF for every byte.
 *
 * Host side: ../../../iceprog.py
 */

#include <SPI.h>

#define CS      13              // flash chip select on the PGM1 / UEXT bus
#define CDONE    3
#define RESET    2

#define FEND  0xC0
#define FESC  0xDB
#define TFEND 0xDC
#define TFESC 0xDD

#define C_READ_ID    0x9F
#define C_BULK_ERASE 0xC7
#define C_SEC_ERASE  0xD8
#define C_PROG       0x02
#define C_READ       0x03
#define C_ENTER      0xEE
#define C_EXIT       0xEF
#define C_PING       0xF0
#define C_DRIVE      0xF1
#define C_LISTEN     0xF2
#define C_SAMPLE     0xF3
#define C_SPI        0xF4
#define C_BITBANG    0xF5
#define C_UARTRX     0xF6
#define C_STATUS     0xF7
#define C_UART1      0xF8
#define C_SEND1      0xF9
#define C_PARK       0xFA
#define C_BLINK2     0xFB
#define C_PINS       0xFC
#define C_WATCH      0xFD
#define C_UARTCFG    0xE0
#define C_UARTXFER   0xE1

#define R_READY    0x44
#define R_READ     0x03
#define R_READ_ID  0x9F
#define R_ERROR    0x45
#define R_PONG     0xF0
#define R_UART     0xF2
#define R_SAMPLE   0xF3
#define R_SPI      0xF4
#define R_BITBANG  0xF5
#define R_UARTRX   0xF6
#define R_STATUS   0xF7
#define R_UART1    0xF8

// ---- software UART receiver on MISO / D14 (PB3 = ACO) -----------------------
//
// The FPGA transmits on PGM1 pin 8, which is the same wire the ATmega calls MISO.
// The hardware USART cannot be pointed at PB3 (its RX pin is PD2) and Timer3
// belongs to the USB stack, so Timer1 provides the sampling clock.
//
// The link is slow on purpose: 15 cm of unshielded IDC ribbon between two boards,
// with no ground between the signal wires. SPI at 2 MHz and even hand-bitbanging
// came back corrupted; 9600 baud (104 us per bit) is what the cable tolerates.
// The link is slow on purpose: 15 cm of unshielded IDC ribbon between two boards,
// with no ground between the signal wires. SPI at 2 MHz and even hand-bitbanging
// came back corrupted; 9600 baud (104 us per bit) is what the cable tolerates.
//
// One sample per bit, right in the middle. The ISR must stay tiny: Timer1 fires
// every 104 us and the USB stack needs its share of the CPU. An earlier attempt
// used 457 kHz for 3x oversampling and wedged the board completely.
//
//   bit period = 1667 clocks at 16 MHz, so OCR1A = 1666
#define UART_TICKS_PER_BIT 1667
#define UART_RX_MAX 96

static volatile uint8_t  urx_buf[UART_RX_MAX];
static volatile uint8_t  urx_len = 0;
static volatile uint8_t  urx_bit = 0;       // 0 = hunting for a start bit
static volatile uint8_t  urx_shift = 0;
static volatile bool     urx_active = false;
static volatile bool     urx_done = false;

ISR(TIMER1_COMPA_vect) {
  if (!urx_active) return;

  if (urx_bit == 0) {
    // idle: a low level is a start bit
    if ((PINB & _BV(PB3)) == 0) {
      urx_bit = 1;
      urx_shift = 0;
    }
    return;
  }

  if (urx_bit <= 8) {
    if (PINB & _BV(PB3)) urx_shift |= _BV(urx_bit - 1);   // LSB first
    urx_bit++;
    return;
  }

  // the stop bit ends the byte
  if (urx_len < UART_RX_MAX) urx_buf[urx_len++] = urx_shift;
  urx_bit = 0;
  if (urx_len >= UART_RX_MAX) { urx_active = false; urx_done = true; }
}

#define PAGE_SIZE 256

static uint8_t rxbuf[PAGE_SIZE + 8];
static uint8_t txbuf[2 * (PAGE_SIZE + 8)];
static uint16_t txlen;

// ---------------------------------------------------------------- SPI helpers

static inline void csLow()  { digitalWrite(CS, LOW); }
static inline void csHigh() { digitalWrite(CS, HIGH); }

static uint8_t spiXfer(uint8_t b) { return SPI.transfer(b); }

static void flashPowerUp() {
  csLow();
  spiXfer(0xAB);            // release power-down / read device ID
  spiXfer(0x00); spiXfer(0x00); spiXfer(0x00);
  csHigh();
  delayMicroseconds(50);
}

static uint8_t flashStatus() {
  csLow();
  spiXfer(0x05);            // read status register 1
  uint8_t s = spiXfer(0x00);
  csHigh();
  return s;
}

static void flashWaitReady() {
  uint32_t guard = 0;
  while ((flashStatus() & 0x01) && guard++ < 6000000UL) { }
}

static void flashWriteEnable() {
  csLow();
  spiXfer(0x06);
  csHigh();
}

static uint32_t flashJedecId() {
  csLow();
  spiXfer(0x9F);
  uint32_t id = (uint32_t)spiXfer(0x00) << 16;
  id |= (uint32_t)spiXfer(0x00) << 8;
  id |= (uint32_t)spiXfer(0x00);
  csHigh();
  return id;
}

static void flashBulkErase() {
  flashWriteEnable();
  csLow();
  spiXfer(0xC7);
  csHigh();
  flashWaitReady();
}

static void flashSectorErase(uint32_t addr) {
  flashWriteEnable();
  csLow();
  spiXfer(0x20);            // 4 kB sector erase
  spiXfer((addr >> 16) & 0xFF);
  spiXfer((addr >> 8) & 0xFF);
  spiXfer(addr & 0xFF);
  csHigh();
  flashWaitReady();
}

static void flashPageProgram(uint32_t addr, const uint8_t *data, uint16_t len) {
  flashWriteEnable();
  csLow();
  spiXfer(0x02);
  spiXfer((addr >> 16) & 0xFF);
  spiXfer((addr >> 8) & 0xFF);
  spiXfer(addr & 0xFF);
  for (uint16_t i = 0; i < len; i++) spiXfer(data[i]);
  csHigh();
  flashWaitReady();
}

static void flashRead(uint32_t addr, uint8_t *out, uint16_t len) {
  csLow();
  spiXfer(0x03);
  spiXfer((addr >> 16) & 0xFF);
  spiXfer((addr >> 8) & 0xFF);
  spiXfer(addr & 0xFF);
  for (uint16_t i = 0; i < len; i++) out[i] = spiXfer(0x00);
  csHigh();
}

// -------------------------------------------------------------- frame sending

static void txReset(uint8_t cmd) {
  txbuf[0] = FEND;
  txbuf[1] = cmd;
  txlen = 2;
}

static void txByte(uint8_t b) {
  if (b == FEND) {
    txbuf[txlen++] = FESC;
    txbuf[txlen++] = TFEND;
  } else if (b == FESC) {
    txbuf[txlen++] = FESC;
    txbuf[txlen++] = TFESC;
  } else {
    txbuf[txlen++] = b;
  }
}

static void txSend(uint8_t fcs) {
  txByte((uint8_t)(0xFF - fcs));
  txbuf[txlen++] = FEND;
  Serial.write(txbuf, txlen);
}

static void sendReady() {
  txReset(R_READY);
  txSend(R_READY);
}

static void sendError() {
  txReset(R_ERROR);
  txSend(R_ERROR);
}

static void sendId(uint32_t id) {
  txReset(R_READ_ID);
  uint8_t s = R_READ_ID;
  txByte((id >> 16) & 0xFF); s += (id >> 16) & 0xFF;
  txByte((id >> 8) & 0xFF);  s += (id >> 8) & 0xFF;
  txByte(id & 0xFF);         s += id & 0xFF;
  txSend(s);
}

// ------------------------------------------------------------- frame receiving

// Parser state is kept across calls: a 260-byte PROG frame does not arrive in one
// go over USB CDC, and the stock sketch's "start from scratch every time" approach
// lost everything that had already been read.
static uint16_t rxlen;
static bool rxInFrame;
static bool rxEscaped;

// Consumes whatever is in the serial buffer. When a complete, checksum-valid frame
// has been assembled it lands in rxbuf (rxbuf[0] = command) and true is returned.
static bool pollFrame() {
  while (Serial.available()) {
    uint8_t b = Serial.read();

    if (b == FEND) {
      if (rxInFrame && rxlen > 1) {
        uint8_t sum = 0;
        for (uint16_t i = 0; i < rxlen; i++) sum += rxbuf[i];
        if (sum == 0xFF) {
          rxlen--;                 // drop the checksum byte, keep cmd+data
          rxInFrame = false;       // next FEND starts a fresh frame
          return true;
        }
      }
      rxlen = 0;
      rxInFrame = true;
      rxEscaped = false;
      continue;
    }

    if (!rxInFrame) continue;      // wait for the opening FEND

    if (b == FESC) { rxEscaped = true; continue; }
    if (rxEscaped) {
      b = (b == TFEND) ? FEND : (b == TFESC) ? FESC : b;
      rxEscaped = false;
    }
    if (rxlen < sizeof(rxbuf)) rxbuf[rxlen++] = b;
  }
  return false;
}

// ---------------------------------------------------------------------- setup

void setup() {
  pinMode(CDONE, INPUT);
  pinMode(RESET, OUTPUT);
  pinMode(CS, OUTPUT);
  csHigh();

  Serial.begin(230400);
  unsigned long t0 = millis();
  while (!Serial && (millis() - t0) < 4000) { }

  SPI.begin();
  SPI.setClockDivider(SPI_CLOCK_DIV2);   // 8 MHz
  SPI.setDataMode(SPI_MODE0);

  // D1 is the console transmit line towards the FPGA. Park it as an output at the
  // idle level from the very start: left as an input it floats, and a floating wire
  // into the FPGA yields nothing but noise - which showed up as both status LEDs
  // blinking slowly for no reason.
  pinMode(1, OUTPUT);
  digitalWrite(1, HIGH);

  // Leave the FPGA alone: it boots from flash on its own. The host opens the SPI
  // pass-through with ENTER when it actually wants to talk to the flash.
  csHigh();
  digitalWrite(RESET, HIGH);
  delay(50);
}

// ---- console line watcher ---------------------------------------------------
// Samples D0 and D1 every 2 ms and records every change, so a test run that lasts
// as long as the operator likes can be read back in slices without missing
// anything. The host polls it and timestamps each batch as it arrives.
#define WATCH_MAX 512
static uint8_t  watch_buf[WATCH_MAX];
static uint16_t watch_len = 0;
static bool     watch_on = false;
static uint8_t  watch_last = 0xFF;
static unsigned long watch_last_ms = 0;

static void watch_poll() {
  if (!watch_on) return;
  unsigned long now = millis();
  if (now - watch_last_ms < 2) return;
  watch_last_ms = now;

  uint8_t now_levels = (uint8_t)((PIND >> 2) & 0x03);   // bit0 = D0, bit1 = D1
  if (now_levels != watch_last) {
    watch_last = now_levels;
    if (watch_len < WATCH_MAX) watch_buf[watch_len++] = now_levels;
  }
}

// ----------------------------------------------------------------------- loop

// Bring up the hardware USART on D0 (receive) and D1 (transmit) once, and leave it
// running. Both console commands share this: two independent bring-ups meant the
// second one reset the direction that was already working.
static bool uart1_up = false;
static void uart1_ensure() {
  if (uart1_up && (UCSR1B & _BV(RXEN1)) && (UCSR1B & _BV(TXEN1))) return;
  SPI.end();
  pinMode(SCK, INPUT);
  pinMode(MOSI, INPUT);
  pinMode(MISO, INPUT);
  pinMode(0, INPUT);          // D0 = PD2 = RXD1
  digitalWrite(0, LOW);       // no pull-up on the receive line
  Serial1.begin(4800);
  uart1_up = true;
  delay(10);
}

void loop() {
  watch_poll();       // record any change on D0/D1 while a test is running

  if (!pollFrame()) { delayMicroseconds(200); return; }

  uint16_t n = rxlen;
  uint8_t cmd = rxbuf[0];

  switch (cmd) {
    case C_UARTCFG: {
      if (n != 5) { sendError(); break; }
      uint32_t baud = ((uint32_t)rxbuf[1] << 24) | ((uint32_t)rxbuf[2] << 16)
                    | ((uint32_t)rxbuf[3] << 8) | rxbuf[4];
      if (baud < 1200 || baud > 2000000UL) { sendError(); break; }
      watch_on = false;
      Serial1.end();
      pinMode(0, INPUT); digitalWrite(0, LOW);
      pinMode(1, OUTPUT); digitalWrite(1, LOW);
      delay(20);  // Break rearms the FPGA auto-baud receiver.
      digitalWrite(1, HIGH); delay(2);
      Serial1.begin(baud); uart1_up = true;
      Serial1.write(0x55); Serial1.flush(); delay(25);
      while (Serial1.available()) Serial1.read();
      txReset(C_UARTCFG);
      uint8_t hi = UBRR1H, lo = UBRR1L, fast = (UCSR1A & _BV(U2X1)) ? 1 : 0;
      txByte(hi); txByte(lo); txByte(fast);
      txSend((uint8_t)(C_UARTCFG + hi + lo + fast));
      break;
    }

    case C_UARTXFER: {
      // Keep the complete echo below Arduino's 64-byte RX ring capacity.
      uint8_t count = n > 1 ? n - 1 : 0;
      if (!uart1_up || count == 0 || count > 48) { sendError(); break; }
      while (Serial1.available()) Serial1.read();
      Serial1.write(rxbuf + 1, count);
      Serial1.flush();
      uint8_t got[48], used = 0;
      unsigned long start = millis();
      while (used < count && millis() - start < 250) {
        if (Serial1.available()) got[used++] = Serial1.read();
      }
      txReset(C_UARTXFER);
      uint8_t fcs = C_UARTXFER + used;
      txByte(used);
      for (uint8_t i = 0; i < used; ++i) { txByte(got[i]); fcs += got[i]; }
      txSend(fcs);
      break;
    }

    case C_PING:
      txReset(R_PONG);
      txSend(R_PONG);
      break;

    case C_DRIVE: {
      // Hardware probe support: drive the PGM1 lines and let an FPGA design
      // observe them. Payload: seconds(1) then a sequence of
      //   line(1) value(1) ms(1)
      // Lines: 0 = SCK (D15), 1 = MOSI/SDI (D16). SS_B (D13) is left alone:
      // it doubles as the flash chip select and is only safe to move while the
      // flash is idle.
      if (n < 2) { sendError(); break; }

      uint8_t seconds = rxbuf[1];
      uint16_t idx = 2;
      while (idx + 2 < n) {
        uint8_t line = rxbuf[idx];
        uint8_t val = rxbuf[idx + 1] ? HIGH : LOW;
        uint8_t ms = rxbuf[idx + 2];
        idx += 3;

        uint8_t pin = (line == 0) ? SCK : MOSI;
        pinMode(pin, OUTPUT);
        digitalWrite(pin, val);
        delay(ms);
      }

      // leave the lines low and hand them back to the SPI peripheral
      pinMode(SCK, OUTPUT);  digitalWrite(SCK, LOW);
      pinMode(MOSI, OUTPUT); digitalWrite(MOSI, LOW);
      SPI.begin();
      delay((uint16_t)seconds * 1000);
      sendReady();
      break;
    }

    case C_SAMPLE: {
      // Sample the MISO line (PB3) repeatedly and report the levels, so a line
      // that is stuck can be told apart from one that is actually toggling.
      // Payload: count(1) delay_ms(1) line(1)  - line 0 = MISO/D14, 1 = MOSI/D16
      uint8_t count = (n >= 2) ? rxbuf[1] : 16;
      uint8_t delay_ms = (n >= 3) ? rxbuf[2] : 100;
      uint8_t line = (n >= 4) ? rxbuf[3] : 0;
      if (count == 0) count = 16;
      if (count > 32) count = 32;

      SPI.end();
      pinMode(SCK, INPUT);
      pinMode(MOSI, INPUT);
      pinMode(MISO, INPUT);
      pinMode(CS, INPUT);               // D13 = PB7, wired to PGM1 pin 10
      digitalWrite(MISO, LOW);
      digitalWrite(MOSI, LOW);
      digitalWrite(CS, LOW);

      uint8_t buf[32];
      uint8_t levels = 0;
      for (uint8_t i = 0; i < count; i++) {
        uint8_t v;
        // line selects which wire to look at:
        //   0 = D14 (PB3), the host's MISO   -> PGM1 pin 8 (FPGA pin 45)
        //   1 = D16 (PB2), the host's MOSI   -> PGM1 pin 7 (FPGA pin 46)
        //   2 = D13 (PB7), the flash CS      -> PGM1 pin 10 (FPGA pin 49)
        //   3 = D15 (PB1), the host's SCK    -> PGM1 pin 9 (FPGA pin 48)
        //   4 = D1  (PD3), the console TX    -> GPIO1 pin 14 (FPGA pin 37)
        if      (line == 0) v = (PINB & _BV(PB3)) ? 1 : 0;
        else if (line == 1) v = (PINB & _BV(PB2)) ? 1 : 0;
        else if (line == 2) v = (PINB & _BV(PB7)) ? 1 : 0;
        else if (line == 3) v = (PINB & _BV(PB1)) ? 1 : 0;
        else                v = (PIND & _BV(PD3)) ? 1 : 0;
        buf[i] = v;
        if (v) levels |= _BV(i % 8);
        // delay_ms == 0 means "as fast as possible", which is what catching a
        // 9600 baud frame (104 us per bit) needs
        if (delay_ms) delay(delay_ms);
        else delayMicroseconds(20);
      }

      txReset(R_SAMPLE);
      uint8_t fcs = R_SAMPLE;
      txByte(count); fcs += count;
      txByte(levels); fcs += levels;
      for (uint8_t i = 0; i < count; i++) { txByte(buf[i]); fcs += buf[i]; }
      txSend(fcs);

      SPI.begin();
      break;
    }

    case C_STATUS: {
      // Report the strap pins so a silent line can be told apart from a silent
      // FPGA: CDONE high means the bitstream was accepted and the design is
      // running, so whatever it drives is its own business.
      uint8_t cdone = digitalRead(CDONE) ? 1 : 0;
      uint8_t reset = digitalRead(RESET) ? 1 : 0;
      uint8_t miso  = (PINB & _BV(PB3)) ? 1 : 0;
      txReset(R_STATUS);
      uint8_t fcs = R_STATUS;
      txByte(cdone); fcs += cdone;
      txByte(reset); fcs += reset;
      txByte(miso);  fcs += miso;
      txSend(fcs);
      break;
    }

    case C_SEND1: {
      // Send bytes out of the hardware USART on D1 (PD3 = TXD1) towards the FPGA.
      // Payload: the bytes to send. Receiver is brought up once and left running,
      // for the same reason as in C_UART1.
      uart1_ensure();

      for (uint8_t i = 1; i < n; i++) Serial1.write(rxbuf[i]);
      Serial1.flush();

      sendReady();
      break;
    }

    case C_PARK: {
      // Drive the console transmit line to a fixed level, bypassing the USART.
      // Payload: level(1). Reading the level back at the other end of the wire
      // separates a wiring fault from a UART fault: if the far end follows this,
      // the connection is sound and any remaining problem is in the framing.
      uint8_t lvl = (n >= 2) ? rxbuf[1] : 0;
      Serial1.end();
      pinMode(1, OUTPUT);
      digitalWrite(1, lvl ? HIGH : LOW);
      sendReady();
      break;
    }

    case C_WATCH: {
      // Payload: cmd(1)
      //   0 = start watching (D0 and D1 become inputs, buffer cleared)
      //   1 = read out everything recorded so far (buffer is cleared)
      //   2 = stop
      uint8_t sub = (n >= 2) ? rxbuf[1] : 0;

      if (sub == 0) {
        Serial1.end();
        pinMode(0, INPUT);
        pinMode(1, INPUT);
        digitalWrite(0, LOW);        // no pull-ups: the FPGA drives these
        digitalWrite(1, LOW);
        watch_len = 0;
        watch_last = (uint8_t)((PIND >> 2) & 0x03);
        watch_last_ms = millis();
        watch_on = true;
        sendReady();
        break;
      }

      if (sub == 2) {
        watch_on = false;
        sendReady();
        break;
      }

      // sub == 1: hand over the recording
      uint8_t count = (watch_len > 120) ? 120 : (uint8_t)watch_len;
      txReset(R_SAMPLE);
      uint8_t fcs = R_SAMPLE;
      txByte(count); fcs += count;
      for (uint8_t i = 0; i < count; i++) { txByte(watch_buf[i]); fcs += watch_buf[i]; }
      txSend(fcs);

      // shift the remainder down
      for (uint16_t i = count; i < watch_len; i++) watch_buf[i - count] = watch_buf[i];
      watch_len -= count;
      break;
    }

    case C_PINS: {
      // Report the raw port D registers around the console pins.
      //   DDD2 = 1 means D0 is configured as an output
      //   PORTD bit 2 is what we are asking it to drive
      //   PIND bit 2 is what the pin actually reads
      // That separates "the pin is still an input" from "the pin is driven but
      // something on the board is holding it".
      // Payload: mode(1) - 0 report, 1 both low, 2 both high,
      //                   3 D0 high + D1 low, 4 D0 low + D1 high
      uint8_t mode = (n >= 2) ? rxbuf[1] : 0;
      if (mode) {
        Serial1.end();
        pinMode(0, OUTPUT);
        pinMode(1, OUTPUT);
        switch (mode) {
          case 1:  digitalWrite(0, LOW);  digitalWrite(1, LOW);  break;
          case 2:  digitalWrite(0, HIGH); digitalWrite(1, HIGH); break;
          case 3:  digitalWrite(0, HIGH); digitalWrite(1, LOW);  break;
          case 4:  digitalWrite(0, LOW);  digitalWrite(1, HIGH); break;
          default: break;
        }
        delay(5);
      }

      txReset(R_STATUS);
      uint8_t fcs = R_STATUS;
      txByte(DDRD);  fcs += DDRD;
      txByte(PORTD); fcs += PORTD;
      txByte(PIND);  fcs += PIND;
      txSend(fcs);
      break;
    }

    case C_BLINK2: {
      // Drive D0 and D1 as plain outputs and blink them one after the other.
      // With the wire2 design in the FPGA - nothing but two wires to the LEDs -
      // this is the simplest possible end-to-end check: D0 blinking lights LED1,
      // D1 blinking lights LED2. Whichever one stays dark points at the wire or
      // the pin responsible.
      Serial1.end();
      pinMode(0, OUTPUT);
      pinMode(1, OUTPUT);
      digitalWrite(0, LOW);
      digitalWrite(1, LOW);

      sendReady();                  // answer first, then perform the show

      for (uint8_t round = 0; round < 3; round++) {
        for (uint8_t i = 0; i < 5; i++) {       // five blinks on D0
          digitalWrite(0, HIGH); delay(200);
          digitalWrite(0, LOW);  delay(200);
        }
        delay(800);
        for (uint8_t i = 0; i < 5; i++) {       // five blinks on D1
          digitalWrite(1, HIGH); delay(200);
          digitalWrite(1, LOW);  delay(200);
        }
        delay(800);
      }
      break;
    }
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

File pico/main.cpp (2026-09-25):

#include <cstdio>
#include <cstdint>
#include "pico/stdlib.h"
#include "pico/binary_info.h"
#include "pico/stdio_usb.h"
#include "pico/stdio/driver.h"
#include "hardware/clocks.h"
#include "hardware/dma.h"
#include "hardware/pio.h"
#include "hardware/regs/pio.h"
#include "hardware/irq.h"
#include "hardware/sync.h"
#include "video_frame.h"
#include "panel_wave.pio.h"
#include "wave_data.h"

static constexpr uint BASE_PIN = 2;
static constexpr uint PIN_COUNT = 12;
static constexpr uint LED_PIN = 25;
struct alignas(16) DmaBlock {
    uint32_t read_address, write_address, count, control;
};
static DmaBlock blocks[PLAN_COUNT];
static DmaBlock idle_plan[1], update_plan[38];
static uint32_t next_plan;
static uint8_t frames[2][video::FRAME_BYTES];
static int data_channel;
// Only the DMA IRQ writes STARTUP -> IDLE, QUEUED -> RUNNING -> COMPLETE.
enum Phase { STARTUP, IDLE, QUEUED, RUNNING, COMPLETE };
static volatile Phase phase = STARTUP;

static void __not_in_flash_func(dma_complete)() {
    dma_channel_acknowledge_irq0(data_channel);
    if (phase == STARTUP) phase = IDLE;
    else if (phase == QUEUED) {
        next_plan = uint32_t(uintptr_t(idle_plan));
        __dmb();
        phase = RUNNING;
    } else if (phase == RUNNING) phase = COMPLETE;
}

int main() {
    // Match the FPGA's 320 ns half-clock exactly, without overclocking.
    set_sys_clock_khz(125000, true);
    stdio_init_all();
    bi_decl(bi_program_description("YD-RP2040 ICND1065L USB video RAM"));
    bi_decl(bi_1pin_with_name(11, "Panel SCLK"));
    gpio_init(LED_PIN);
    gpio_set_dir(LED_PIN, GPIO_OUT);
    PIO pio = pio0;
    uint sm = pio_claim_unused_sm(pio, true);
    uint offset = pio_add_program(pio, &panel_wave_program);
    pio_sm_config config = panel_wave_program_get_default_config(offset);
    sm_config_set_out_pins(&config, BASE_PIN, PIN_COUNT);
    sm_config_set_out_shift(&config, true, true, 16);
    sm_config_set_fifo_join(&config, PIO_FIFO_JOIN_TX);
    sm_config_set_clkdiv(&config, 1.0f);
    for (uint pin=BASE_PIN; pin<BASE_PIN+PIN_COUNT; ++pin) {
        pio_gpio_init(pio, pin);
        gpio_set_drive_strength(pin, GPIO_DRIVE_STRENGTH_4MA);
        gpio_set_slew_rate(pin, GPIO_SLEW_RATE_SLOW);
    }
    pio_sm_init(pio, sm, offset, &config);
    pio_sm_set_pins_with_mask(pio, sm, 0, ((1u<<PIN_COUNT)-1)<<BASE_PIN);
    pio_sm_set_consecutive_pindirs(pio, sm, BASE_PIN, PIN_COUNT, true);

    int data = dma_claim_unused_channel(true);
    data_channel = data;
    int control = dma_claim_unused_channel(true);
    int loop = dma_claim_unused_channel(true);
    dma_channel_config dc = dma_channel_get_default_config(data);
    channel_config_set_transfer_data_size(&dc, DMA_SIZE_16);
    channel_config_set_read_increment(&dc, true);
    channel_config_set_write_increment(&dc, false);
    channel_config_set_dreq(&dc, pio_get_dreq(pio, sm, true));
    channel_config_set_high_priority(&dc, true);
    channel_config_set_chain_to(&dc, control);
    for (size_t i=0; i<PLAN_COUNT; ++i) {
        if (i == PLAN_COUNT-1) channel_config_set_chain_to(&dc, loop);
        channel_config_set_irq_quiet(&dc, i != PLAN_COUNT-1);
        blocks[i] = {uint32_t(uintptr_t(startup_plan[i].samples)),
                     uint32_t(uintptr_t(&pio->txf[sm])), startup_plan[i].count,
                     channel_config_get_ctrl_value(&dc)};
    }

    auto descriptor = [&](const uint16_t *samples, uint32_t count, bool last, bool interrupt) {
        channel_config_set_chain_to(&dc, last ? loop : control);
        channel_config_set_irq_quiet(&dc, !interrupt);
        return DmaBlock{uint32_t(uintptr_t(samples)), uint32_t(uintptr_t(&pio->txf[sm])),
                        count, channel_config_get_ctrl_value(&dc)};
    };
    idle_plan[0] = descriptor(wave_hold, 2048, true, false);
    // Match the proven FPGA refresh: gap, init0, upload, 32768 hold clocks,
    // gap, init1, upload. The old image remains stored while USB receives.
    unsigned n = 0;
    update_plan[n++] = descriptor(wave_gap, 625, false, false);
    update_plan[n++] = descriptor(wave_init_0, 1414, false, true);
    update_plan[n++] = descriptor(wave_visible, video::WAVE_SAMPLES, false, false);
    for (unsigned i = 0; i < 32; ++i)
        update_plan[n++] = descriptor(wave_hold, 2048, false, false);
    update_plan[n++] = descriptor(wave_gap, 625, false, false);
    update_plan[n++] = descriptor(wave_init_1, 1414, false, false);
    update_plan[n++] = descriptor(wave_visible, video::WAVE_SAMPLES, true, true);
    hard_assert(n == 38);

    // Four-word descriptors update READ_ADDR/WRITE_ADDR/COUNT/CTRL_TRIG.
    dma_channel_config cc = dma_channel_get_default_config(control);
    channel_config_set_transfer_data_size(&cc, DMA_SIZE_32);
    channel_config_set_read_increment(&cc, true);
    channel_config_set_write_increment(&cc, true);
    channel_config_set_ring(&cc, true, 4);
    channel_config_set_high_priority(&cc, true);
    dma_channel_configure(control, &cc, &dma_hw->ch[data].read_addr, blocks, 4, false);

    // The hardware loop selects a complete descriptor plan at a scan boundary.
    next_plan = uint32_t(uintptr_t(idle_plan));
    dma_channel_config lc = dma_channel_get_default_config(loop);
    channel_config_set_transfer_data_size(&lc, DMA_SIZE_32);
    channel_config_set_read_increment(&lc, false);
    channel_config_set_write_increment(&lc, false);
    channel_config_set_high_priority(&lc, true);
    dma_channel_configure(loop, &lc, &dma_hw->ch[control].al3_read_addr_trig, &next_plan, 1, false);
    irq_set_exclusive_handler(DMA_IRQ_0, dma_complete);
    dma_channel_set_irq0_enabled(data, true);
    irq_set_enabled(DMA_IRQ_0, true);
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

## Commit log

2026-09-24 Add verified FPGA LED panel, SRAM framebuffer and UART tools
    [SHA256.csv]
2026-09-25 Add verified RP2040 Pico PIO DMA panel driver and firmware
2026-09-25 Publish RP2040 panel controller PCB design and routing trial
    [BOM.csv, before-width-normalization.kicad_pcb, ethernet-fit-plot.kicad_pcb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]
2026-09-25 Add Pico USB video RAM streaming, timed GIF playlists and examples
